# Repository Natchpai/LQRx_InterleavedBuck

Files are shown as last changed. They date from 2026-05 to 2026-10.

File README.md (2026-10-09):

# Digitally Controlled Interleaved Buck Converter




Digitally controlled **2-Phase Interleaved Synchronous Buck Converter** utilizing a state-space **Linear Quadratic Regulator** 
Optimized for time-critical embedded deployment at a switching frequency of **200 kHz** using the STM32G474 microcontroller.

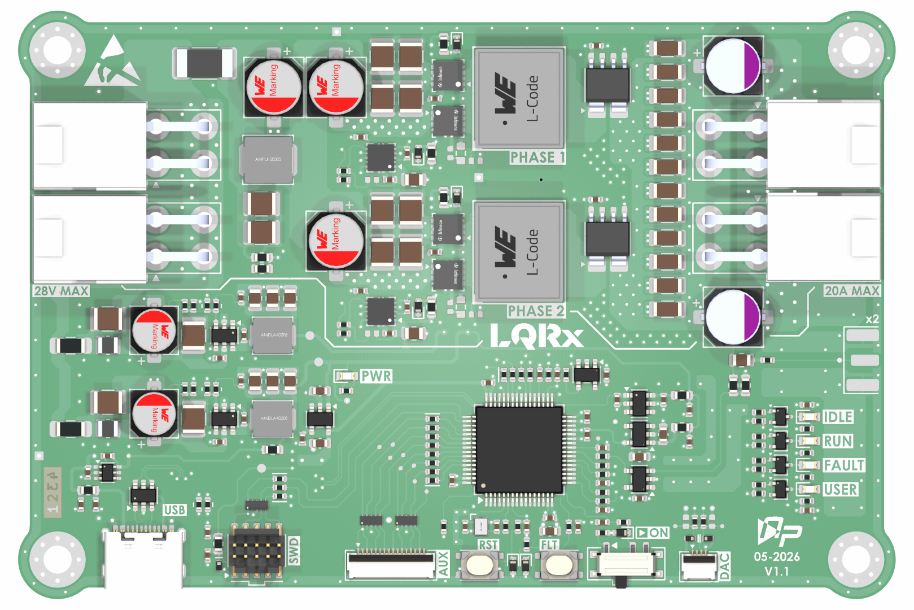
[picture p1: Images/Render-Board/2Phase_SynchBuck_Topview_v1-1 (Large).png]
Top Render
 

---

## 🚀 Key Features

*   **2-Phase Interleaved Topology:** Reduce input and output current ripples, yields a **400 kHz** equivalent ripple, allowing for smaller filter components.
*   **Augmented LQR Control:** Discrete-time State-space control , Integral Action and Delay Compensation.
*   **Hard Execution:** Optimized algorithms execute within **1.8 µs**, inside the 5 µs timing window of the switching cycle.

---

## 📊 Key Specifications

| Parameter | Nominal Value | Note |
| :--- | :--- | :--- |
| **Input Voltage ($V_{in}$)** | 24 VDC | 28V MAX  |
| **Output Voltage ($V_{out}$)** | 12 VDC | Regulated target reference ($V_{ref}$) can changed. |
| **Maximum Load Current** | 20 A (10A per phase) | Rated for **200W+** continuous output capability  |
| **Switching Frequency ($f_{sw}$)** | 200 kHz | **400 kHz** equivalent input/output ripple frequency due to 180° interleaving |
| **Controller Strategy** | State Feedback | Mathematical compensation for discrete execution delay  |
| **Firmware Execution Time** | $\approx 2.2\ \mu s$ | Executed completely within a $5\ \mu s$ timing window |

---

## Hardware

### Power Stage Components
* **High-Side MOSFET**: OptiMOS-6 BSZ018N04LS6
* **Low-Side MOSFET**: OptiMOS-6 IQE013N04LM6
* **Power Inductors**: $10\ \mu\text{H}$
* **Capacitors**: $140\ \mu\text{F}$
  
---

## Control Implementation
1.  **Digital Delay Augmentation:** Mathematically models and compensates for the computation and ADC sampling delays within the state vector to prevent phase-margin degradation.
2.  **Integral Action Augmentation:** Includes an augmented error-integral state to eliminate steady-state tracking error, forcing $V_{out} = V_{ref}$ under varying load conditions.

## License
Copyright (c) 2026 Natchpai.

The hardware design files are licensed under CERN-OHL-W-2.0.

The complete licence text is available in: </br>
[CERN Open Hardware Licence Version 2 - Weakly Reciprocal](LICENSE)  </br>

* **Project Developer** - *Core Hardware, Embedded Firmware & Control Design* - [@Natchpai](https://github.com/Natchpai)

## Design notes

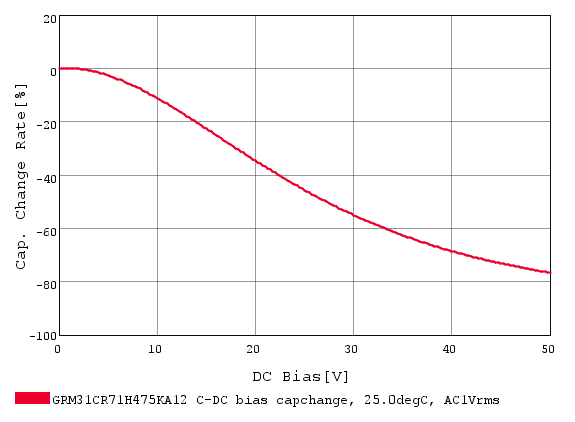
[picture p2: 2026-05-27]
Images/GRM31CR71H475KA12L-4u7F50V_DC-Derate.png

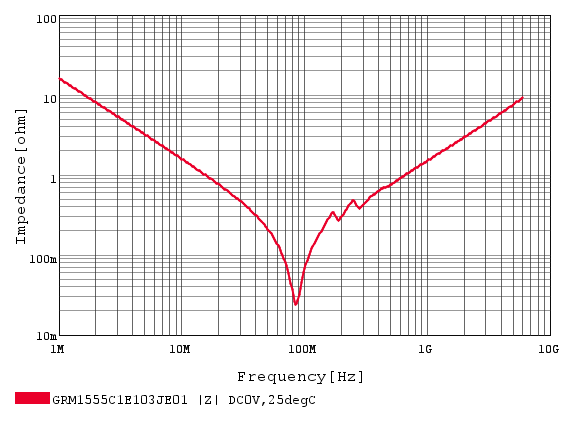
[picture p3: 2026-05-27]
Images/GRM1555C1E103JE01D.png

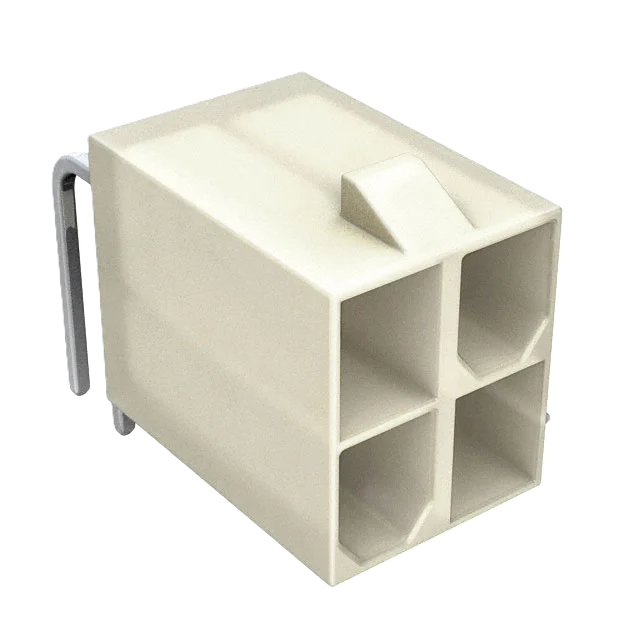
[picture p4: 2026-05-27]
Images/Mini-Fit Jr 5569 4 Position Natural-nonBg.png

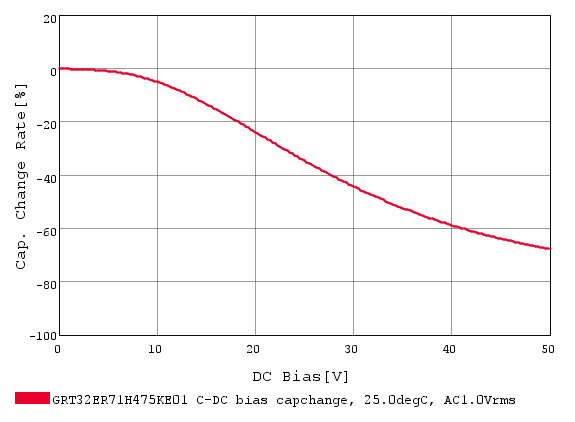
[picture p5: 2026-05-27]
Images/Murata Cap 4u7 50V/GCM32ER71H475MA55L.png

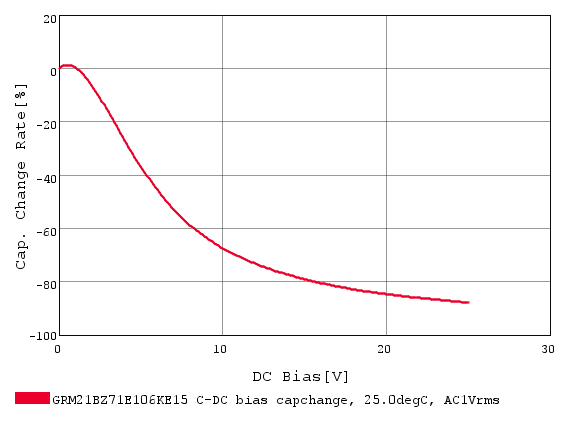
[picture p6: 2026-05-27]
Images/GRM21BZ71E106KE15L-10uF25V-Derating.png

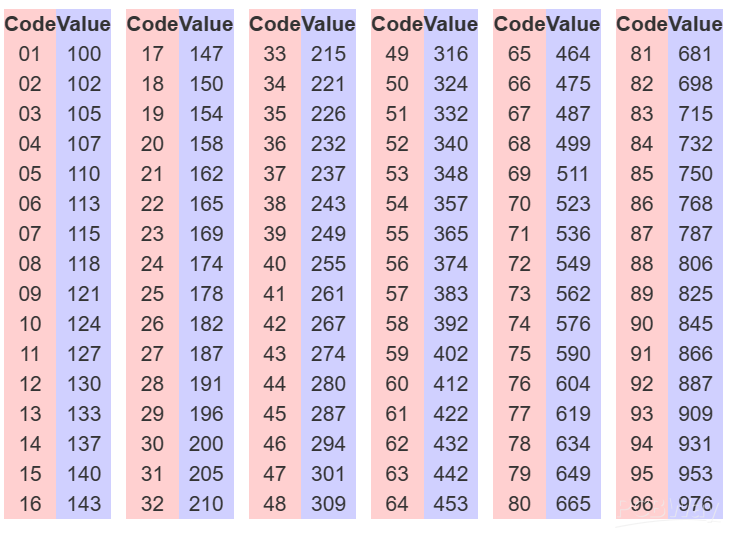
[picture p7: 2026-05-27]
Images/Resistor_E96.png

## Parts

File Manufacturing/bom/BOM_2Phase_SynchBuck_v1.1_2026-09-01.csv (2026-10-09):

# | Reference | Qty | Value | DNP | Exclude from BOM | Manufacturer | Manufacturer Part Number | Supplier Part Number | Supplier | Manufacturer 2nd | Manufacturer Part Number 2nd | Supplier Part Number 2nd | Supplier 2nd
1 | B901,B902 | 2 | SW_Tactile_PTS815SJM250 |  |  | C&K | PTS815SJM250SMTRLFS | CKN12215-1-ND | DigiKey
2 | C101,C102,C110,C111,C112,C113,C122,C123,C124,C125,C301,C303,C310,C312 | 14 | 4u7 |  |  | Murata | GRT32ER71H475KE01L | 490-GRT32ER71H475KE01LCT-ND | DigiKey
3 | C103,C104,C105 | 3 | 47u |  |  | Würth Elektronik | 865060543005 | 732-8585-1-ND | DigiKey
4 | C106,C118,C307,C308,C309,C316,C317,C318 | 8 | 4u7 |  |  | Murata | GRM21BZ7YA475KE15 | 490-GRM21BZ7YA475KE15LCT-ND | DigiKey
5 | C107,C108,C109,C114,C117,C119,C120,C121,C126,C129,C145,C304,C305,C306,C313,C314,C315,C320,C323,C325,C328,C329,C402,C403,C404,C405,C406,C407,C408,C409,C606,C607,C701,C702,C703,C704,C801,C802,C901,C902,C903 | 41 | 100n |  |  | Murata | GRM155R71H104KE14D | 490-10700-1-ND | DigiKey
6 | C130,C131,C132,C133,C134,C135,C137,C138,C139,C140,C141,C142 | 12 | 4u7 |  |  | Murata | GRM31CR71H475KA12 | 490-6521-1-ND | DigiKey
7 | C136,C143 | 2 | 47u |  |  | Panasonic | 35SVPK47M | P122127CT-ND | DigiKey
8 | C201 | 1 | 1u |  |  |  |  |  |  | Sumsung | CL21B105KBFNNNE |  | Electronics Source
9 | C302,C311 | 2 | 22u |  |  | Würth Elektronik | 865080542006 | 732-8505-1-ND | DigiKey
10 | C319,C321,C322,C324,C326,C327,C401 | 7 | 2u2 |  |  | Murata | GRM188Z71C225KE43 | 490-GRM188Z71C225KE43JCT-ND | DigiKey
11 | C501,C502 | 2 | 6p8 |  |  | Murata | GCM1555C1H6R8FA16D | 490-GCM1555C1H6R8FA16DCT-ND | DigiKey | Murata | GRM1555C1H6R8BA01D | 0160-0503-6 | Electronisc Source
12 | C601,C602,C603,C604,C605 | 5 | 1n |  |  | Murata | GRM1555C1H102JA01D | 490-3244-1-ND | DigiKey | Murata | GRM1555C1H102JA01D | 0160-0208-1 | Electronisc Source
13 | CN201,CN202,CN203,CN204 | 4 | 04A2 |  |  | Amphenol ICC | 10127819-04211LF | 609-4867-ND | DigiKey
14 | CN701 | 1 | USB4215-03-A |  |  | GCT | USB4215-03-A | 2073-USB4215-03-ACT-ND | DigiKey
15 | CN702 | 1 | Conn_JTAG_STDC10 |  |  | GCT | BD125-10-A-0305-0580-L-B | 2073-BD125-10-A-0305-0580-L-BCT-ND | DigiKey
16 | CN703 | 1 | FFC2B28-16-G |  |  | GCT | FFC2B28-16-G | 2073-FFC2B28-16-GCT-ND | DigiKey
17 | CN704 | 1 | FFC2B28-04-G |  |  | GCT | FFC2B28-04-G | 2073-FFC2B28-04-GCT-ND | DigiKey
18 | D101,D102,D103,D104 | 4 | BAT54XV2T5G |  |  | onsemi | BAT54XV2T5G | BAT54XV2T5GOSCT-ND | DigiKey
19 | D201,D202 | 2 | SMF4L28A |  |  | Littelfuse Inc. | SMF4L28A | F7483CT-ND | DigiKey
20 | D701,D705,D706 | 3 | SP3031-01ETG |  |  | Littelfuse Inc. | SP3031-01ETG | F5769CT-ND | DigiKey
21 | D702,D703,D704 | 3 | PUSB3FR4Z |  |  | Nexperia | PUSB3FR4Z | 1727-2026-1-ND | DigiKey
22 | D901,D902,D903 | 3 | ESD5Z3V3 |  |  | Diotec Semiconductor | ESD5Z3V3 | 4878-ESD5Z3V3CT-ND | DigiKey
23 | L101 | 1 | 1u |  |  | Abracon LLC | AMPLH5030S-1R0MT | 535-AMPLH5030S-1R0MTCT-ND | DigiKey
24 | L102,L103 | 2 | 10u |  |  | Würth Elektronik | 744393665100 | 732-744393665100CT-ND | DigiKey
25 | L301,L303 | 2 | 2u2 |  |  | Pulse Electronics | BDCD002016102R2MS1 | 553-BDCD002016102R2MS1CT-ND | DigiKey
26 | L302,L304 | 2 | 22u |  |  | Abracon LLC | AMDLA4020S-220MT | 535-AMDLA4020S-220MTCT-ND | DigiKey
27 | LD301,LD802 | 2 | Green |  |  |  |  |  |  | LITE-ON | LTST-C191TGKT | 0013-0123-1 | Electronisc Source
28 | LD801,LD804 | 2 | Orange |  |  |  |  |  |  | LITE-ON | LTST-C190KFKT | 0013-0112-6 | Electronisc Source
29 | LD803 | 1 | Red |  |  |  |  |  |  | LITE-ON | LTST-C191KRKT | 0013-0100-4 | Electronisc Source
30 | Q101,Q103 | 2 | BSZ018N04LS6 |  |  | Infineon Technologies | BSZ018N04LS6ATMA1 | 448-BSZ018N04LS6ATMA1CT-ND | DigiKey
31 | Q102,Q104 | 2 | IQE013N04LM6 |  |  | Infineon Technologies | IQE013N04LM6ATMA1 | 448-IQE013N04LM6ATMA1CT-ND | DigiKey
32 | Q801,Q802,Q803,Q804 | 4 | GS2N7002KW |  |  | Good-Ark | GS2N7002KW | 4786-GS2N7002KWCT-ND | DigiKey
33 | R101 | 1 | 5m |  |  | YAGEO | PA2512FKE7W0R005E | YAG6091CT-ND | DigiKey
34 | R102,R103,R501,R503,R504,R505,R506,R705,R706,R707,R708,R709,R710,R711,R712,R713,R714,R715,R716,R717 | 20 | 22R |  |  | YAGEO | RC0402FR-1322RL | 13-RC0402FR-1322RLCT-ND | DigiKey
35 | R105,R111,R604,R805,R806,R807,R808,R902 | 8 | 100R |  |  | YAGEO | RC0402FR-07100RL | 311-100LRCT-ND | DigiKey | ROYALOHM | CQ02WGF1000TCE | 0150-4399-1 | Electronisc Source
36 | R106,R112,R809,R810,R811,R812 | 6 | 100k |  |  | YAGEO | RC0402FR-07100KL | 311-100KLRCT-ND | DigiKey | ROYALOHM | CQ02WGF1003TCE | 0150-4421-7 | Electronisc Source
37 | R107,R108,R113,R114 | 4 | 2R21 |  |  |  |  |  |  | ROYALOHM | 0603WAF221KT5E | 0150-4758-2 | Electronisc Source
38 | R116,R118 | 2 | 90k9 |  |  | YAGEO | RC0603FR-0790K9L | 311-90.9KHRCT-ND | DigiKey | YAGEO | RC0603FR-079K09L | 0151-0863-5 | Electronisc Source
39 | R117,R119 | 2 | 10k |  |  | YAGEO | RC0603FR-0710KL | 311-10.0KHRCT-ND | DigiKey
40 | R201 | 1 | 1k |  |  | YAGEO | AC1206FR-7W1KL | 13-AC1206FR-7W1KLCT-ND | DigiKey
41 | R202,R507,R508,R601,R602,R603,R605 | 7 | 49R9 |  |  | YAGEO | RC0402FR-1349R9L | 13-RC0402FR-1349R9LCT-ND | DigiKey | ROYALOHM | 0402WGF499JTCE | 0150-4765-9 | Electronisc Source
42 | R301,R302 | 2 | 20m |  |  | YAGEO | PA1206FRE070R02Z | 13-PA1206FRE070R02ZCT-ND | DigiKey
43 | R303 | 1 | 162k |  |  | YAGEO | RC0402FR-07162KL | YAG2370CT-ND | DigiKey | ROYALOHM | 0402WGF1623TCE | 0150-4690-4 | Electronisc Source
44 | R304,R306,R308,R310 | 4 | 21k5 |  |  | YAGEO | RC0402FR-0721K5L | 311-21.5KLRCT-ND | DigiKey
45 | R305 | 1 | 221k |  |  | YAGEO | RC0402FR-07221KL | YAG3059CT-ND | DigiKey
46 | R307 | 1 | 110k |  |  | YAGEO | RC0402FR-07110KL | 311-110KLRCT-ND | DigiKey
47 | R309 | 1 | 118k |  |  | YAGEO | RC0402FR-07118KL | YAG2369CT-ND | DigiKey
48 | R311,R313,R401,R701,R704,R718,R719,R720,R721 | 9 | 0R |  |  | YAGEO | RC0603JR-070RL | 311-0.0GRCT-ND | DigiKey
49 | R312,R702,R703 | 3 | 5k11 |  |  | YAGEO | RC0402FR-135K11L | 13-RC0402FR-135K11LCT-ND | DigiKey | ROYALOHM | 0402WGF5111TCE | 0150-3609-4 | Electronisc Source
50 | R502,R802,R803,R903,R905 | 5 | 1k |  |  | YAGEO | RC0402FR-071KL | 311-1.00KLRCT-ND | DigiKey | ROYALOHM | 0402WGF1001TCE | 0150-3602-3 | Electronisc Source
51 | R801,R804 | 2 | 499 |  |  | YAGEO | RC0402FR-07499RL | 311-499LRCT-ND | DigiKey
52 | R901,R904 | 2 | 10k |  |  | YAGEO | RC0402FR-1010KL | 13-RC0402FR-1010KLCT-ND | DigiKey | ROYALOHM | 0402WGF1002TCE | 0150-3250-7 | Electronisc Source
53 | SW901 | 1 | SW_SPDT |  |  |  |  |  |  | DAWNING PRECISION | SS-B90AP-W-SP2-S085 | 1512-0003-4 | Electronisc Source
54 | U101,U103 | 2 | UCC27282DRC |  |  | Texas Instruments | UCC27282DRCT | 296-53422-1-ND | DigiKey
55 | U102,U104 | 2 | ACS37030LLZATR-040B3 |  |  | Allegro MicroSystems | ACS37030LLZATR-040B3 | 620-ACS37030LLZATR-040B3CT-ND | DigiKey
56 | U106 | 1 | INA187A1IDBVR |  |  | Texas Instruments | INA187A1IDBVR | 296-INA187A1IDBVRCT-ND | DigiKey
57 | U301,U302 | 2 | LMR54410DBVR |  |  | Texas Instruments | LMR54410DBVR | 296-LMR54410DBVRCT-ND | DigiKey
58 | U303,U304 | 2 | SPX3819M5-L-3-3/TR |  |  | MaxLinear | SPX3819M5-L-3-3/TR | 1016-1873-1-ND | DigiKey
59 | U305 | 1 | LDLN025M33R |  |  | STMicroelectronics | LDLN025M33R | 497-17777-1-ND | DigiKey
60 | U306 | 1 | LM66100DCK |  |  | Texas Instruments | LM66100DCK | 296-53540-1-ND | DigiKey
61 | U401 | 1 | STM32G474RET6 |  |  | STMicroelectronics | STM32G474RET6 | 497-STM32G474RET6-ND | DigiKey
62 | U402 | 1 | MCP1501T-30E |  |  | Microchip Technology | MCP1501T-30E | MCP1501T-30E/CHYCT-ND | DigiKey
63 | U601,U602 | 2 | TLV9061IDBVR |  |  | Texas Instruments | TLV9061IDBVR | 296-52284-1-ND | DigiKey
64 | U701 | 1 | USBLC6-2SC6 |  |  | STMicroelectronics | USBLC6-2SC6 | 497-5235-1-ND | DigiKey
65 | X501 | 1 | ABM11W-24MHz-8 |  |  | Abracon LLC | ABM11W-24.0000MHZ-8-B1U-T3 | 535-13834-1-ND | DigiKey

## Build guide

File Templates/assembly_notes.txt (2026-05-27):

ASSEMBLY NOTES (UNLESS OTHERWISE SPECIFIED)

1)	DO NOT POPULATE PARTS ARE MARKED WITH A RED CROSS.

2)	DO NOT POPULATE PARTS ARE NOT PRESENT IN THE BOM.

3)	IF CONFLICTING INFORMATION IS FOUND BETWEEN THE ASSEMBLY
	FILE AND BOM, BOM SHOULD BE USED AS THE MAIN SOURCE.

4)	CONFORMAL COATING IS NOT REQUIRED.

5)	DOT IDENTIFIES PIN #1 LOCATION AND DEVICE ORIENTATION
	WHEN VIEWED FROM THE TOP.

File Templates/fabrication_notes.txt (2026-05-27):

FABRICATION NOTES (UNLESS OTHERWISE SPECIFIED)

1)	FABRICATE PER IPC-6012A CLASS 2.

2)	OUTLINE DEFINED IN SEPARATE GERBER FILE WITH
	"Edge_Cuts.GBR" SUFFIX.

	DIMENSIONS OF CIRCUMSIZED RECTANGLE SHOWN ON THIS
	DRAWING FOR REFERENCE ONLY.

3)	SEE SEPARATE DRILL FILES WITH ".DRL" SUFFIX 
	FOR HOLE LOCATIONS.

	SELECTED HOLE LOCATIONS SHOWN ON THIS DRAWING 
	FOR REFERENCE ONLY.

4)	SURFACE FINISH: ${pcb_finish_cap}

5)	SOLDERMASK ON BOTH SIDES OF THE BOARD SHALL 
	BE LPI, COLOR ${solder_mask_color_text_cap}.

6)	SILK SCREEN LEGEND TO BE APPLIED PER LAYER 
	STACKUP USING ${silk_screen_color_text_cap} NON-CONDUCTIVE EPOXY INK.

7)	ALL VIAS ARE TENTED ON BOTH SIDES UNLESS 
	SOLDERMASK OPENED IN GERBER.

8)	VENDOR SHOULD FOLLOW ROHS COMPLIANT PROCESS 
	AND Pb FREE FOR MANUFACTURING

9)	PCB MATERIAL REQUIREMENTS:

	A.	FLAMMABILITY RATING MUST MEET OR EXCEED 
		UL94V-0 REQUIREMENTS.
	B.	Tg 170 C OR EQUIVALENT.
	C.	EQUIVALENT MATERIAL SHALL BE RoHS COMPLIANT, 
		HALOGEN FREE AND APPROVED BY ${COMPANY_cap}.

10)	DESIGN GEOMETRY MINIMUM FEATURE SIZES:

	BOARD SIZE				${bb_w_mm} × ${bb_h_mm} mm
	BOARD THICKNESS		${thickness_mm} mm
	TRACE WIDTH			${track_mm} mm
	TRACE TO TRACE		${clearance_mm} mm
	MIN. HOLE (PTH)			${drill_pth_real_mm} mm
	MIN. HOLE (NPTH)		${drill_npth_real_mm} mm
	ANNULAR RING			${oar_mm} mm
	COPPER TO HOLE		${c2h_mm} mm
	COPPER TO EDGE		${c2e_mm} mm
	HOLE TO HOLE			${h2h_mm} mm
#?stackup and impedance_controlled

#?stackup and impedance_controlled
11)	REFER TO IMPEDANCE TABLE FOR IMPEDANCE CONTROL REQUIREMENTS.
#?stackup and impedance_controlled

#?stackup and impedance_controlled
12)	CONFIRM SPACE WIDTHS AND SPACINGS.

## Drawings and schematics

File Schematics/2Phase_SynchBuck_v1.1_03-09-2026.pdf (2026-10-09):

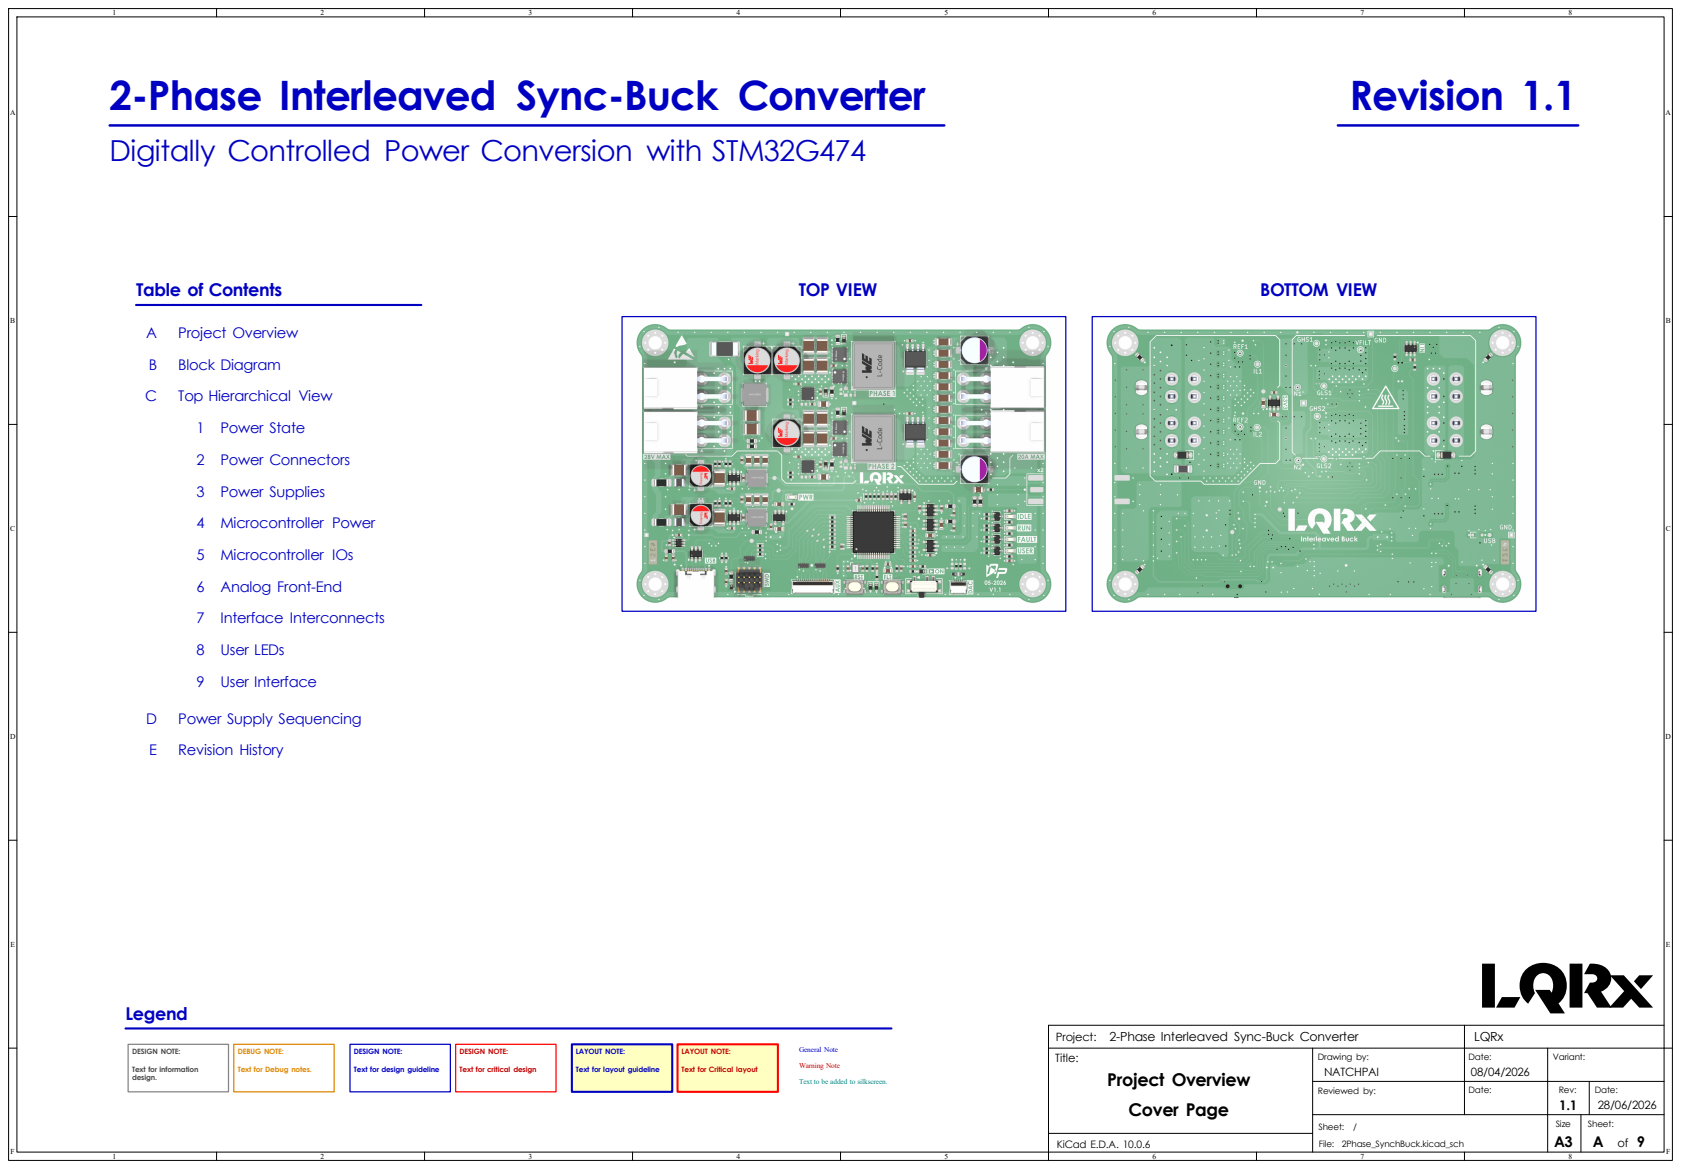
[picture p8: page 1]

2-Phase Interleaved Sync-Buck Converter
Digitally Controlled Power Conversion with STM32G474

General Note Warning Note Power Supplies

Text to be added to silkscreen. Microcontroller Power
Analog Front-End

Project Overview
Cover Page

LAYOUT NOTE: Text for Critical layout

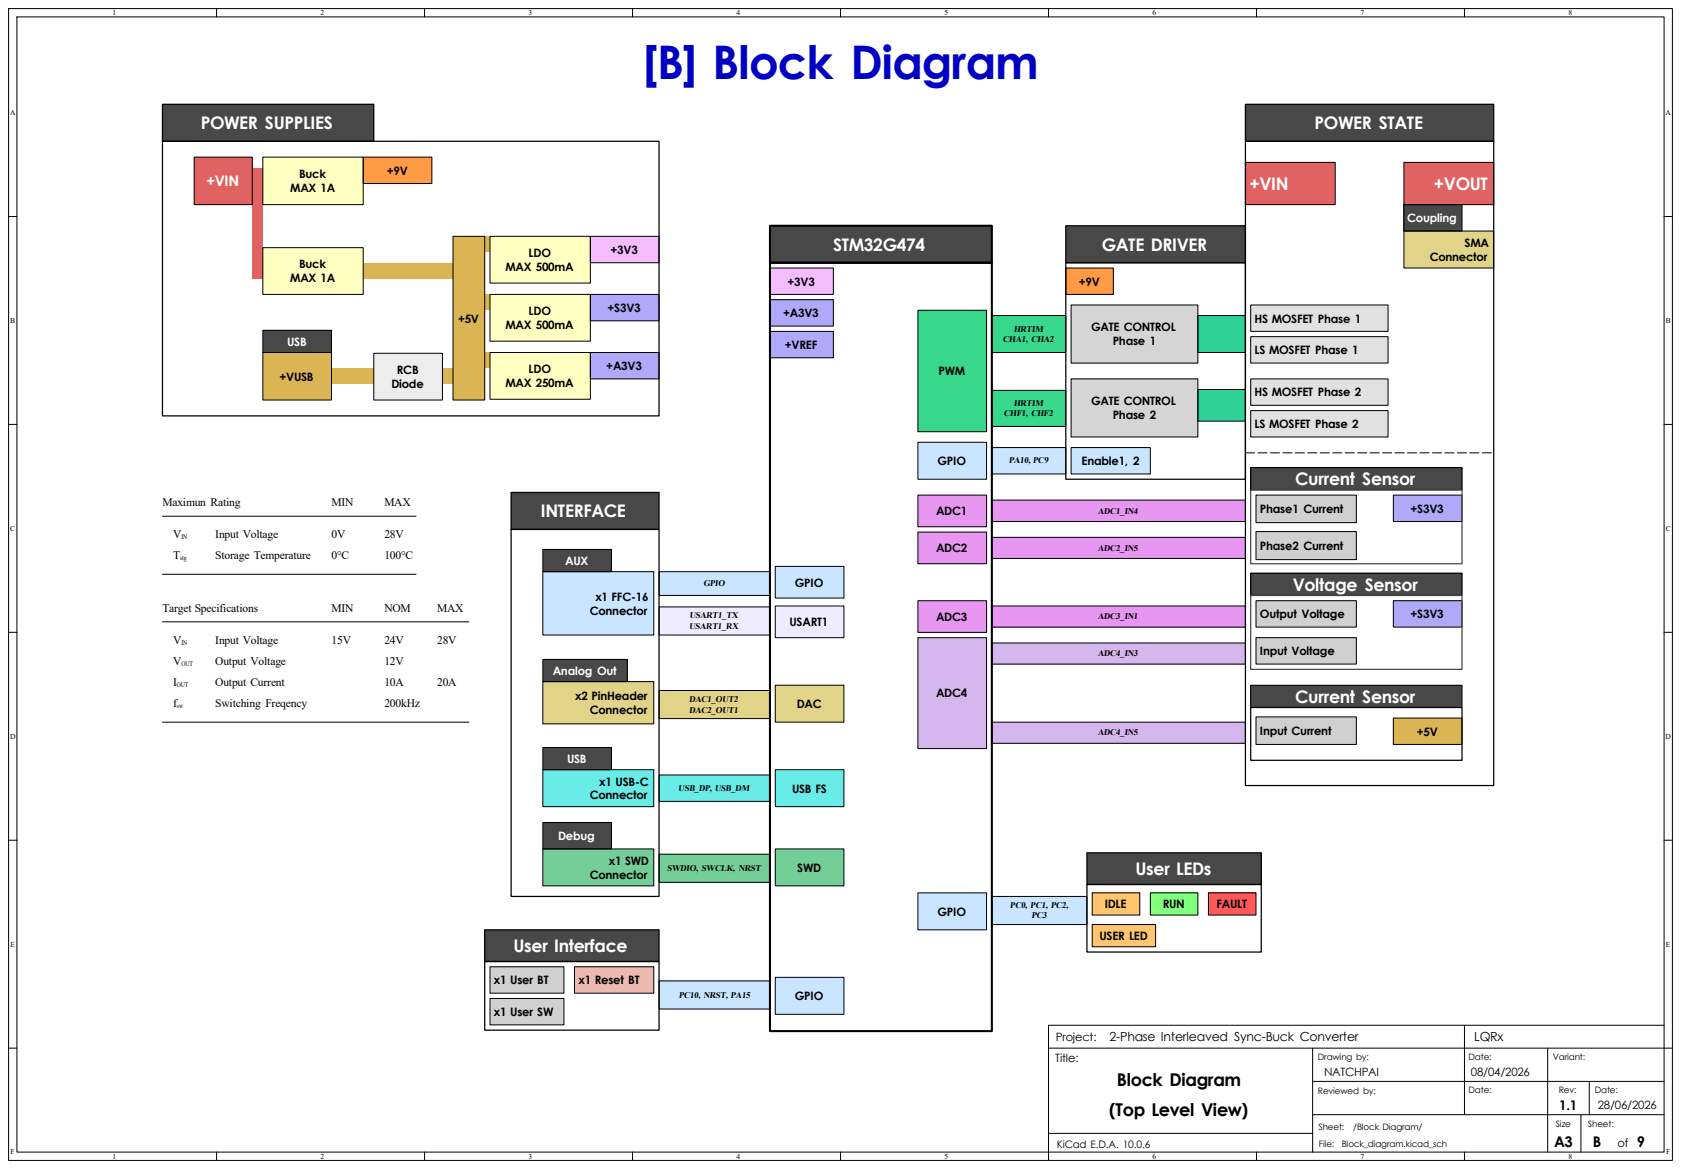
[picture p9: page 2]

2-Phase Interleaved Sync-Buck Converter
Block Diagram
(Top Level View)

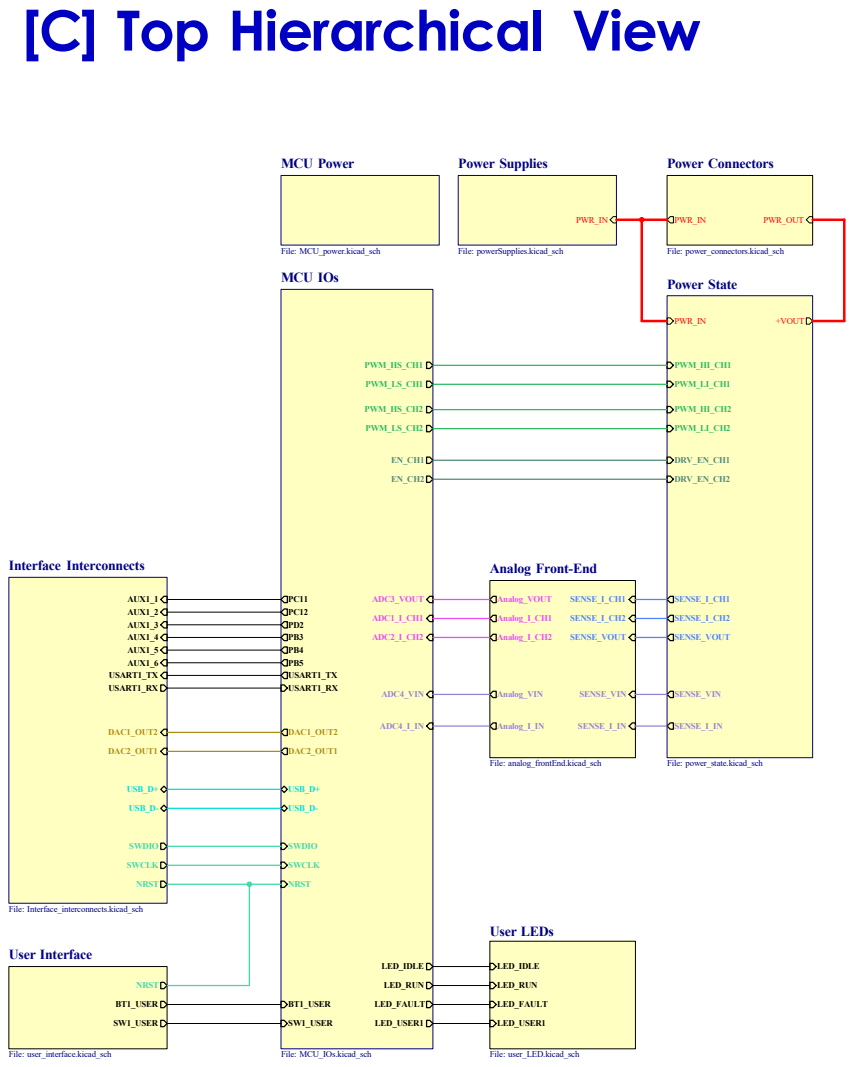
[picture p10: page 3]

2-Phase Interleaved Sync-Buck Converter
Top Hierarchical View
(Top Level View)

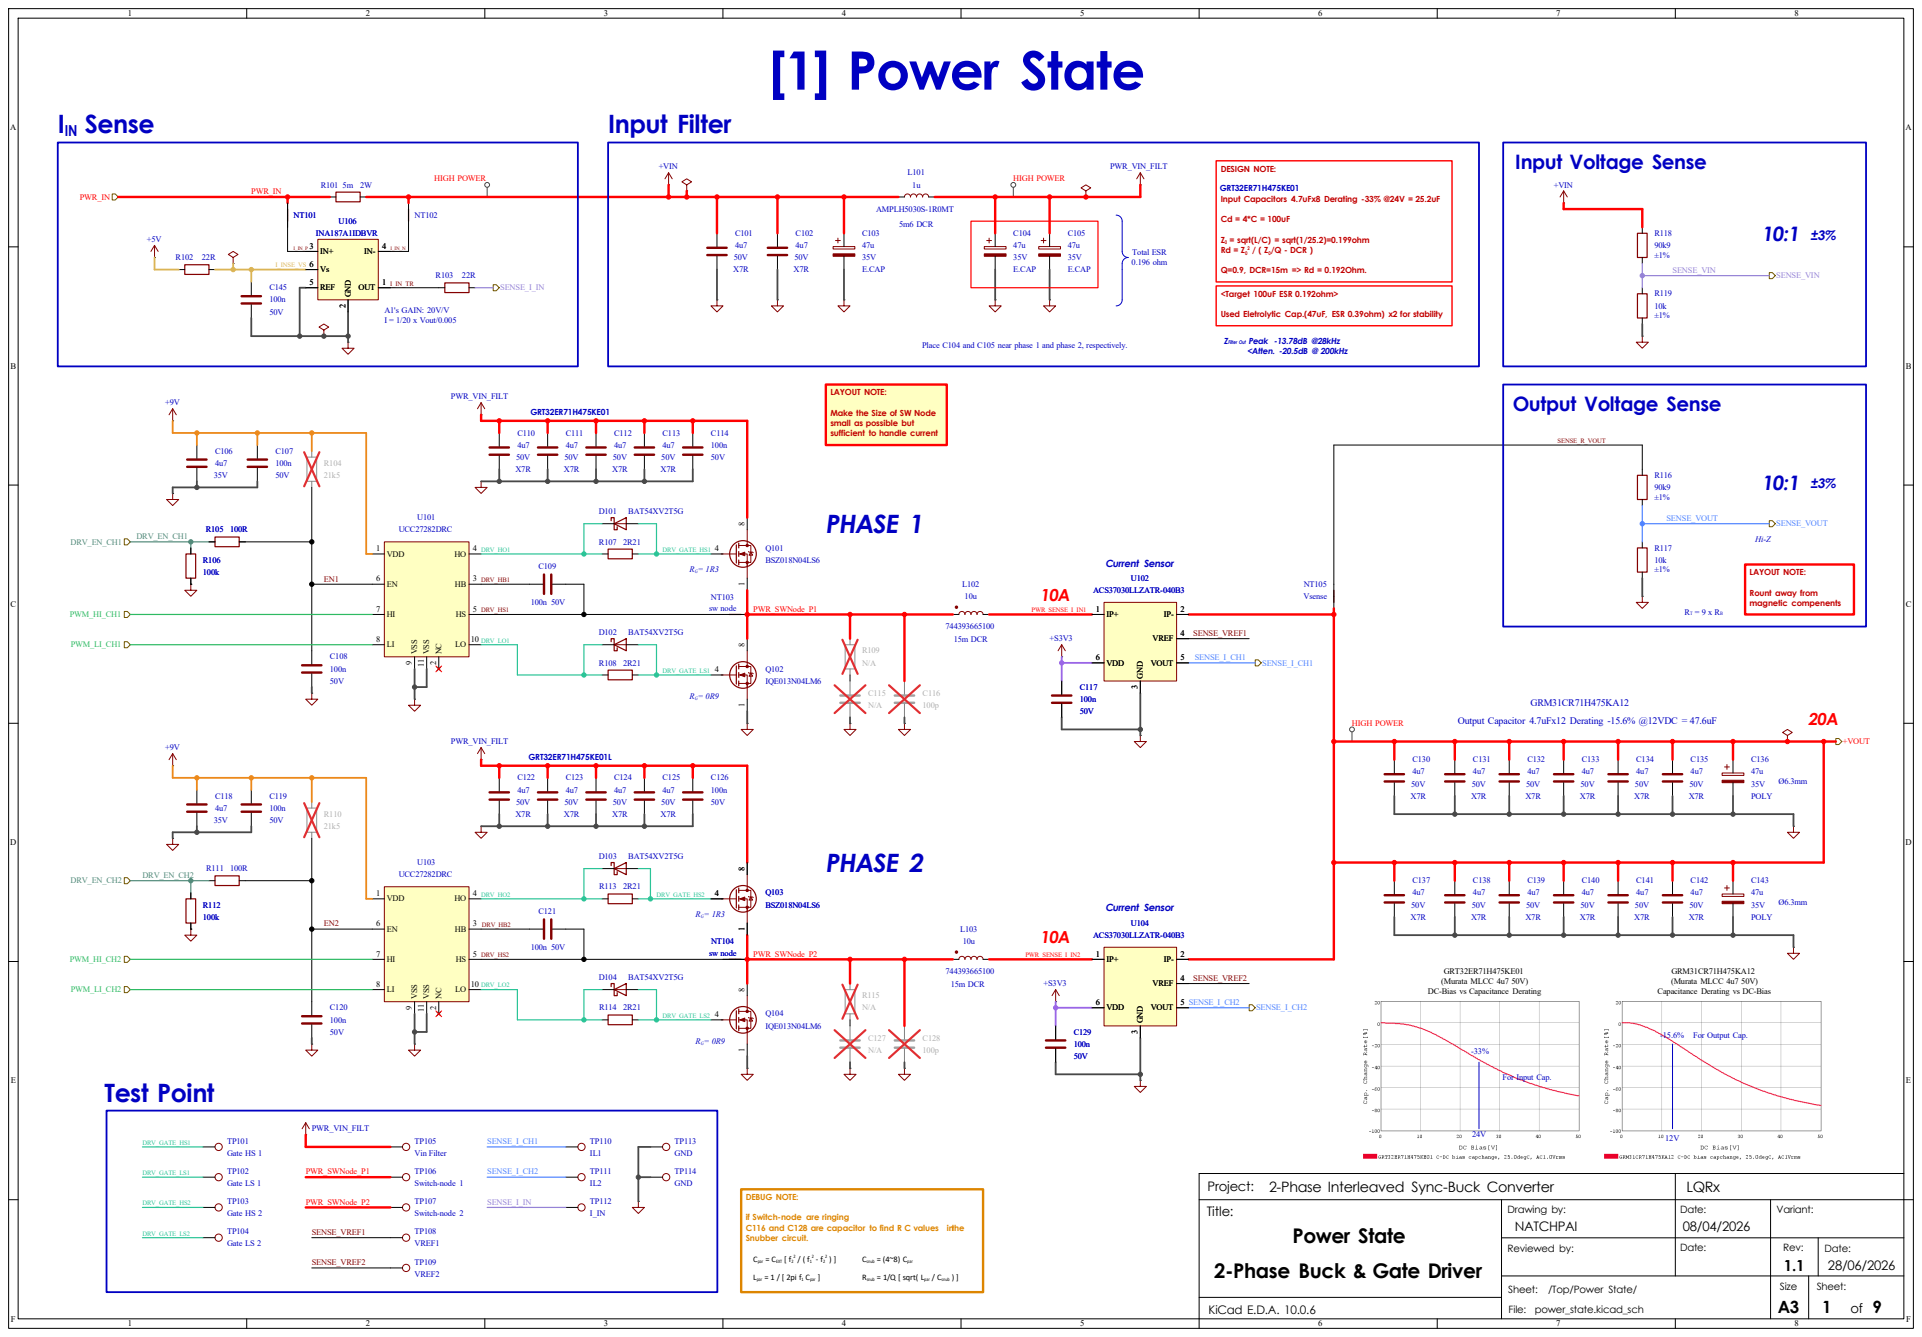
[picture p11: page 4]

2 / ( Z0/Q - DCR ) Q=0.9, DCR=15m => Rd = 0.192Ohm. GRT32ER71H475KE01
Input Capacitors 4.7uFx8 Derating -33% @24V = 25.2uF Cd = 4*C = 100uF Z0 = sqrt(L/C) = sqrt(1/25.2)=0.199ohm

<Target 100uF ESR 0.192ohm> Used Eletrolytic Cap.(47uF, ESR 0.39ohm) x2 for stability

ZFilter Out Peak -13.78dB @28kHz <Atten. -20.5dB @ 200kHz

LAYOUT NOTE: Make the Size of SW Node

small as possible but sufficient to handle current

2 HB 3 HO 4 HS 5 EN 6 HI 7 LI 8 VSS

LAYOUT NOTE: Rount away from

Output Capacitor 4.7uFx12 Derating -15.6% @12VDC = 47.6uF RT = 9 x RB RG= 1R3

GRT32ER71H475KE01
(Murata MLCC 4u7 50V) DC-Bias vs Capacitance Derating

TP101 Gate HS 1 TP102 Gate LS 1

2-Phase Interleaved Sync-Buck Converter
Power State

if Switch-node are ringing C116 and C128 are capacitor to find R C values in the

2-Phase Buck & Gate Driver

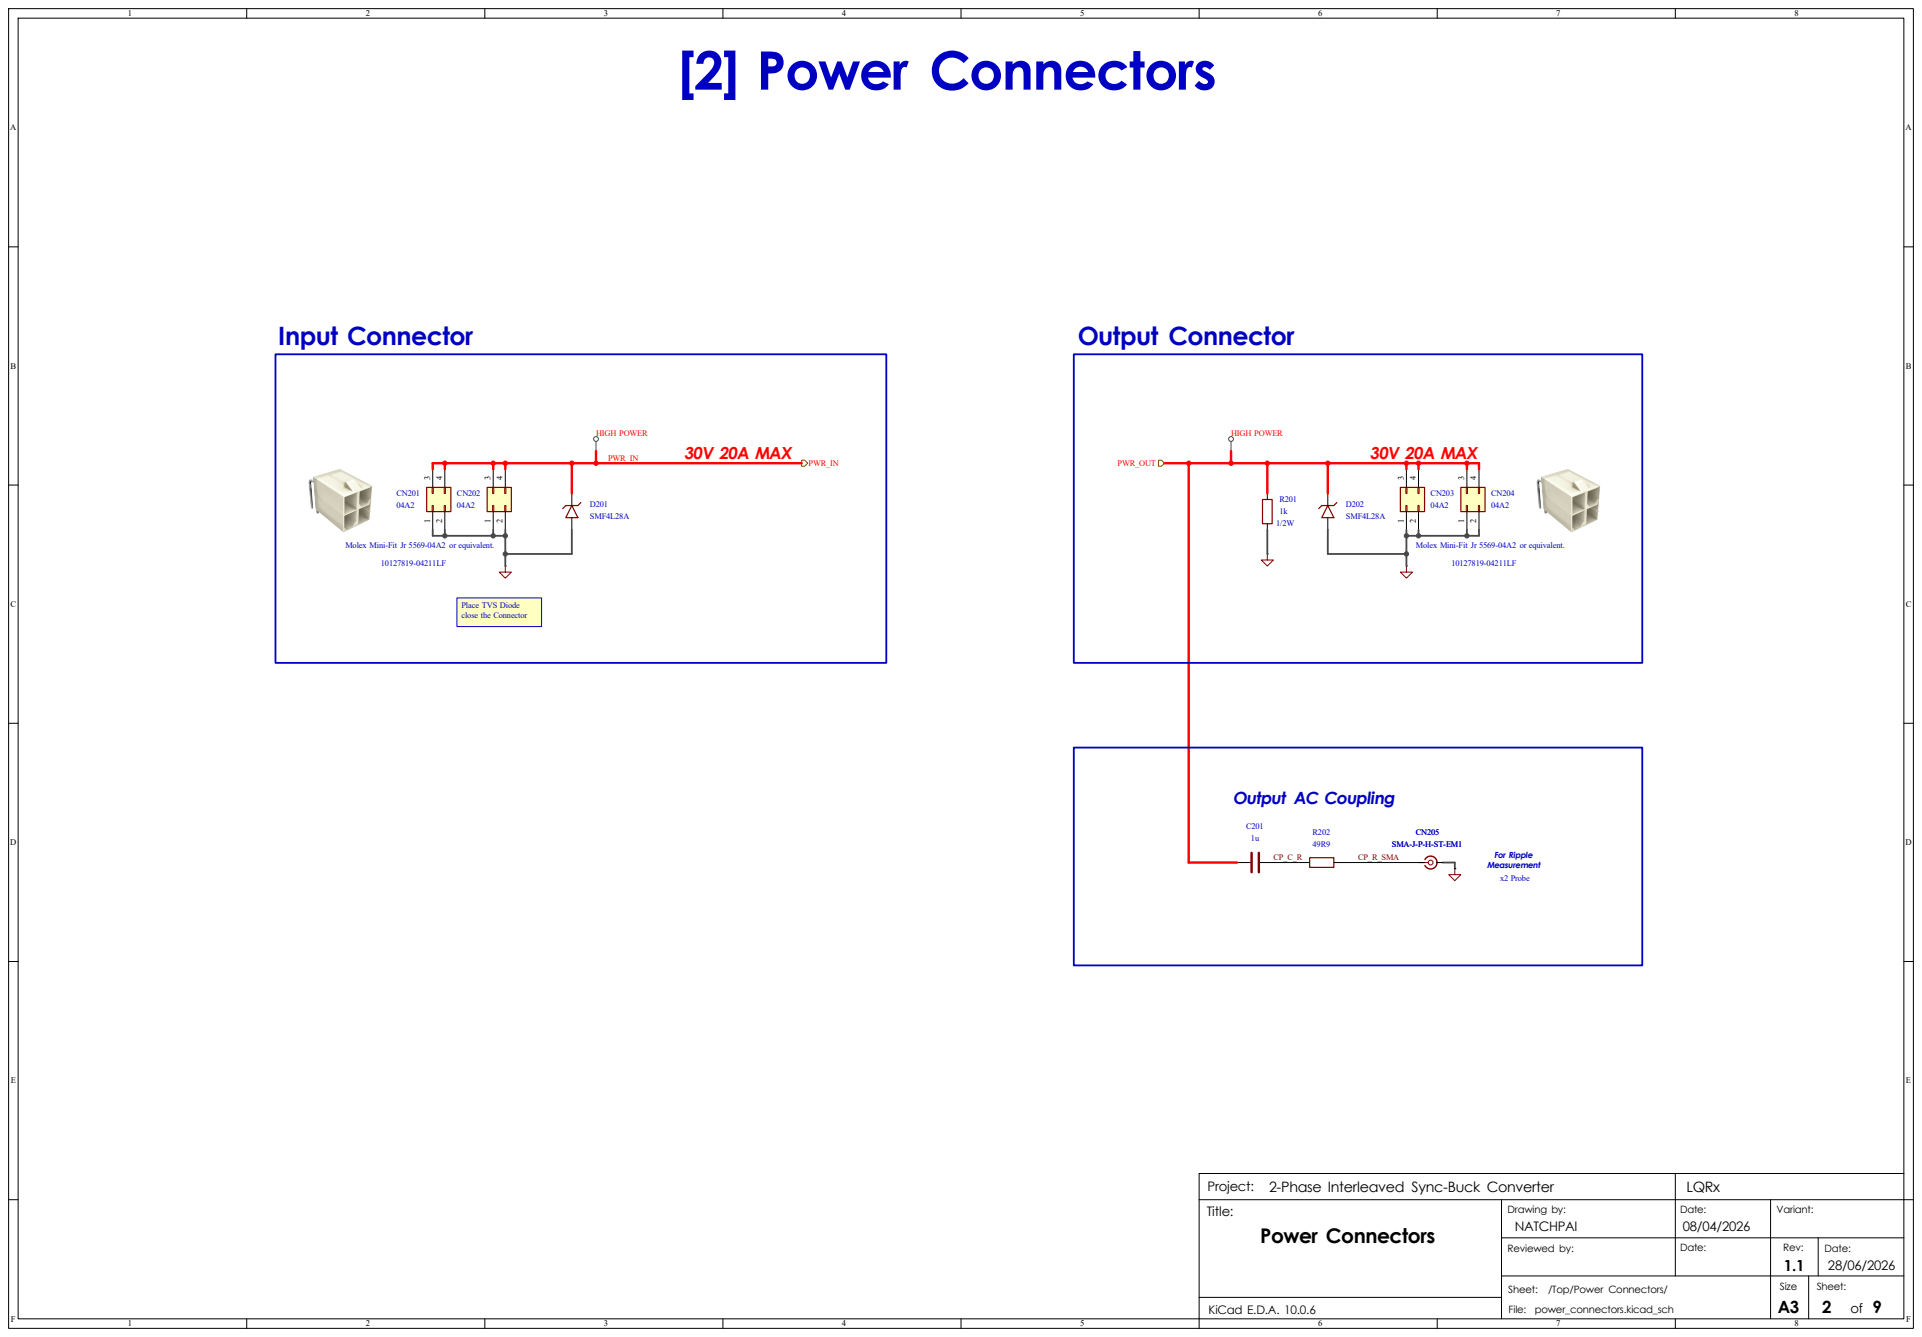
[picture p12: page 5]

x2 Probe Molex Mini-Fit Jr 5569-04A2 or equivalent.

Molex Mini-Fit Jr 5569-04A2 or equivalent. 10127819-04211LF

For Ripple Measurement CN205 SMA-J-P-H-ST-EM1

2-Phase Interleaved Sync-Buck Converter
Power Connectors

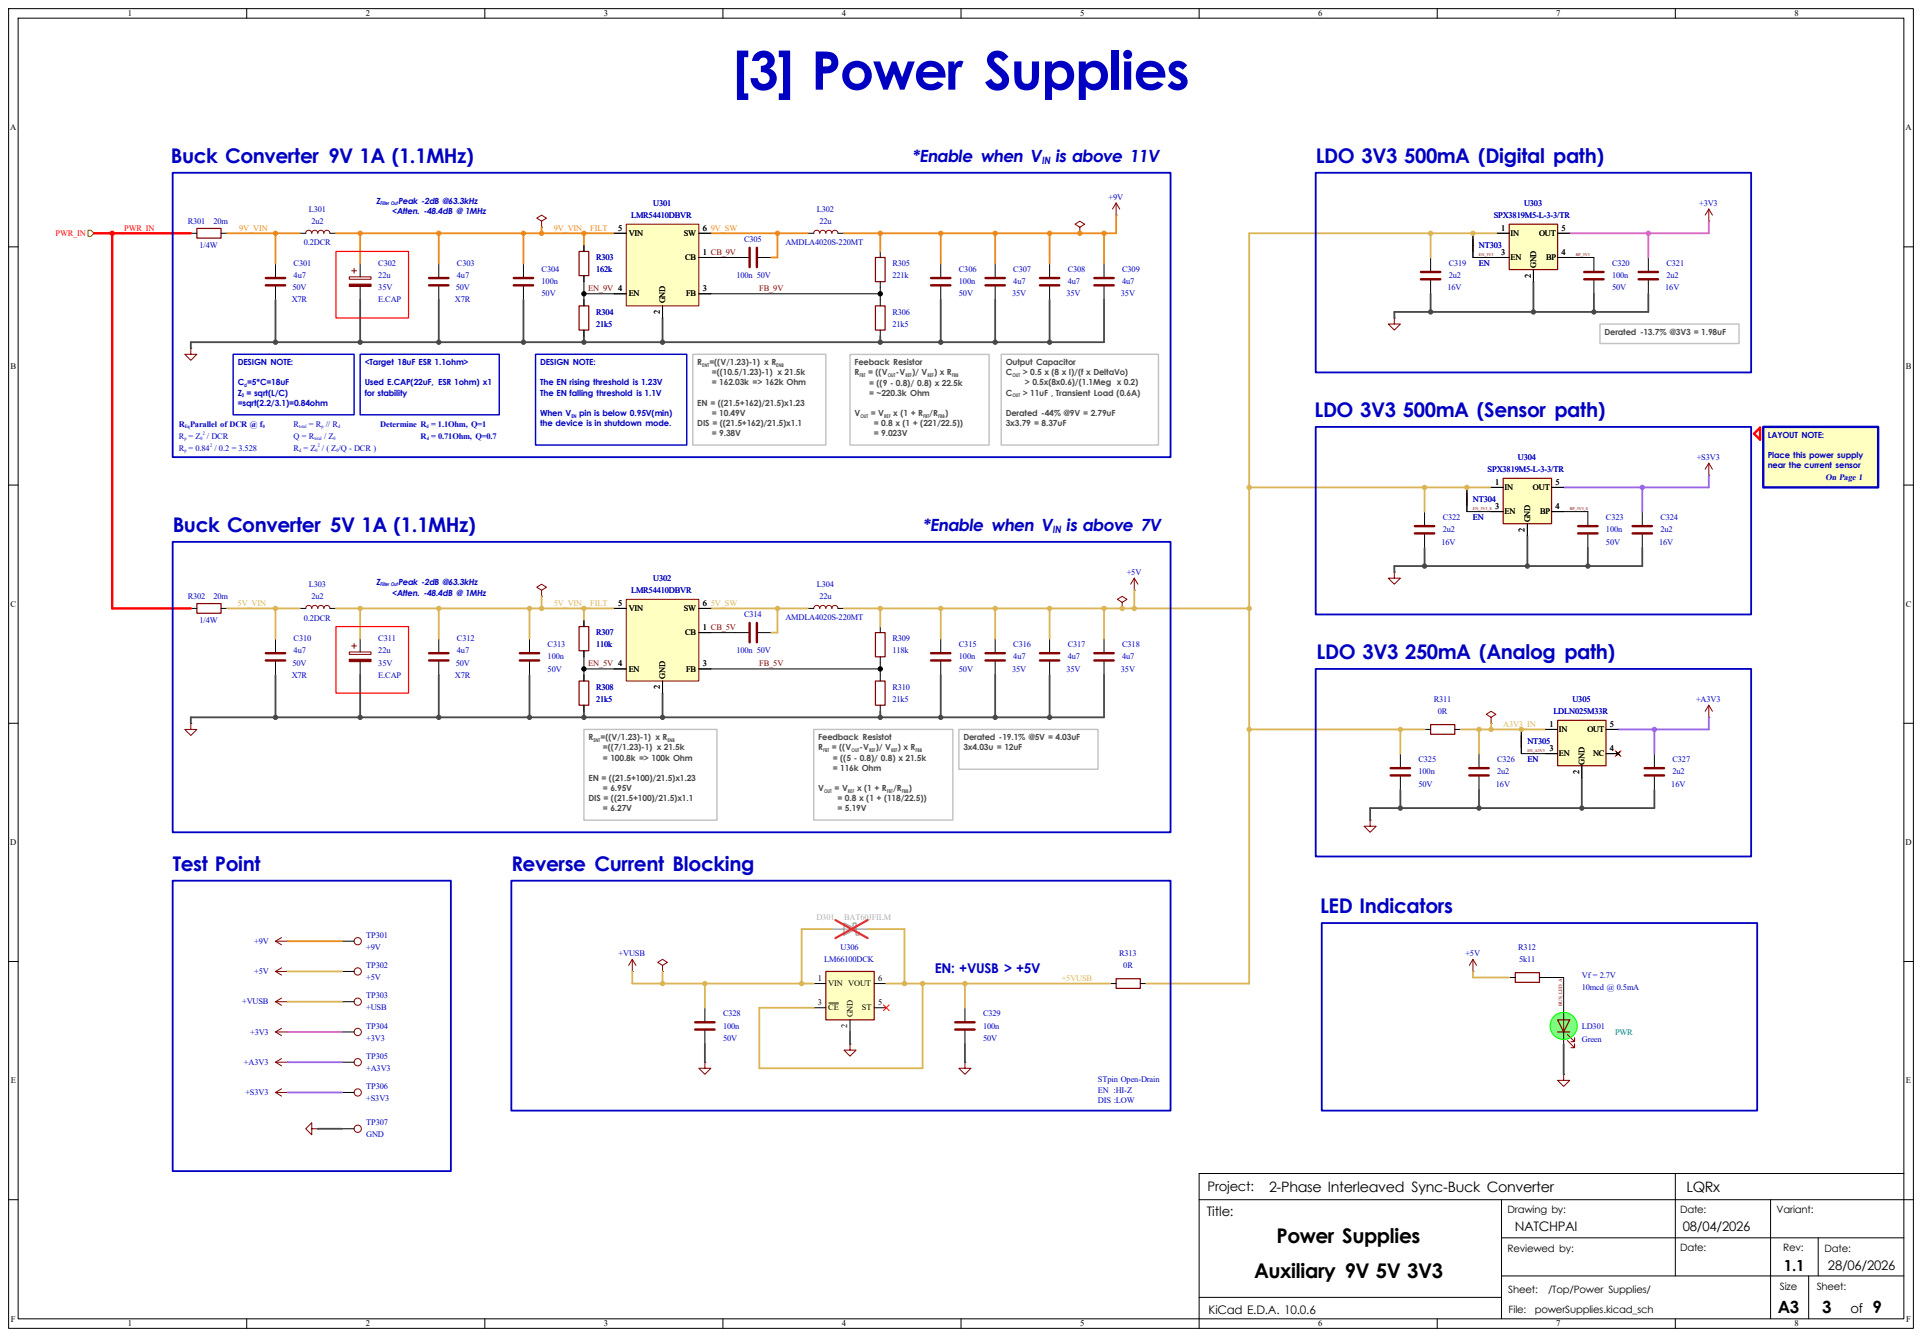
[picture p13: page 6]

*Enable when VIN is above 11V

2 FB 3 EN 4 VIN 5 SW 6 U301 LMR54410DBVR

2 EN 3 BP 4 OUT 5 U303 SPX3819M5-L-3-3/TR
BP_3V3 BUS_LED_A

2 EN 3 BP 4 OUT 5 NT305 EN

Derated -13.7% @3V3 = 1.98uF DESIGN NOTE: The EN rising threshold is 1.23V

Output Capacitor COUT > 0.5 x (8 x I)/(f x DeltaVo) > 0.5x(8x0.6)/(1.1Meg x 0.2) COUT > 11uF , Transient Load (0.6A) Derated -44% @9V = 2.79uF 3x3.79 = 8.37uF DESIGN NOTE: Cd=5*C=18uF Z0 = sqrt(L/C)

<Target 18uF ESR 1.1ohm> Used E.CAP(22uF, ESR 1ohm) x1

Feeback Resistor RFBT = ((VOUT-VREF)/ VREF) x RFBB = ((9 - 0.8)/ 0.8) x 22.5k = ~220.3k Ohm

The EN falling threshold is 1.1V When VEN pin is below 0.95V(min)

VOUT = VREF x (1 + RFBT/RFBB) = 0.8 x (1 + (221/22.5)) = 9.023V

2 EN 3 BP 4 OUT 5 U304 SPX3819M5-L-3-3/TR

2 EN 3 BP 4 OUT 5 NT304 EN

2 FB 3 EN 4 VIN 5 SW 6 U302 LMR54410DBVR

2 FB 3 EN 4 VIN 5 SW 6 R307

Feedback Resistot RFBT = ((VOUT-VREF)/ VREF) x RFBB = ((5 - 0.8)/ 0.8) x 21.5k = 116k Ohm

VOUT = VREF x (1 + RFBT/RFBB) = 0.8 x (1 + (118/22.5)) = 5.19V

STpin Open-Drain EN :HI-Z DIS :LOW

2-Phase Interleaved Sync-Buck Converter
Power Supplies
Auxiliary 9V 5V 3V3

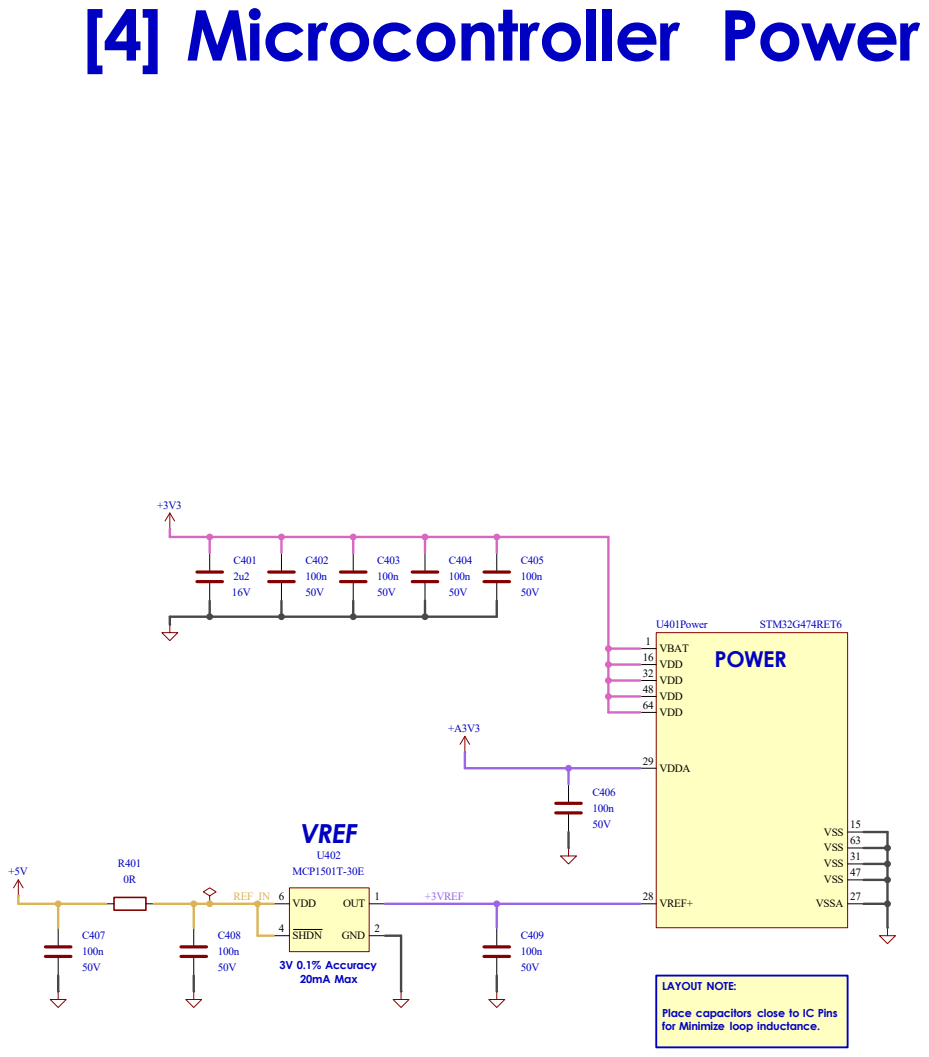
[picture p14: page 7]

for Minimize loop inductance. [4] Microcontroller Power

LAYOUT NOTE: Place capacitors close to IC Pins

2-Phase Interleaved Sync-Buck Converter
Microcontroller Power
STM32G474Rx

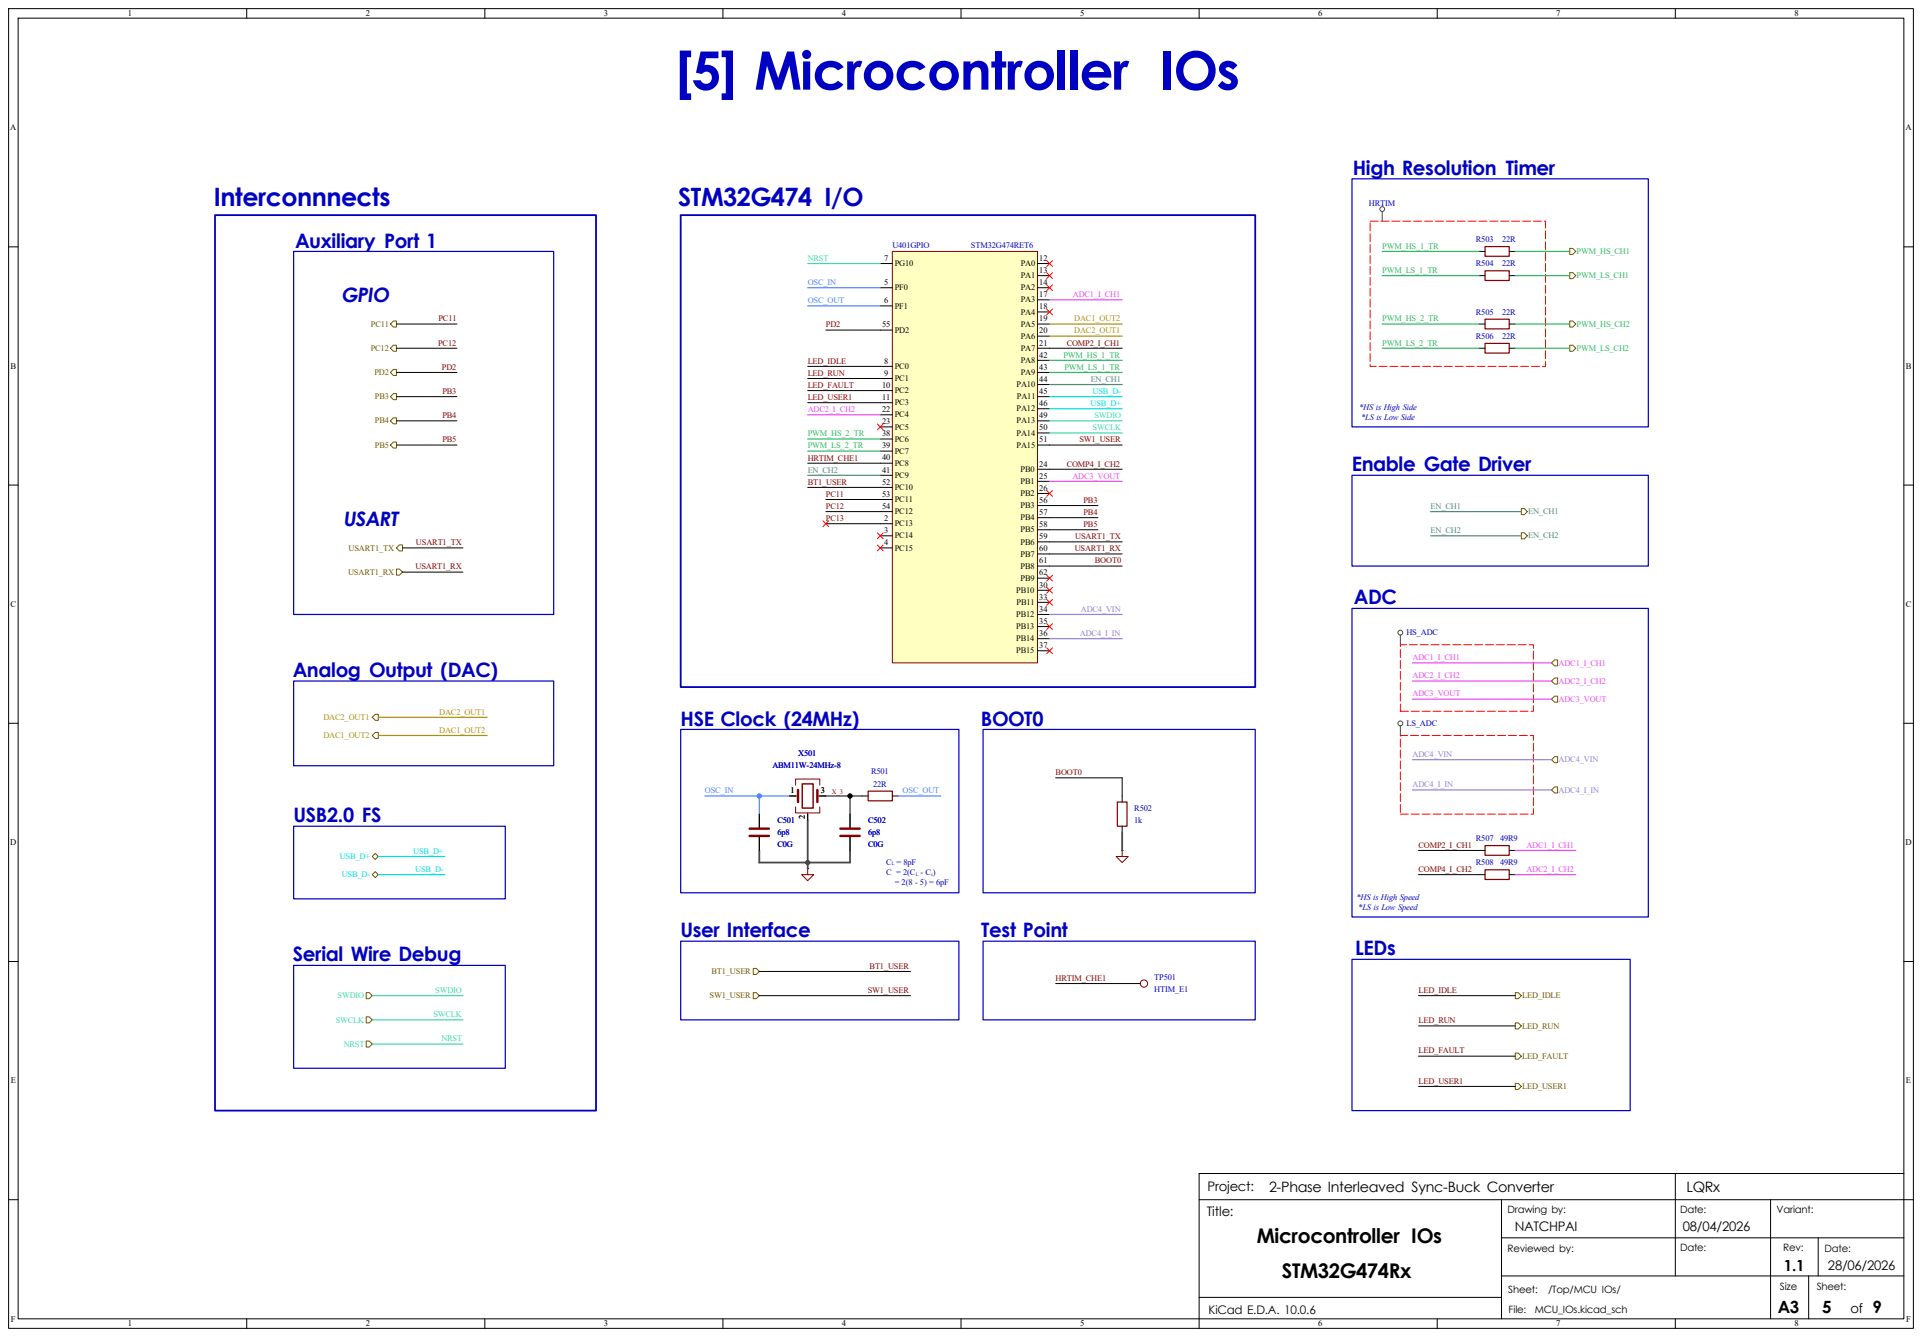
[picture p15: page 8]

*HS is High Side *LS is Low Side USART

*HS is High Speed
*LS is Low Speed
LEDs

2-Phase Interleaved Sync-Buck Converter
Microcontroller IOs
STM32G474Rx

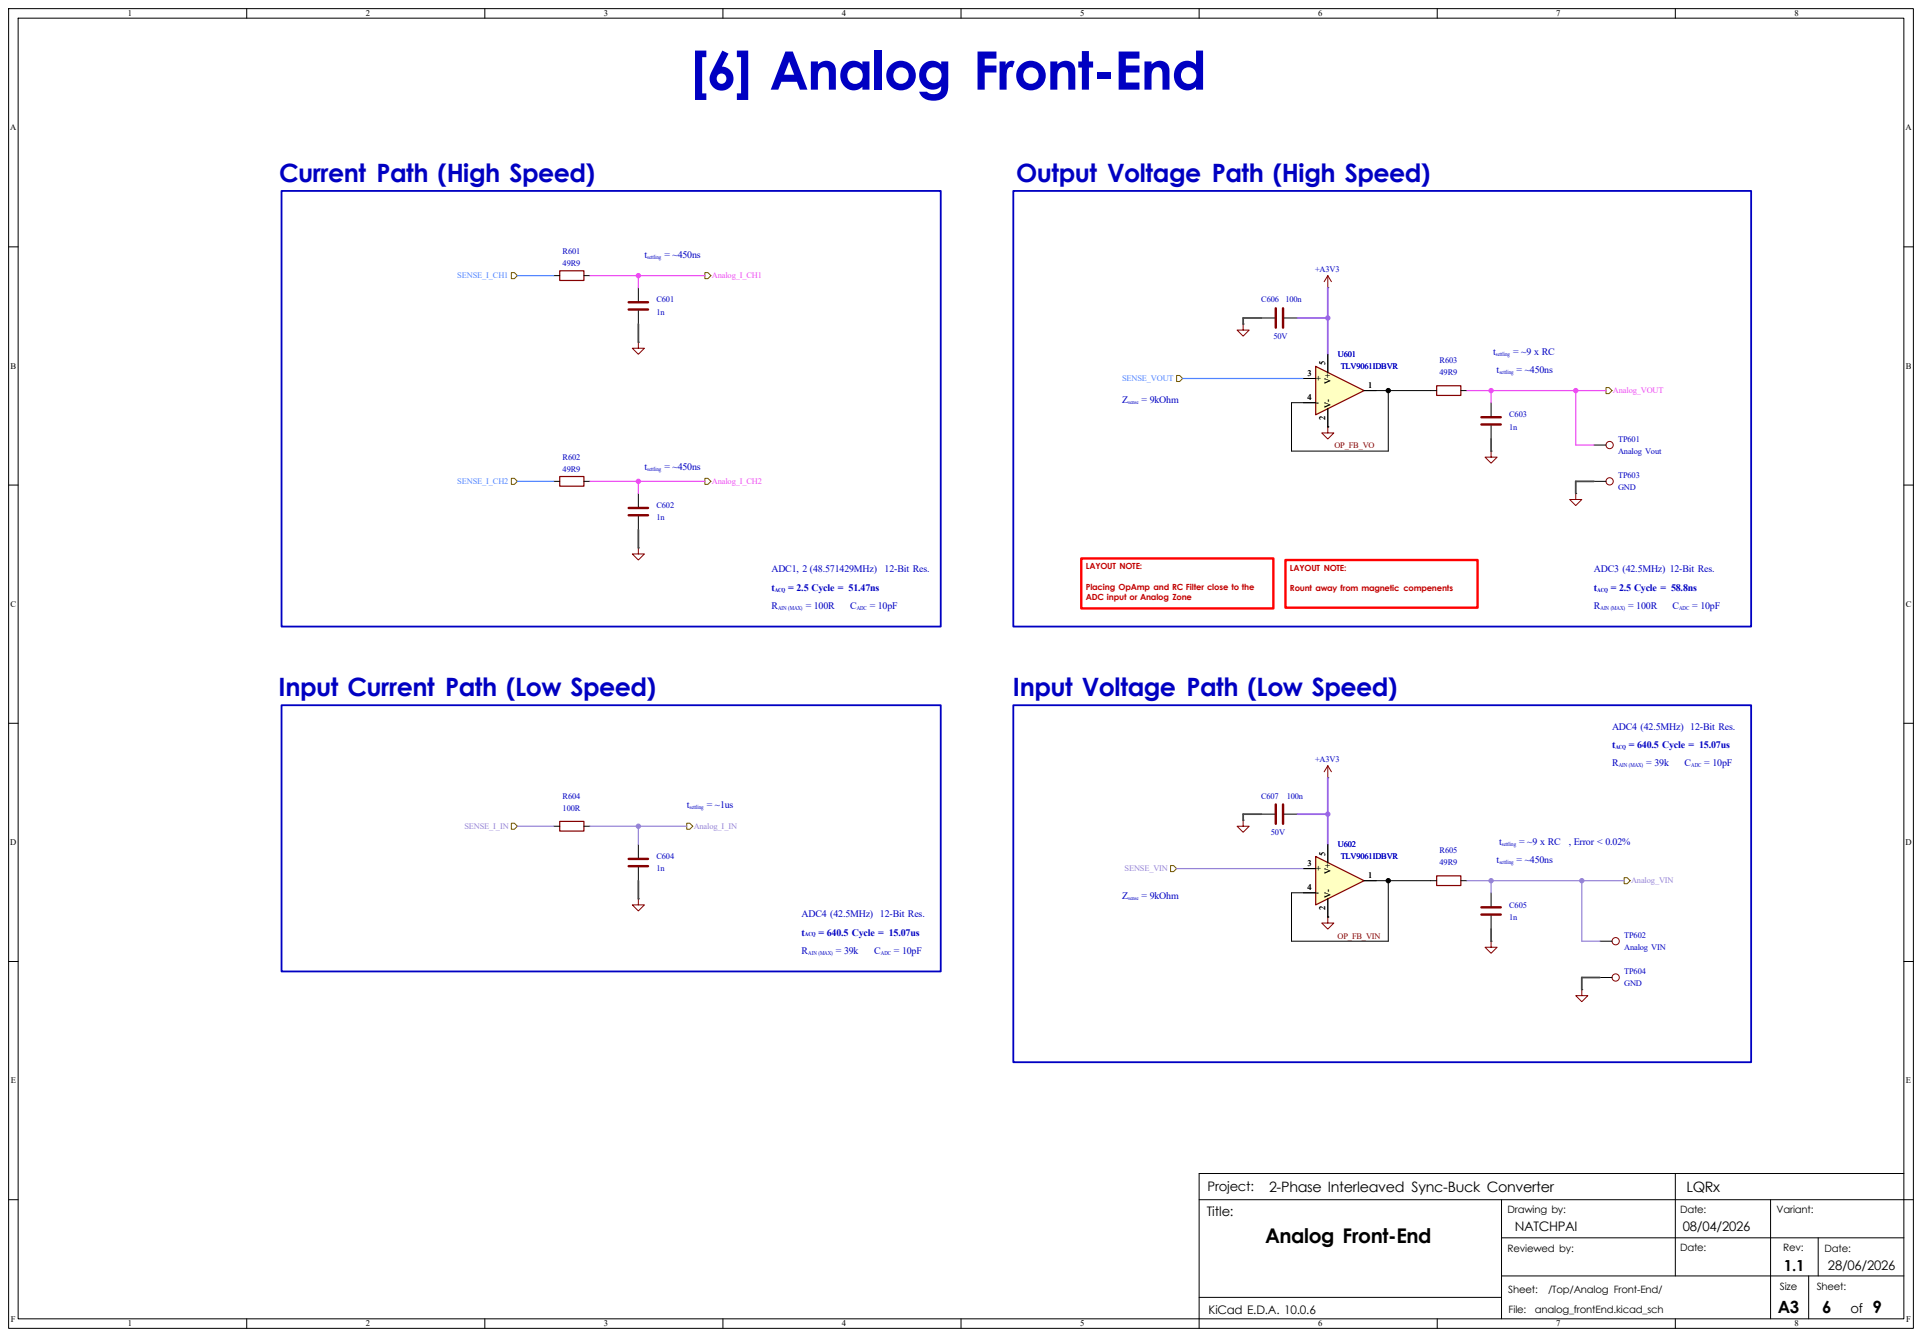
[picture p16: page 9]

tsettling = ~9 x RC [6] Analog Front-End

RAIN (MAX) = 39k Output Voltage Path (High Speed)

LAYOUT NOTE: Placing OpAmp and RC Filter close to the ADC input or Analog Zone RAIN (MAX) = 39k

LAYOUT NOTE: Rount away from magnetic compenents

2-Phase Interleaved Sync-Buck Converter
Analog Front-End

/Top/Analog Front-End/

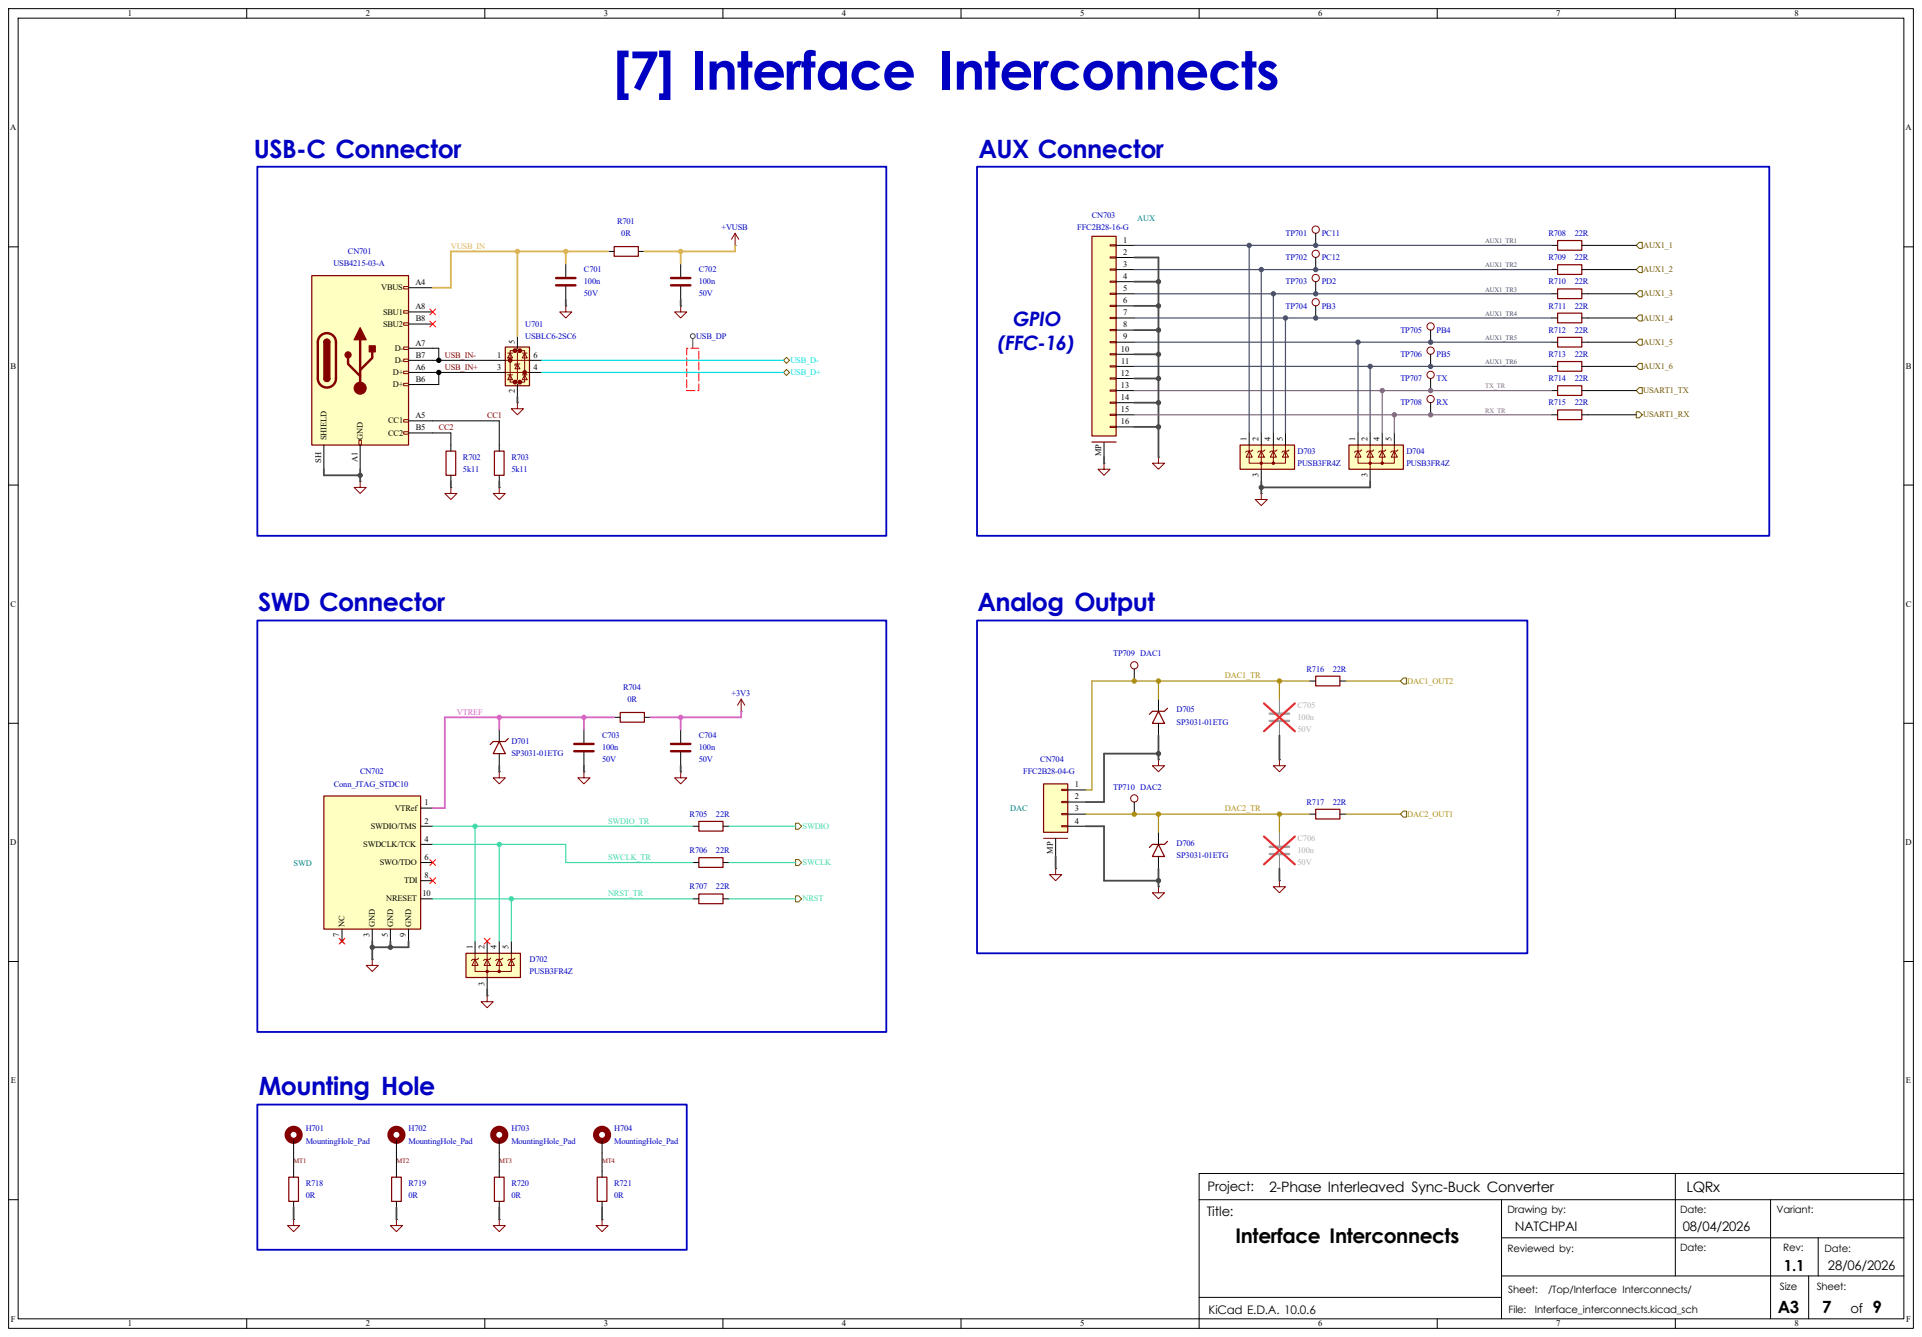
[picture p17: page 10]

2-Phase Interleaved Sync-Buck Converter
Interface Interconnects

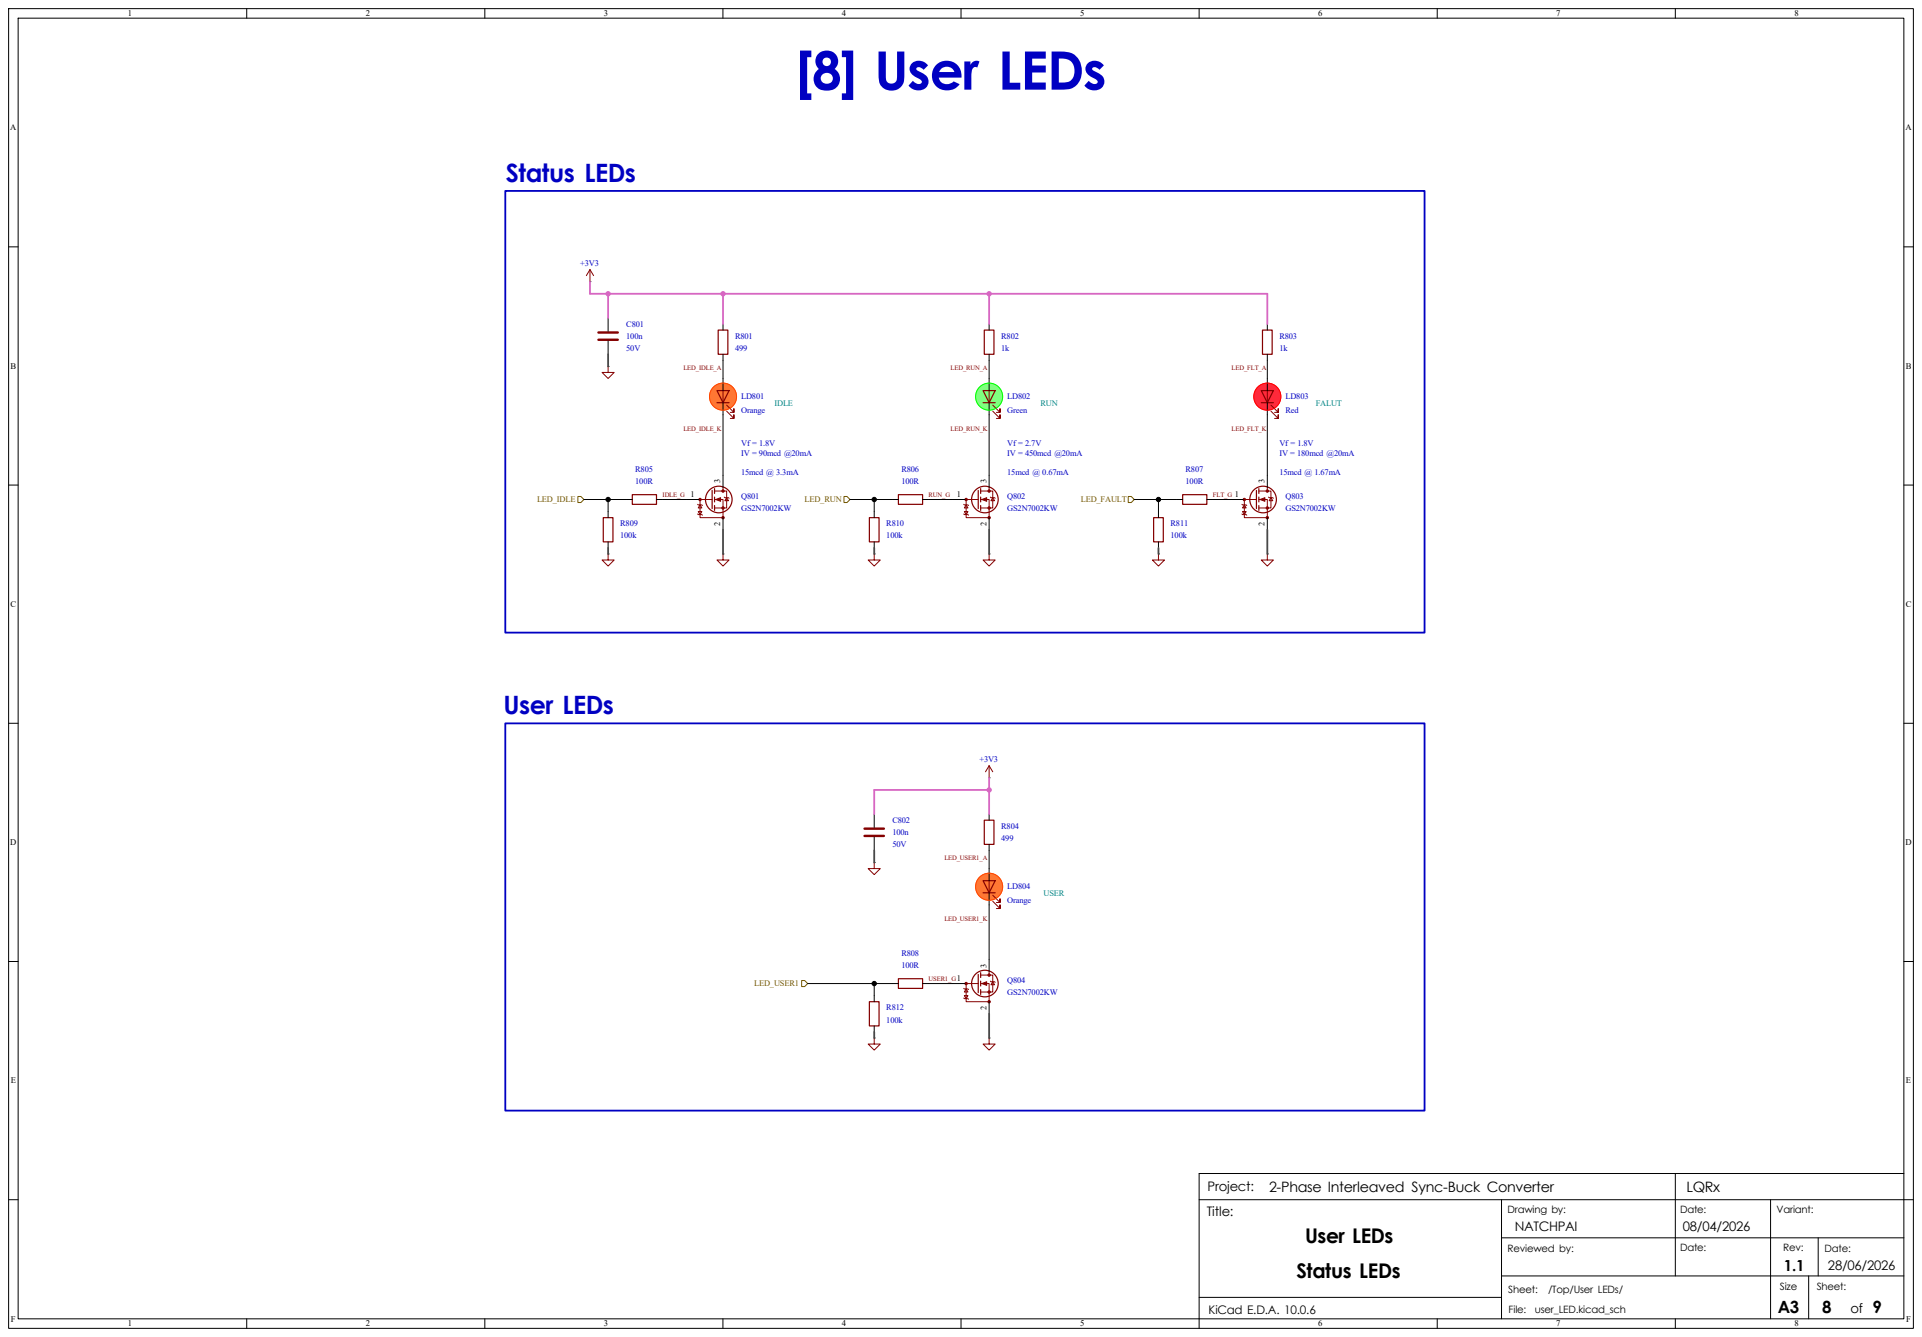
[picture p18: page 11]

2-Phase Interleaved Sync-Buck Converter
User LEDs
Status LEDs

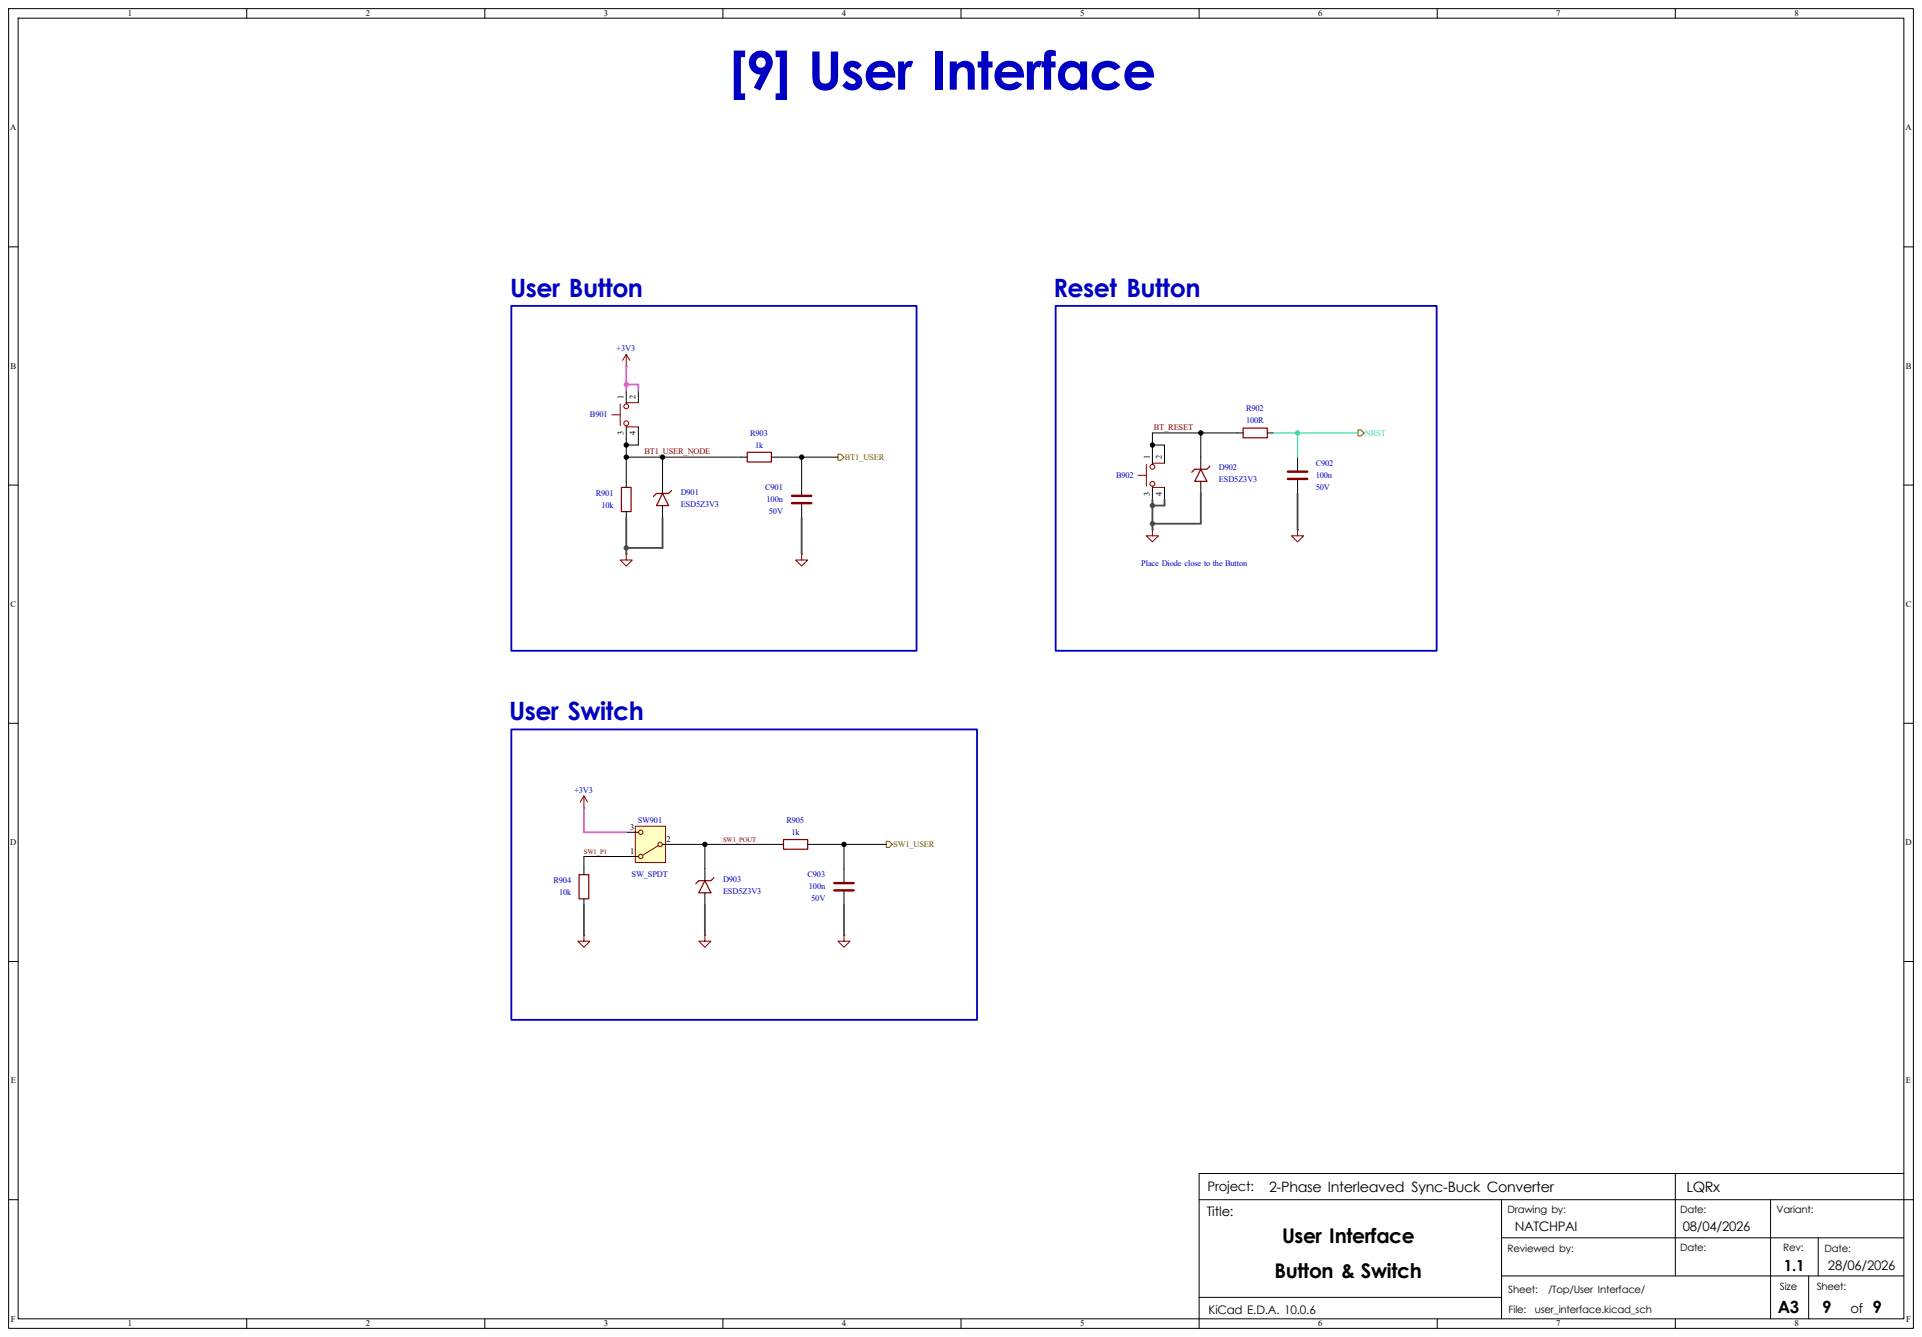
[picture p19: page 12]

Place Diode close to the Button User Button

2-Phase Interleaved Sync-Buck Converter
User Interface
Button & Switch


2-Phase Interleaved Sync-Buck Converter
Power Supply Sequencing


- (18/05/2026) Initialize the project
- (03/06/2026) PC Board is Released
Revison 1.1

(28/06/2026) - Remove the MOSFETs that Enable the ICs Gate Driver and connect directly. (p.1)

- Change ADC input Capacitor 47pF to 1nF. (p.6)
- Change OP-AMP U601 U602 to correctly part number (p.6)

2-Phase Interleaved Sync-Buck Converter
Revision History

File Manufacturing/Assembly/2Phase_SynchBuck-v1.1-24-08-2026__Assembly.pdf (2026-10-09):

C606 L102

# LD301 R107


Sheet: 2-Phase Interleaved Sync-Buck Converter

## GND VFILT

## GHS1


Sheet: 2-Phase Interleaved Sync-Buck Converter

TP114

# DAC1 DAC2 Top Testpoint (Scale 2:1)


Sheet: 2-Phase Interleaved Sync-Buck Converter

## GND VFILT

## GHS1


Gate HS 1 Gate LS 1 Gate HS 2 Gate LS 2 Vin Filter Switch-node 1 Switch-node 2 VREF1 VREF2

Sheet: 2-Phase Interleaved Sync-Buck Converter

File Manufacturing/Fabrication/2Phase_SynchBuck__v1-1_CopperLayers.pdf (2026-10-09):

1 1 2 3 4 5 6 1 2 3 4 5 6 ABCD ABCD; Rev: 1.1; Fabri L1; Title:; Variant: Project:; Fabrication Documents; Size; Sheet: A4; LQRx Date: Date: KiCad E.D.A. 10.0.5; File: 2Phase_SynchBuck.kicad_pcb; Date: L1 (Signal) (Scale 2:1)

Sheet: 2-Phase Interleaved Sync-Buck Converter

Drawing by:
NATCHPAI Reviewed by:

2 1 2 3 4 5 6 1 2 3 4 5 6 ABCD ABCD; Rev: 1.1; Title:; Variant: Project:; Fabrication Documents; LQRx Date: Date: KiCad E.D.A. 10.0.5; File: 2Phase_SynchBuck.kicad_pcb; Date: L2 (GND) (Scale 2:1)

Sheet: 2-Phase Interleaved Sync-Buck Converter

Drawing by:
NATCHPAI Reviewed by:

3 1 2 3 4 5 6 1 2 3 4 5 6 ABCD ABCD; Rev: 1.1; Title:; Variant: Project:; Fabrication Documents; LQRx Date: Date: KiCad E.D.A. 10.0.5; File: 2Phase_SynchBuck.kicad_pcb; Date: L3 (GND) (Scale 2:1)

Sheet: 2-Phase Interleaved Sync-Buck Converter

Drawing by:
NATCHPAI Reviewed by:

4 1 2 3 4 5 6 1 2 3 4 5 6 ABCD ABCD; Rev: 1.1; Title:; Variant: Project:; Fabrication Documents; LQRx Date: Date: KiCad E.D.A. 10.0.5; File: 2Phase_SynchBuck.kicad_pcb; Date: L4 (Signal) (Scale 2:1)

Sheet: 2-Phase Interleaved Sync-Buck Converter

Drawing by:
NATCHPAI Reviewed by:

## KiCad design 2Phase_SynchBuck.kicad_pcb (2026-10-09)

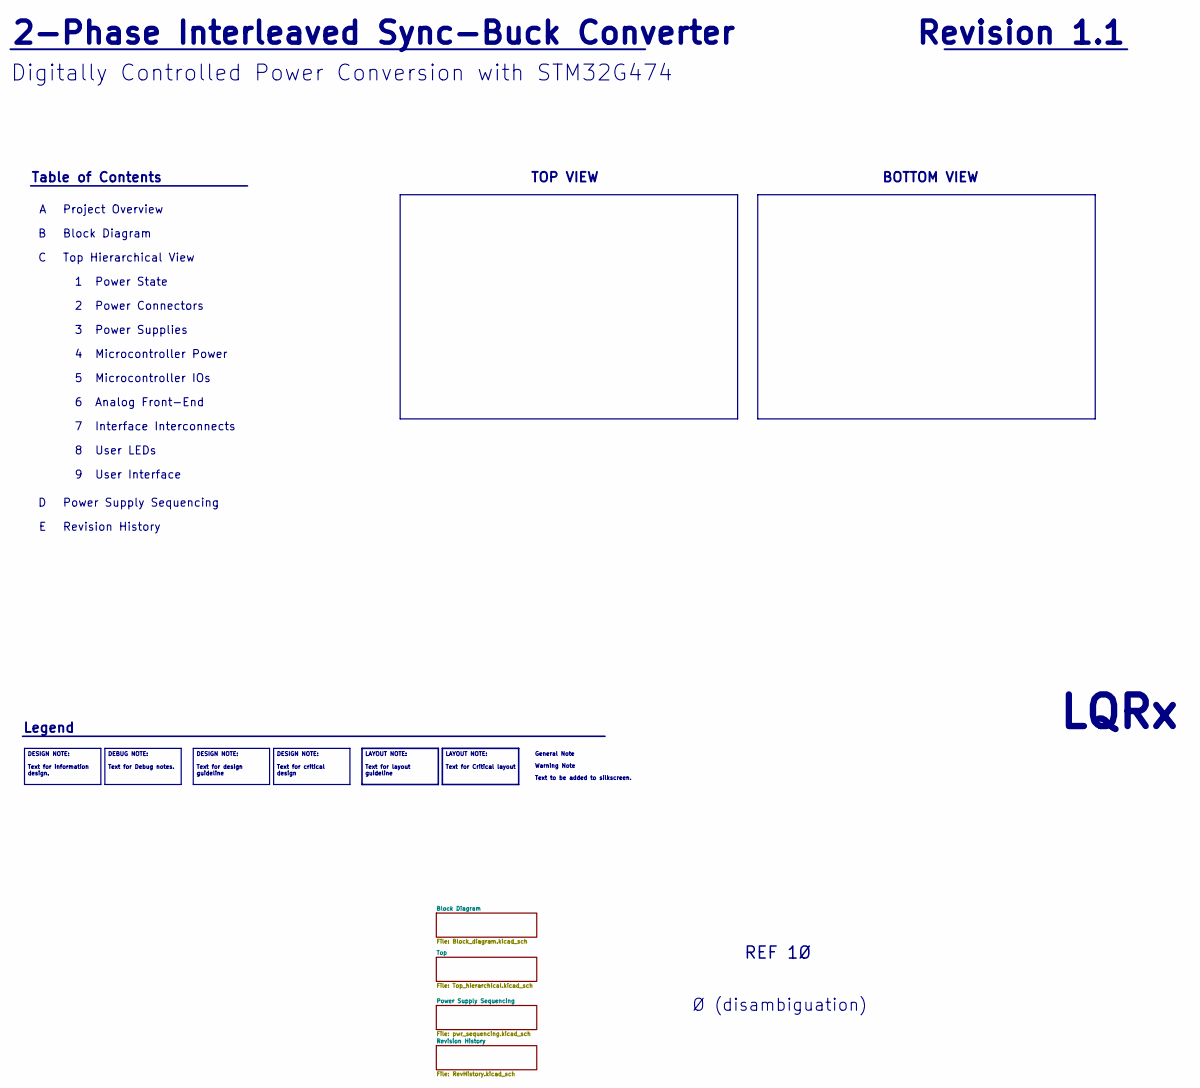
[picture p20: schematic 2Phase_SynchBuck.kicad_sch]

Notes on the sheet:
Top Hierarchical View
LQRx
General Note
Warning Note
Power Supplies
Analog Front-End
Microcontroller IOs
User LEDs
Project Overview
Ø (disambiguation)
Legend
Microcontroller Power
Table of Contents
2-Phase Interleaved Sync-Buck Converter
Interface Interconnects
REF 1Ø
TOP VIEW
Revision ${REVISION}
Revision History
BOTTOM VIEW
User Interface
Digitally Controlled Power Conversion with STM32G474
Power Supply Sequencing
Power State
Text to be added to silkscreen.
Block Diagram
Power Connectors
DESIGN NOTE: Text for critical design
LAYOUT NOTE: Text for layout guideline
DESIGN NOTE: Text for information design.
DEBUG NOTE: Text for Debug notes.
LAYOUT NOTE: Text for Critical layout
DESIGN NOTE: Text for design guideline

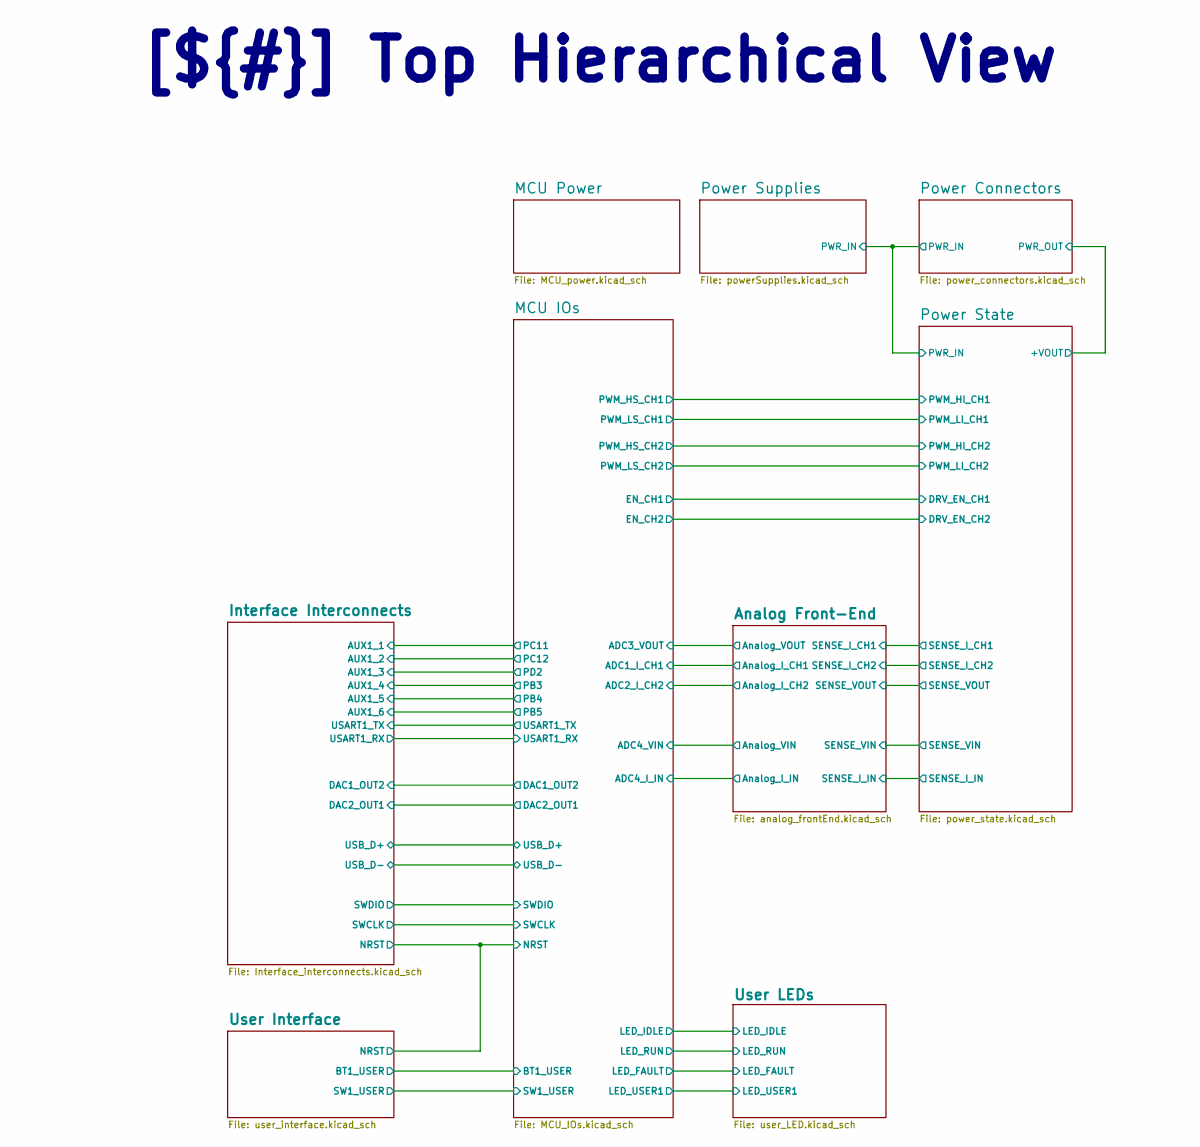
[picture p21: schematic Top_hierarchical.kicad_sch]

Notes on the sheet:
[${#}] ${COMMENT1}

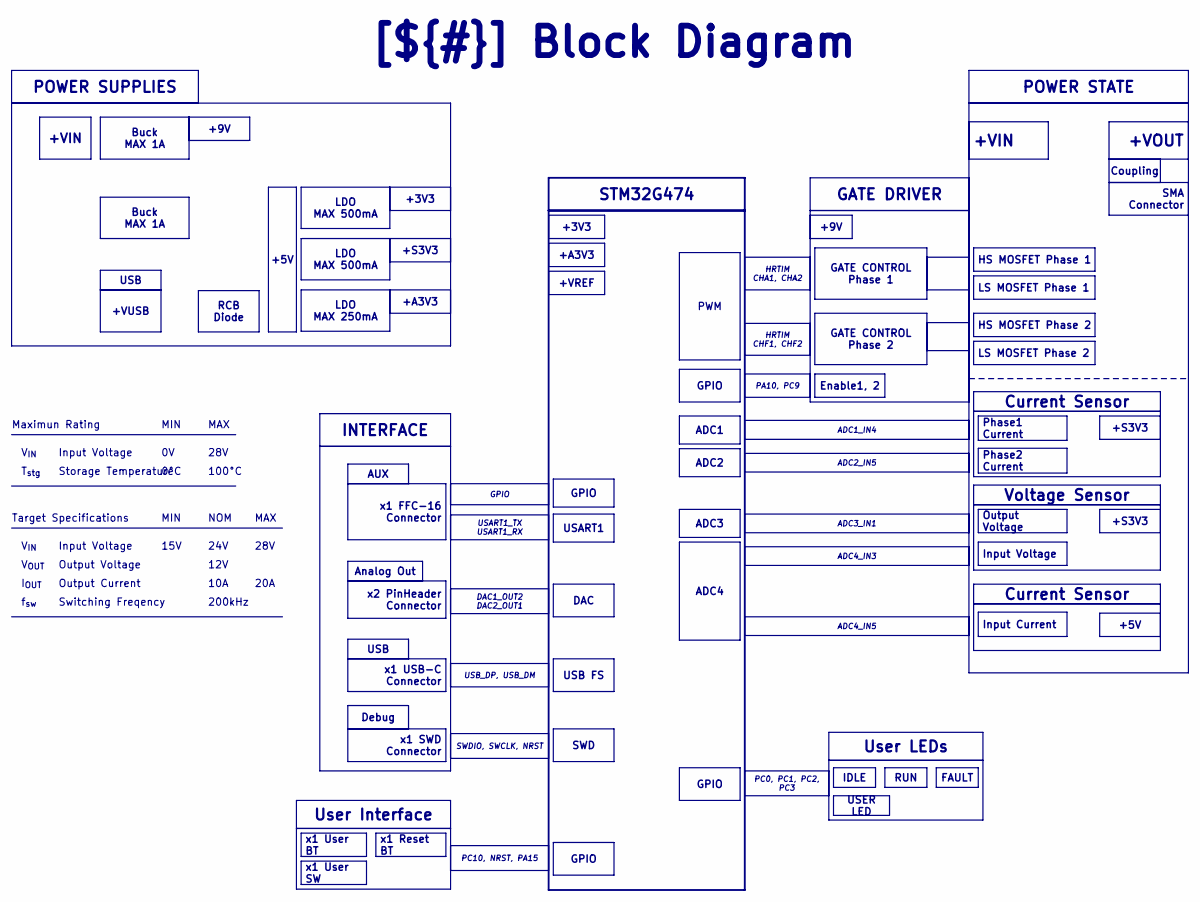
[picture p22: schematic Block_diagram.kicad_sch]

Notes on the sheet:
MAX
Output Current
12V
[${#}] ${COMMENT1}
MIN
V_{IN}
Output Voltage
T_{stg}
Target Specifications
100°C
f_{sw}
Storage Temperature
10A
28V
Maximun Rating
24V
0°C
Input Voltage
15V
NOM
200kHz
I_{OUT}
20A
Switching Freqency
V_{OUT}
Analog Out
x2 PinHeader Connector
LDO MAX 250mA
USB_DP, USB_DM
INTERFACE
+A3V3
DAC
+S3V3
USB
USART1
GATE CONTROL Phase 1
LS MOSFET Phase 1
FAULT
Current Sensor
PC0, PC1, PC2, PC3

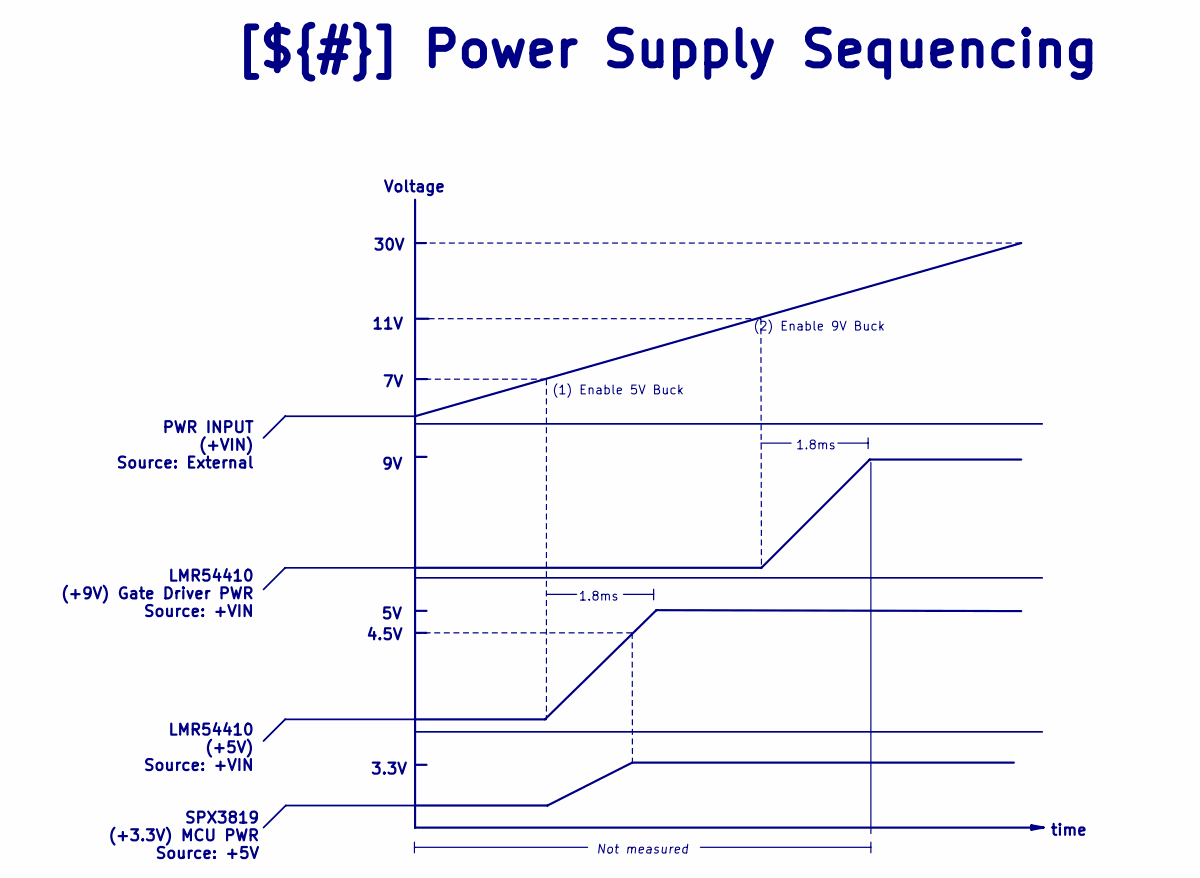
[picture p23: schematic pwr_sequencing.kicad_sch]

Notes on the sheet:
4.5V
SPX3819 (+3.3V) MCU PWR Source: +5V
[${#}] ${COMMENT1}
(1) Enable 5V Buck
Voltage
30V
1.8ms
PWR INPUT (+VIN) Source: External
11V
3.3V
time
Not measured
LMR54410 (+9V) Gate Driver PWR Source: +VIN
LMR54410 (+5V) Source: +VIN
(2) Enable 9V Buck

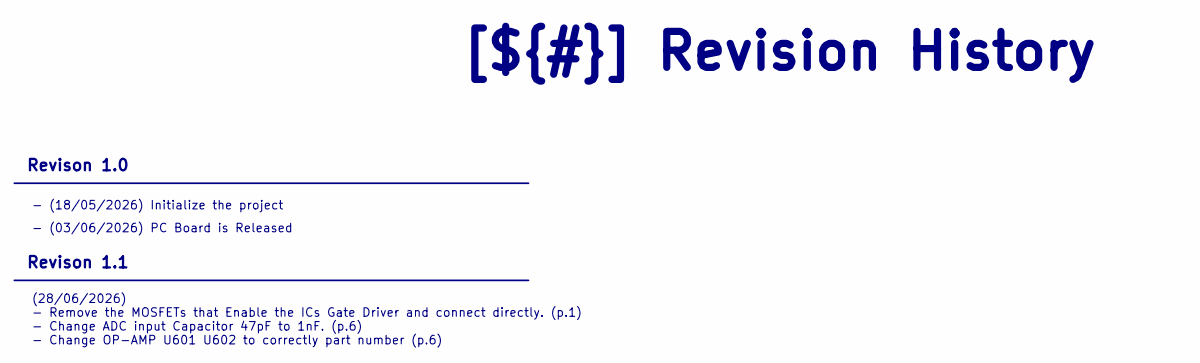
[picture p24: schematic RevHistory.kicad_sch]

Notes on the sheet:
(28/06/2026) - Remove the MOSFETs that Enable the ICs Gate Driver and connect directly. (p.1) - Change ADC input Capacitor 47pF to 1nF. (p.6) - Change OP-AMP U601 U602 to correctly part number (p.6)
- (18/05/2026) Initialize the project
[${#}] ${COMMENT1}
Revison 1.1
Revison 1.0
- (03/06/2026) PC Board is Released

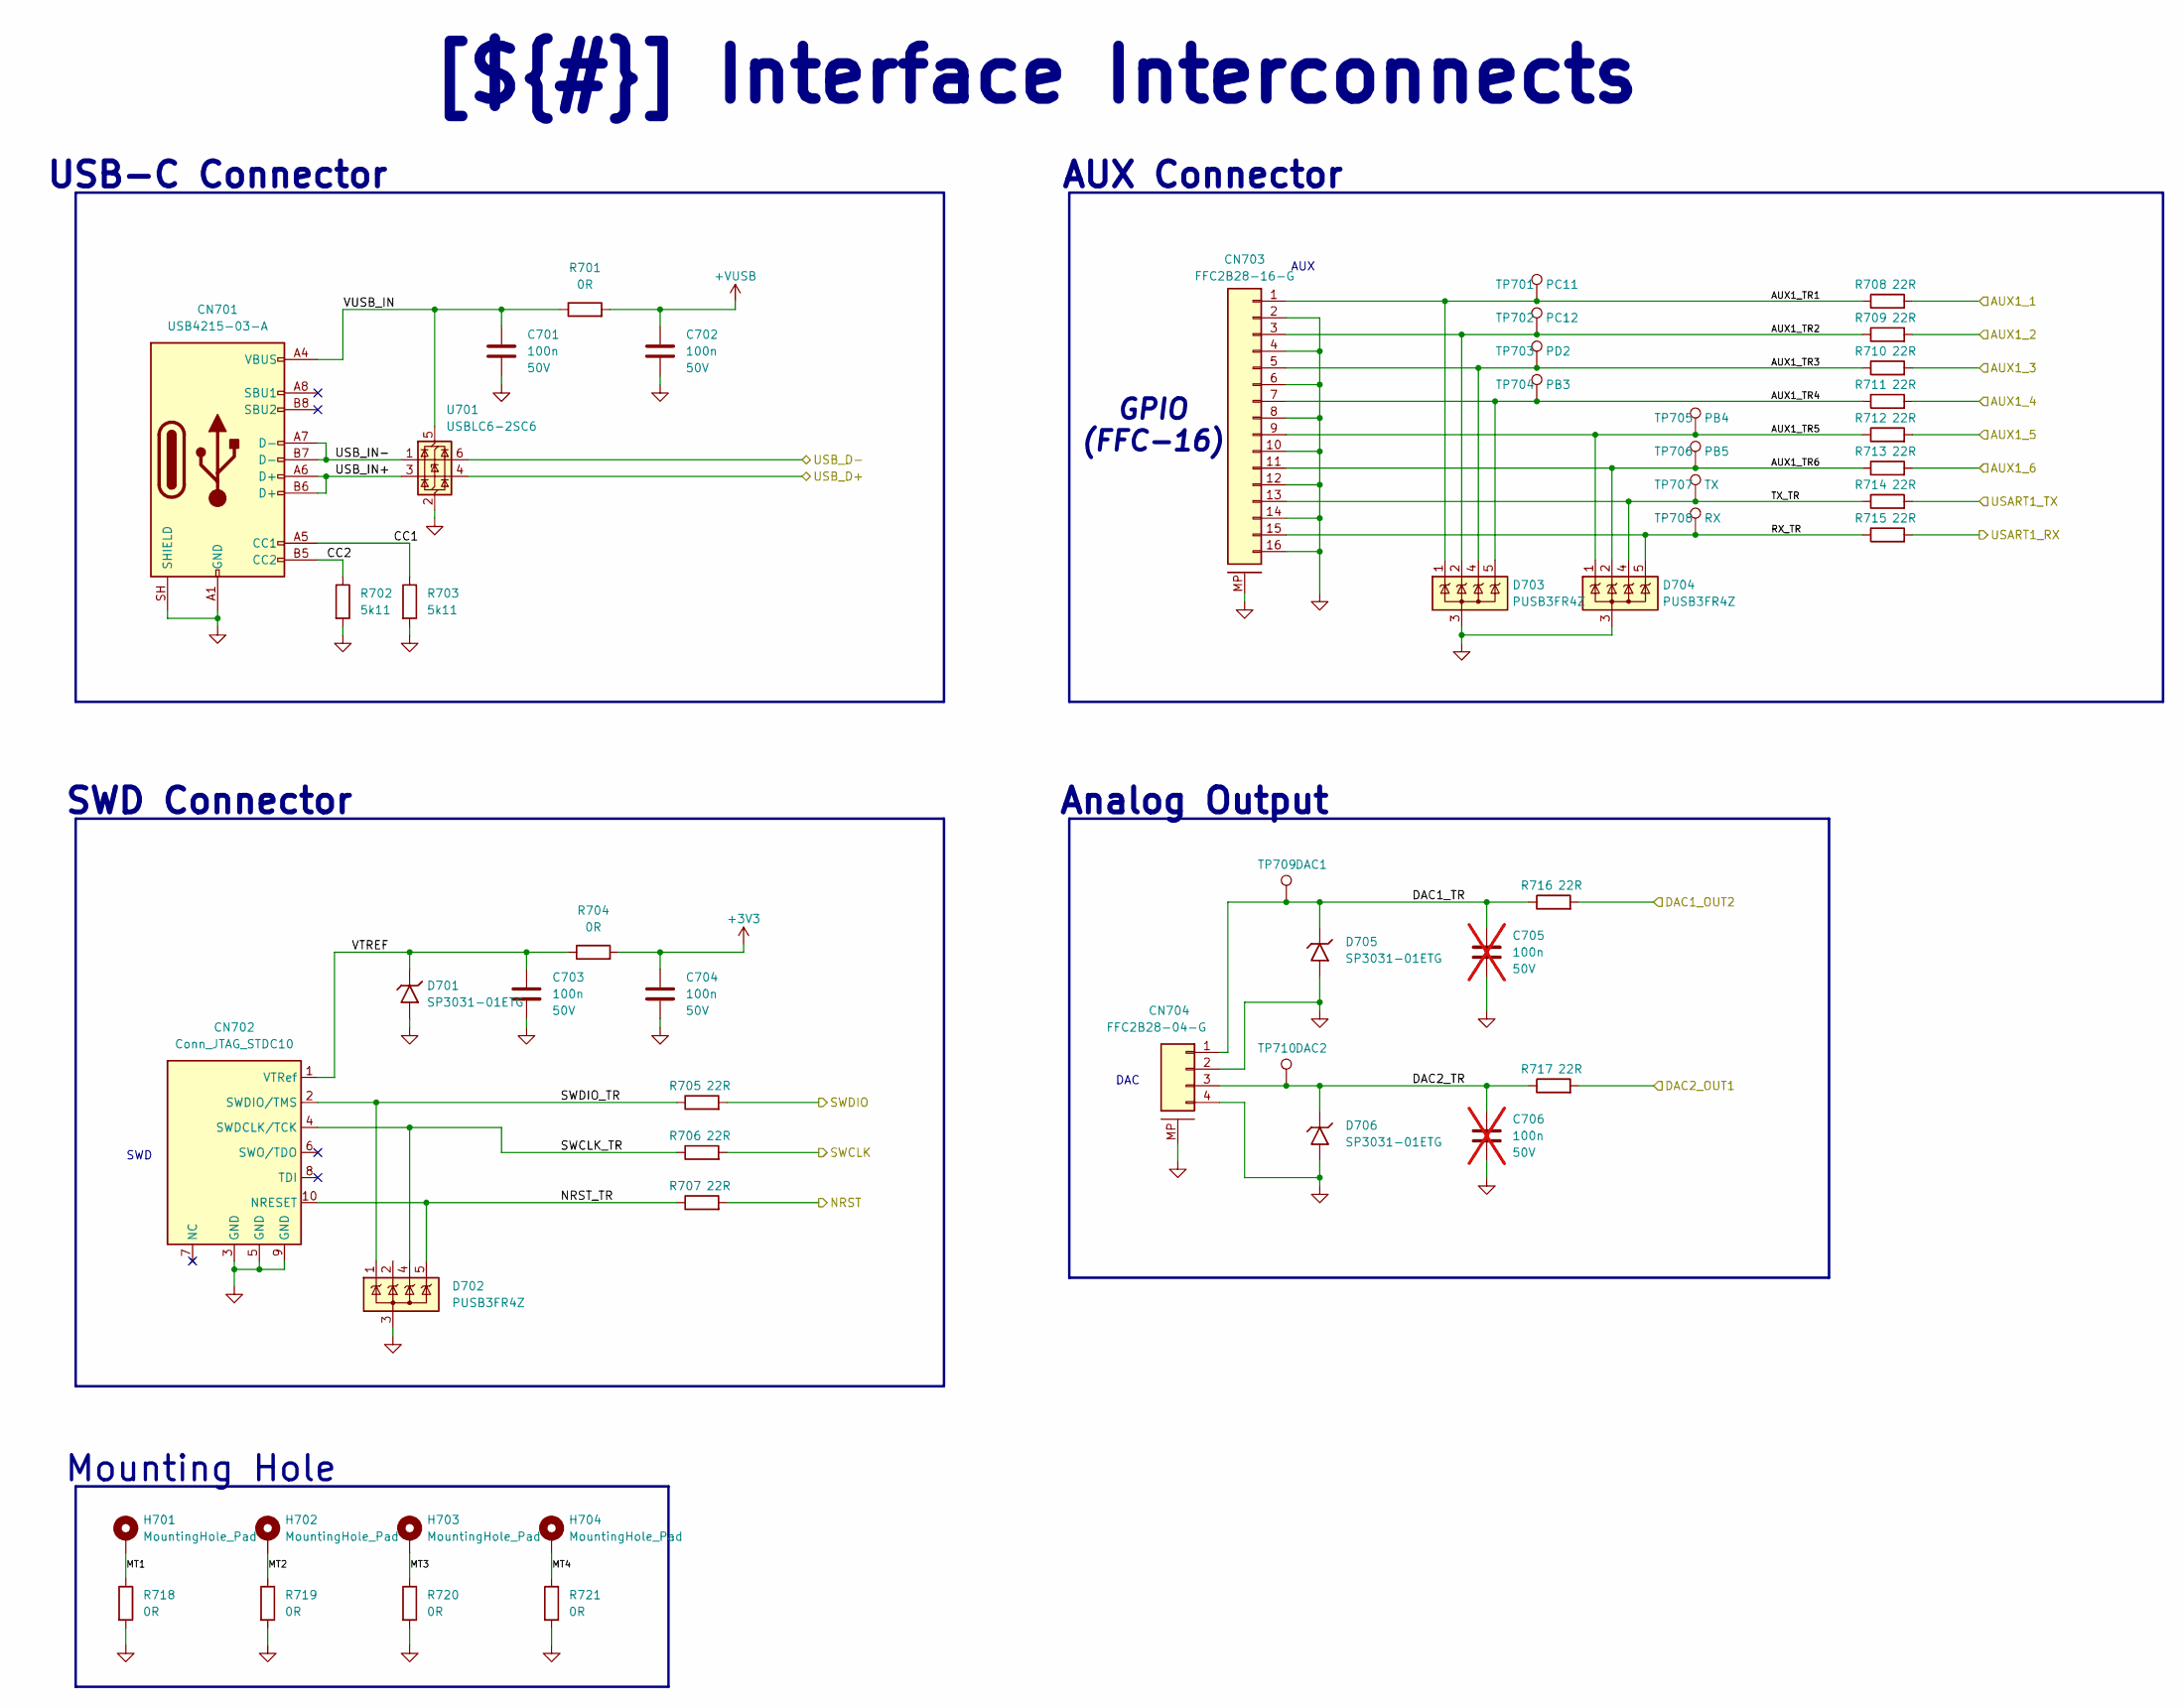
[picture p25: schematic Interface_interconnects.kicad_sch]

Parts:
C701, C702, C703, C704: 100n; C_0402_nomDensity; Manufacturer Part Number GRM155R71H104KE14D
C705, C706: 100n; C_0402_nomDensity; Manufacturer Part Number GRM155R71H104KE14D; not fitted
CN701: USB4215-03-A; USB_C_Receptacle_GCT_USB4215-03-A_16P_TopMnt_Horizontal; Manufacturer Part Number USB4215-03-A
CN702: Conn_JTAG_STDC10; BD_2x05_P1.27mm_Vertical_SMD; Manufacturer Part Number BD125-10-A-0305-0580-L-B
CN703: FFC2B28-16-G; GCT_FFC2B28-16_P0.5_FFC-16; Manufacturer Part Number FFC2B28-16-G
CN704: FFC2B28-04-G; GCT_FFC2B28-04_P0.5_FFC-4; Manufacturer Part Number FFC2B28-04-G
D701, D705, D706: SP3031-01ETG; D_SOD-882; Manufacturer Part Number SP3031-01ETG
D702, D703, D704: PUSB3FR4Z; SOT1176-2-_1x2.5mm_P0.5mm; Manufacturer Part Number PUSB3FR4Z
H701, H702, H703, H704: MountingHole_Pad; MountingHole_3.2mm_M3_Pad_Via
R701, R704, R718, R719, R720, R721: 0R; R_0603_nomDensity; Manufacturer Part Number RC0603JR-070RL
R702, R703: 5k11; R_0402_nomDensity; Manufacturer Part Number RC0402FR-135K11L
R705, R706, R707, R708, R709, R710, R711, R712, R713, R714, R715, R716, R717: 22R; R_0402_nomDensity; Manufacturer Part Number RC0402FR-1322RL
TP701: PC11; TestPoint_NoSlik_D0.5mm_Top
TP702: PC12; TestPoint_NoSlik_D0.5mm_Top
TP703: PD2; TestPoint_NoSlik_D0.5mm_Top
TP704: PB3; TestPoint_NoSlik_D0.5mm_Top
TP705: PB4; TestPoint_NoSlik_D0.5mm_Top
TP706: PB5; TestPoint_NoSlik_D0.5mm_Top
TP707: TX; TestPoint_NoSlik_D0.5mm_Top
TP708: RX; TestPoint_NoSlik_D0.5mm_Top
TP709: DAC1; TestPoint_NoSlik_D0.5mm_Top
TP710: DAC2; TestPoint_NoSlik_D0.5mm_Top
U701: USBLC6-2SC6; SOT-23-6; Manufacturer Part Number USBLC6-2SC6

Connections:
+3V3: C704.1, R704.2; also elsewhere on the board
+VUSB: C702.1, R701.2; also elsewhere on the board
/Top/Interface Interconnects/AUX1_TR1: CN703.1, D703.1 (K), D703.10, R708.1, TP701.1 (1_1)
/Top/Interface Interconnects/AUX1_TR2: CN703.3, D703.2 (K), D703.9, R709.1, TP702.1 (1_1)
/Top/Interface Interconnects/AUX1_TR3: CN703.5, D703.4 (K), D703.7, R710.1, TP703.1 (1_1)
/Top/Interface Interconnects/AUX1_TR4: CN703.7, D703.5 (K), D703.6, R711.1, TP704.1 (1_1)
/Top/Interface Interconnects/AUX1_TR5: CN703.9, D704.1 (K), D704.10, R712.1, TP705.1 (1_1)
/Top/Interface Interconnects/AUX1_TR6: CN703.11, D704.2 (K), D704.9, R713.1, TP706.1 (1_1)
/Top/Interface Interconnects/CC1: CN701.A5 (CC1), R703.1
/Top/Interface Interconnects/CC2: CN701.B5 (CC2), R702.1
/Top/Interface Interconnects/DAC1_TR: C705.1, CN704.1, D705.1, R716.1, TP709.1 (1_1)
/Top/Interface Interconnects/DAC2_TR: C706.1, CN704.3, D706.1, R717.1, TP710.1 (1_1)
/Top/Interface Interconnects/MT1: H701.1 (1_1), R718.1
/Top/Interface Interconnects/MT2: H702.1 (1_1), R719.1
/Top/Interface Interconnects/MT3: H703.1 (1_1), R720.1
/Top/Interface Interconnects/MT4: H704.1 (1_1), R721.1
/Top/Interface Interconnects/NRST_TR: CN702.10 (NRESET), D702.5 (K), D702.6, R707.1
/Top/Interface Interconnects/RX_TR: CN703.15, D704.5 (K), D704.6, R715.1, TP708.1 (1_1)
/Top/Interface Interconnects/SWCLK_TR: CN702.4 (SWDCLK/TCK), D702.4 (K), D702.7, R706.1
/Top/Interface Interconnects/SWDIO_TR: CN702.2 (SWDIO/TMS), D702.1 (K), D702.10, R705.1
/Top/Interface Interconnects/TX_TR: CN703.13, D704.4 (K), D704.7, R714.1, TP707.1 (1_1)
/Top/Interface Interconnects/USB_IN+: CN701.A6 (D+), CN701.B6 (D+), U701.3 (I/O2)
/Top/Interface Interconnects/USB_IN-: CN701.A7 (D-), CN701.B7 (D-), U701.1 (I/O1)
/Top/Interface Interconnects/VTREF: C703.1, CN702.1 (VTRef), D701.1, R704.1
/Top/Interface Interconnects/VUSB_IN: C701.1, CN701.A4 (VBUS), CN701.A9 (VBUS), CN701.B4 (VBUS), CN701.B9 (VBUS), R701.1, U701.5 (VBUS)
/Top/MCU IOs/DAC1_OUT2: R716.2; also elsewhere on the board
/Top/MCU IOs/DAC2_OUT1: R717.2; also elsewhere on the board
/Top/MCU IOs/NRST: R707.2; also elsewhere on the board
/Top/MCU IOs/PB3: R711.2; also elsewhere on the board
/Top/MCU IOs/PB4: R712.2; also elsewhere on the board
/Top/MCU IOs/PB5: R713.2; also elsewhere on the board
/Top/MCU IOs/PC11: R708.2; also elsewhere on the board
/Top/MCU IOs/PC12: R709.2; also elsewhere on the board
/Top/MCU IOs/PD2: R710.2; also elsewhere on the board
/Top/MCU IOs/SWCLK: R706.2; also elsewhere on the board
/Top/MCU IOs/SWDIO: R705.2; also elsewhere on the board
/Top/MCU IOs/USART1_RX: R715.2; also elsewhere on the board
/Top/MCU IOs/USART1_TX: R714.2; also elsewhere on the board
/Top/MCU IOs/USB_D+: U701.4 (I/O2); also elsewhere on the board
/Top/MCU IOs/USB_D-: U701.6 (I/O1); also elsewhere on the board
GND: C701.2, C702.2, C703.2, C704.2, C705.2, C706.2, CN701.A1 (GND), CN701.A12 (GND), CN701.B1 (GND), CN701.B12 (GND), CN701.SH (SHIELD), CN702.3 (GND), CN702.5 (GND), CN702.9 (GND), CN703.2, CN703.4, CN703.6, CN703.8, CN703.10, CN703.12, CN703.14, CN703.16, CN703.MP (MountPin), CN704.2, CN704.4, CN704.MP (MountPin), D701.2, D702.3 (A), D702.8 (A), D703.3 (A), D703.8 (A), D704.3 (A), D704.8 (A), D705.2, D706.2, R702.2, R703.2, R718.2, R719.2, R720.2, R721.2, U701.2 (GND); also elsewhere on the board
unnamed: D702.2 (K), D702.9

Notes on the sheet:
SWD
SWD Connector
[${#}] ${COMMENT1}
AUX Connector
USB-C Connector
GPIO (FFC-16)
AUX
Mounting Hole
Analog Output
DAC

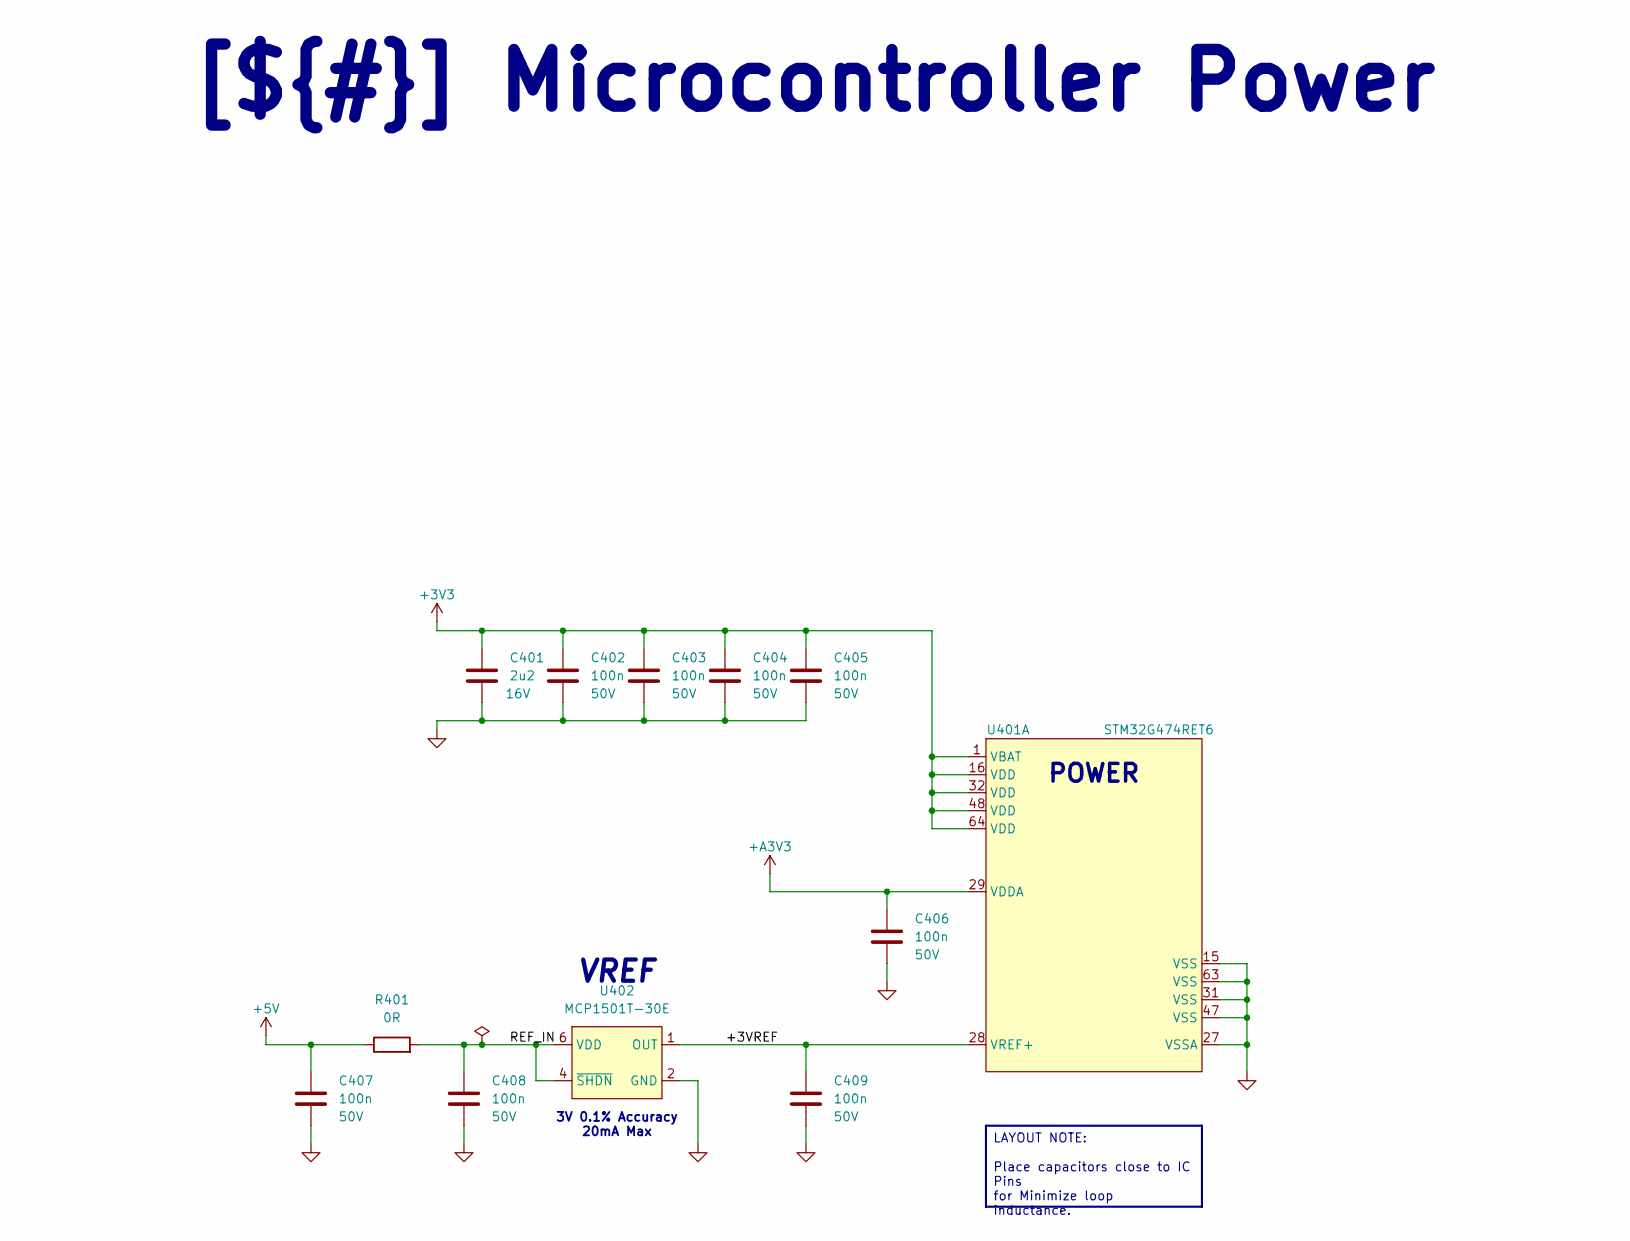
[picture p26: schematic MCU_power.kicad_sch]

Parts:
C401: 2u2; C_0603_nomDensity; Manufacturer Part Number GRM188Z71C225KE43
C402, C403, C404, C405, C406, C407, C408, C409: 100n; C_0402_nomDensity; Manufacturer Part Number GRM155R71H104KE14D
R401: 0R; R_0603_nomDensity; Manufacturer Part Number RC0603JR-070RL
U401: STM32G474RET6; LQFP-64_10x10mm_P0.5mm; Manufacturer Part Number STM32G474RET6
U402: MCP1501T-30E; SOT-23-6; Manufacturer Part Number MCP1501T-30E

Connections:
+3V3: C401.1, C402.1, C403.1, C404.1, C405.1, U401.1 (VBAT), U401.16 (VDD), U401.32 (VDD), U401.48 (VDD), U401.64 (VDD); also elsewhere on the board
+5V: C407.1, R401.1; also elsewhere on the board
+A3V3: C406.1, U401.29 (VDDA); also elsewhere on the board
/Top/MCU Power/+3VREF: C409.1, U401.28 (VREF+), U402.1 (OUT)
/Top/MCU Power/REF_IN: C408.1, R401.2, U402.4 (~SHDN), U402.6 (VDD)
GND: C401.2, C402.2, C403.2, C404.2, C405.2, C406.2, C407.2, C408.2, C409.2, U401.15 (VSS), U401.27 (VSSA), U401.31 (VSS), U401.47 (VSS), U401.63 (VSS), U402.2 (GND), U402.3 (GND), U402.5 (GND); also elsewhere on the board

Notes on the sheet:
VREF
3V 0.1% Accuracy 20mA Max
POWER
[${#}] ${COMMENT1}
LAYOUT NOTE: Place capacitors close to IC Pins for Minimize loop inductance.

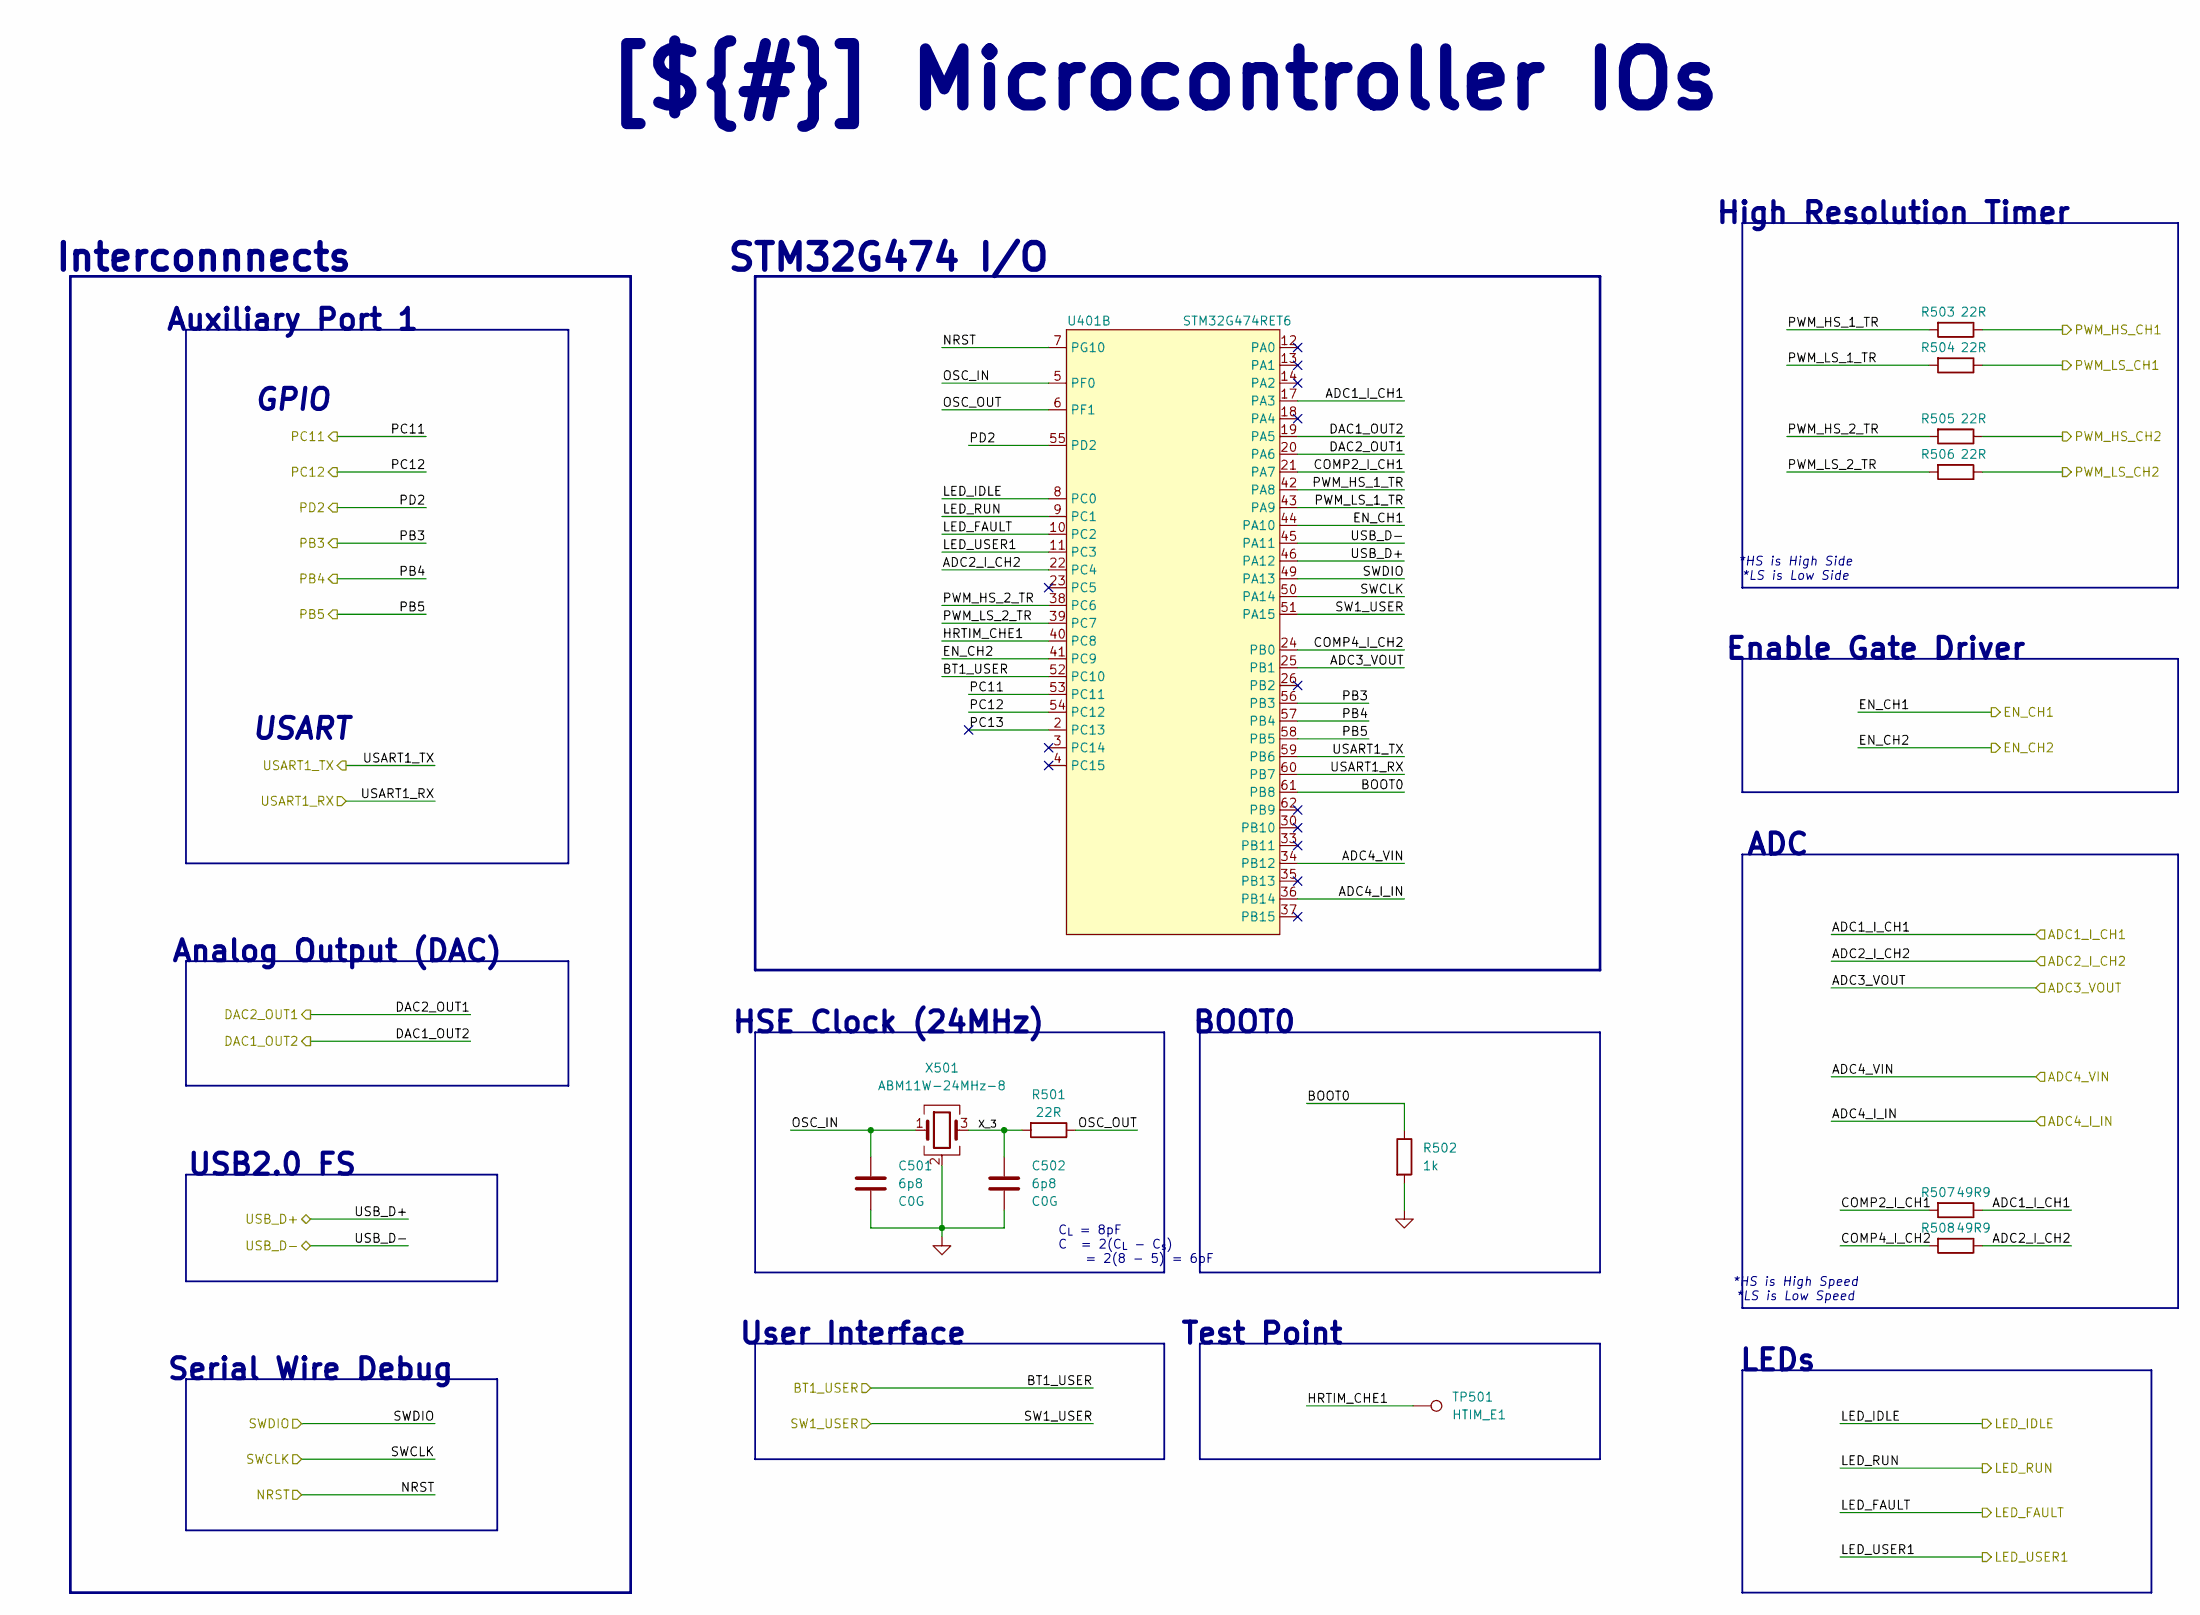
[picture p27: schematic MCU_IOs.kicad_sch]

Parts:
C501, C502: 6p8; C_0402_nomDensity; Manufacturer Part Number GCM1555C1H6R8FA16D
R501, R503, R504, R505, R506: 22R; R_0402_nomDensity; Manufacturer Part Number RC0402FR-1322RL
R502: 1k; R_0402_nomDensity; Manufacturer Part Number RC0402FR-071KL
R507, R508: 49R9; R_0402_nomDensity; Manufacturer Part Number RC0402FR-1349R9L
TP501: HTIM_E1; TestPoint_NoSlik_D1.0mm_Bottom
U401: STM32G474RET6; LQFP-64_10x10mm_P0.5mm; Manufacturer Part Number STM32G474RET6
X501: ABM11W-24MHz-8; ABM11W_2.0x1.6mm; Manufacturer Part Number ABM11W-24.0000MHZ-8-B1U-T3

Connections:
/Top/MCU IOs/ADC1_I_CH1: R507.1, U401.17 (PA3); also elsewhere on the board
/Top/MCU IOs/ADC2_I_CH2: R508.1, U401.22 (PC4); also elsewhere on the board
/Top/MCU IOs/ADC3_VOUT: U401.25 (PB1); also elsewhere on the board
/Top/MCU IOs/ADC4_I_IN: U401.36 (PB14); also elsewhere on the board
/Top/MCU IOs/ADC4_VIN: U401.34 (PB12); also elsewhere on the board
/Top/MCU IOs/BOOT0: R502.1, U401.61 (PB8)
/Top/MCU IOs/BT1_USER: U401.52 (PC10); also elsewhere on the board
/Top/MCU IOs/COMP2_I_CH1: R507.2, U401.21 (PA7)
/Top/MCU IOs/COMP4_I_CH2: R508.2, U401.24 (PB0)
/Top/MCU IOs/DAC1_OUT2: U401.19 (PA5); also elsewhere on the board
/Top/MCU IOs/DAC2_OUT1: U401.20 (PA6); also elsewhere on the board
/Top/MCU IOs/EN_CH1: U401.44 (PA10); also elsewhere on the board
/Top/MCU IOs/EN_CH2: U401.41 (PC9); also elsewhere on the board
/Top/MCU IOs/HRTIM_CHE1: TP501.1 (1_1), U401.40 (PC8)
/Top/MCU IOs/LED_FAULT: U401.10 (PC2); also elsewhere on the board
/Top/MCU IOs/LED_IDLE: U401.8 (PC0); also elsewhere on the board
/Top/MCU IOs/LED_RUN: U401.9 (PC1); also elsewhere on the board
/Top/MCU IOs/LED_USER1: U401.11 (PC3); also elsewhere on the board
/Top/MCU IOs/NRST: U401.7 (PG10); also elsewhere on the board
/Top/MCU IOs/OSC_IN: C501.1, U401.5 (PF0), X501.1
/Top/MCU IOs/OSC_OUT: R501.1, U401.6 (PF1)
/Top/MCU IOs/PB3: U401.56 (PB3); also elsewhere on the board
/Top/MCU IOs/PB4: U401.57 (PB4); also elsewhere on the board
/Top/MCU IOs/PB5: U401.58 (PB5); also elsewhere on the board
/Top/MCU IOs/PC11: U401.53 (PC11); also elsewhere on the board
/Top/MCU IOs/PC12: U401.54 (PC12); also elsewhere on the board
/Top/MCU IOs/PC13: U401.2 (PC13)
/Top/MCU IOs/PD2: U401.55 (PD2); also elsewhere on the board
/Top/MCU IOs/PWM_HS_1_TR: R503.2, U401.42 (PA8)
/Top/MCU IOs/PWM_HS_2_TR: R505.2, U401.38 (PC6)
/Top/MCU IOs/PWM_HS_CH1: R503.1; also elsewhere on the board
/Top/MCU IOs/PWM_HS_CH2: R505.1; also elsewhere on the board
/Top/MCU IOs/PWM_LS_1_TR: R504.2, U401.43 (PA9)
/Top/MCU IOs/PWM_LS_2_TR: R506.2, U401.39 (PC7)
/Top/MCU IOs/PWM_LS_CH1: R504.1; also elsewhere on the board
/Top/MCU IOs/PWM_LS_CH2: R506.1; also elsewhere on the board
/Top/MCU IOs/SW1_USER: U401.51 (PA15); also elsewhere on the board
/Top/MCU IOs/SWCLK: U401.50 (PA14); also elsewhere on the board
/Top/MCU IOs/SWDIO: U401.49 (PA13); also elsewhere on the board
/Top/MCU IOs/USART1_RX: U401.60 (PB7); also elsewhere on the board
/Top/MCU IOs/USART1_TX: U401.59 (PB6); also elsewhere on the board
/Top/MCU IOs/USB_D+: U401.46 (PA12); also elsewhere on the board
/Top/MCU IOs/USB_D-: U401.45 (PA11); also elsewhere on the board
/Top/MCU IOs/X_3: C502.1, R501.2, X501.3
GND: C501.2, C502.2, R502.2, X501.2 (G), X501.4 (G); also elsewhere on the board

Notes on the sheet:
Serial Wire Debug
Enable Gate Driver
GPIO
C_{L} = 8pF C = 2(C_{L} - C_{s}) = 2(8 - 5) = 6pF
BOOT0
HSE Clock (24MHz)
[${#}] ${COMMENT1}
ADC
Interconnnects
USART
*HS is High Speed *LS is Low Speed
*HS is High Side *LS is Low Side
STM32G474 I/O
USB2.0 FS
Analog Output (DAC)
Auxiliary Port 1
High Resolution Timer
Test Point
User Interface
LEDs

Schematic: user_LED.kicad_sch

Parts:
C801, C802: 100n; C_0402_nomDensity; Manufacturer Part Number GRM155R71H104KE14D
LD801, LD804: Orange; LED_0603_1608Metric; Manufacturer Part Numbe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 LTST-C190KFKT
LD802: Green; LED_0603_1608Metric; Manufacturer Part Numbe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 LTST-C191TGKT
LD803: Red; LED_0603_1608Metric; Manufacturer Part Numbe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 LTST-C191KRKT
Q801, Q802, Q803, Q804: GS2N7002KW; SOT-323_SC-70; Manufacturer Part Number GS2N7002KW
R801, R804: 499; R_0402_nomDensity; Manufacturer Part Number RC0402FR-07499RL
R802, R803: 1k; R_0402_nomDensity; Manufacturer Part Number RC0402FR-071KL
R805, R806, R807, R808: 100R; R_0402_nomDensity; Manufacturer Part Number RC0402FR-07100RL
R809, R810, R811, R812: 100k; R_0402_nomDensity; Manufacturer Part Number RC0402FR-07100KL

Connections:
+3V3: C801.1, C802.1, R801.1, R802.1, R803.1, R804.1; also elsewhere on the board
/Top/MCU IOs/LED_FAULT: R807.1, R811.1; also elsewhere on the board
/Top/MCU IOs/LED_IDLE: R805.1, R809.1; also elsewhere on the board
/Top/MCU IOs/LED_RUN: R806.1, R810.1; also elsewhere on the board
/Top/MCU IOs/LED_USER1: R808.1, R812.1; also elsewhere on the board
/Top/User LEDs/FLT_G: Q803.1 (G), R807.2
/Top/User LEDs/IDLE_G: Q801.1 (G), R805.2
/Top/User LEDs/LED_FLT_A: LD803.2 (A), R803.2
/Top/User LEDs/LED_FLT_K: LD803.1 (K), Q803.3 (D)
/Top/User LEDs/LED_IDLE_A: LD801.2 (A), R801.2
/Top/User LEDs/LED_IDLE_K: LD801.1 (K), Q801.3 (D)
/Top/User LEDs/LED_RUN_A: LD802.2 (A), R802.2
/Top/User LEDs/LED_RUN_K: LD802.1 (K), Q802.3 (D)
/Top/User LEDs/LED_USER1_A: LD804.2 (A), R804.2
/Top/User LEDs/LED_USER1_K: LD804.1 (K), Q804.3 (D)
/Top/User LEDs/RUN_G: Q802.1 (G), R806.2
/Top/User LEDs/USER1_G: Q804.1 (G), R808.2
GND: C801.2, C802.2, Q801.2 (S), Q802.2 (S), Q803.2 (S), Q804.2 (S), R809.2, R810.2, R811.2, R812.2; also elsewhere on the board

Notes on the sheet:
Status LEDs
15mcd @ 1.67mA
RUN
FALUT
USER
15mcd @ 0.67mA
Vf = 1.8V IV = 180mcd @20mA
User LEDs
Vf = 1.8V IV = 90mcd @20mA
Vf = 2.7V IV = 450mcd @20mA
IDLE
15mcd @ 3.3mA
[${#}] ${COMMENT1}

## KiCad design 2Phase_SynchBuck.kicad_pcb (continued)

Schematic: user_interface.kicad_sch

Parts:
B901, B902: SW_Tactile_PTS815SJM250; Manufacturer Part Number PTS815SJM250SMTRLFS
C901, C902, C903: 100n; C_0402_nomDensity; Manufacturer Part Number GRM155R71H104KE14D
D901, D902, D903: ESD5Z3V3; D_SOD-523; Manufacturer Part Number ESD5Z3V3
R901, R904: 10k; R_0402_nomDensity; Manufacturer Part Number RC0402FR-1010KL
R902: 100R; R_0402_nomDensity; Manufacturer Part Number RC0402FR-07100RL
R903, R905: 1k; R_0402_nomDensity; Manufacturer Part Number RC0402FR-071KL
SW901: SW_SPDT; SW_SPDT_PCM12; Manufacturer Part Numbe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 SS-B90AP-W-SP2-S085

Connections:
+3V3: B901.1, B901.2, SW901.3 (C); also elsewhere on the board
/Top/MCU IOs/BT1_USER: C901.1, R903.2; also elsewhere on the board
/Top/MCU IOs/NRST: C902.1, R902.1; also elsewhere on the board
/Top/MCU IOs/SW1_USER: C903.1, R905.2; also elsewhere on the board
/Top/User Interface/BT1_USER_NODE: B901.3, B901.4, D901.1, R901.2, R903.1
/Top/User Interface/BT_RESET: B902.1, B902.2, D902.1, R902.2
/Top/User Interface/SW1_P1: R904.2, SW901.1 (A)
/Top/User Interface/SW1_POUT: D903.1, R905.1, SW901.2 (B)
GND: B902.3, B902.4, C901.2, C902.2, C903.2, D901.2, D902.2, D903.2, R901.1, R904.1; also elsewhere on the board

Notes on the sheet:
User Switch
[${#}] ${COMMENT1}
User Button
Reset Button
Place Diode close to the Button

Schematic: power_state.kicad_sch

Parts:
C101, C102, C110, C111, C112, C113, C122, C123, C124, C125: 4u7; C_1210_nomDensity; Manufacturer Part Number GRT32ER71H475KE01L
C103, C104, C105: 47u; CP_Elec_6.3x5.5_WCAP-ASLI; Manufacturer Part Number 865060543005
C106, C118: 4u7; C_0805_nomDensity; Manufacturer Part Number GRM21BZ7YA475KE15
C107, C108, C109, C114, C117, C119, C120, C121, C126, C129, C145: 100n; C_0402_nomDensity; Manufacturer Part Number GRM155R71H104KE14D
C115, C127: N/A; C_0402_nomDensity; not fitted
C116, C128: 100p; C_0402_nomDensity; Manufacturer Part Number GRM1555C1H101GA01D; not fitted
C130, C131, C132, C133, C134, C135, C137, C138, C139, C140, C141, C142: 4u7; C_1206_nomDesity; Manufacturer Part Number GRM31CR71H475KA12
C136, C143: 47u; CP_Elec_6.3x6_OS-CON-SVPK; Manufacturer Part Number 35SVPK47M
D101, D102, D103, D104: BAT54XV2T5G; D_SOD-523; Manufacturer Part Number BAT54XV2T5G
G101: SYM_Hot_Large; hot_surface
G102: SYM_ESD_Large; ESD-Logo_6.6x6mm_SilkScreen
G103: np_logo_5mm
L101: 1u; AMPLH5030S; Manufacturer Part Number AMPLH5030S-1R0MT
L102, L103: 10u; 744393665100; Manufacturer Part Number 744393665100
NT101: IN_SENSE+; NetTie-2_SMD_Pad0.15mm
NT102: IN_SENSE-; NetTie-2_SMD_Pad0.15mm
NT103, NT104: sw node; NetTie-2_SMD_Pad0.2mm
NT105: Vsense; NetTie-2_SMD_Pad0.2mm
Q101, Q103: BSZ018N04LS6; PG-TSDSON-8-26; Manufacturer Part Number BSZ018N04LS6ATMA1
Q102, Q104: IQE013N04LM6; PG-TSON-8-4; Manufacturer Part Number IQE013N04LM6ATMA1
R101: 5m; R_PA2512_R005-R006_YAGEO; Manufacturer Part Number PA2512FKE7W0R005E
R102, R103: 22R; R_0402_nomDensity; Manufacturer Part Number RC0402FR-1322RL
R104, R110: 21k5; R_0402_nomDensity; Manufacturer Part Number RC0402FR-0721K5L; not fitted
R105, R111: 100R; R_0402_nomDensity; Manufacturer Part Number RC0402FR-07100RL
R106, R112: 100k; R_0402_nomDensity; Manufacturer Part Number RC0402FR-07100KL
R107, R108, R113, R114: 2R21; R_0603_nomDensity; Manufacturer Part Numbe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 0603WAF221KT5E
R109, R115: N/A; R_0603_nomDensity; not fitted
R116, R118: 90k9; R_0603_nomDensity; Manufacturer Part Number RC0603FR-0790K9L
R117, R119: 10k; R_0603_nomDensity; Manufacturer Part Number RC0603FR-0710KL
TP101: Gate HS 1; TestPoint_Pad_D1.0mm_Bottom
TP102: Gate LS 1; TestPoint_Pad_D1.0mm_Bottom
TP103: Gate HS 2; TestPoint_Pad_D1.0mm_Bottom
TP104: Gate LS 2; TestPoint_Pad_D1.0mm_Bottom
TP105: Vin Filter; TestPoint_Pad_D1.0mm_Bottom
TP106: Switch-node 1; TestPoint_Pad_D1.0mm_Bottom
TP107: Switch-node 2; TestPoint_Pad_D1.0mm_Bottom
TP108: VREF1; TestPoint_Pad_D1.0mm_Bottom
TP109: VREF2; TestPoint_Pad_D1.0mm_Bottom
TP110: IL1; TestPoint_Pad_D1.0mm_Bottom
TP111: IL2; TestPoint_Pad_D1.0mm_Bottom
TP112: I_IN; TestPoint_Pad_D1.0mm_Bottom
TP113, TP114: GND; TestPoint_THTPad_1.0x1.0mm_Drill0.5mm
U101, U103: UCC27282DRC; 10-VSON(3x3)-DRC; Manufacturer Part Number UCC27282DRCT
U102, U104: ACS37030LLZATR-040B3; ACS37030LLZA; Manufacturer Part Number ACS37030LLZATR-040B3
U106: INA187A1IDBVR; SOT-23-6; Manufacturer Part Number INA187A1IDBVR

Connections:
+5V: R102.1; also elsewhere on the board
+9V: C106.1, C107.1, C118.1, C119.1, R104.2, R110.1, U101.1 (VDD), U103.1 (VDD); also elsewhere on the board
+S3V3: C117.1, C129.1, U102.6 (VDD), U104.6 (VDD); also elsewhere on the board
+VIN: C101.1, C102.1, C103.1, L101.1, NT102.2, R101.2, R118.1
/Top/MCU IOs/EN_CH1: R105.1, R106.1; also elsewhere on the board
/Top/MCU IOs/EN_CH2: R111.1, R112.1; also elsewhere on the board
/Top/MCU IOs/PWM_HS_CH1: U101.7 (HI); also elsewhere on the board
/Top/MCU IOs/PWM_HS_CH2: U103.7 (HI); also elsewhere on the board
/Top/MCU IOs/PWM_LS_CH1: U101.8 (LI); also elsewhere on the board
/Top/MCU IOs/PWM_LS_CH2: U103.8 (LI); also elsewhere on the board
/Top/Power Connectors/PWR_IN: NT101.2, R101.1; also elsewhere on the board
/Top/Power Connectors/PWR_OUT: C130.1, C131.1, C132.1, C133.1, C134.1, C135.1, C136.1, C137.1, C138.1, C139.1, C140.1, C141.1, C142.1, C143.1, NT105.1, U102.2 (IP-), U104.2 (IP-); also elsewhere on the board
/Top/Power State/DRV_GATE_HS1: D101.2 (A), Q101.4, R107.2, TP101.1 (1_1)
/Top/Power State/DRV_GATE_HS2: D103.2 (A), Q103.4, R113.2, TP103.1 (1_1)
/Top/Power State/DRV_GATE_LS1: D102.2 (A), Q102.4, R108.2, TP102.1 (1_1)
/Top/Power State/DRV_GATE_LS2: D104.2 (A), Q104.4, R114.2, TP104.1 (1_1)
/Top/Power State/DRV_HB1: C109.1, U101.3 (HB)
/Top/Power State/DRV_HB2: C121.1, U103.3 (HB)
/Top/Power State/DRV_HO1: D101.1 (K), R107.1, U101.4 (HO)
/Top/Power State/DRV_HO2: D103.1 (K), R113.1, U103.4 (HO)
/Top/Power State/DRV_HS1: C109.2, NT103.1, U101.5 (HS)
/Top/Power State/DRV_HS2: C121.2, NT104.1, U103.5 (HS)
/Top/Power State/DRV_LO1: D102.1 (K), R108.1, U101.10 (LO)
/Top/Power State/DRV_LO2: D104.1 (K), R114.1, U103.10 (LO)
/Top/Power State/EN1: C108.1, R104.1, R105.2, U101.6 (EN)
/Top/Power State/EN2: C120.1, R110.2, R111.2, U103.6 (EN)
/Top/Power State/I_INSE_VS: C145.1, R102.2, U106.6 (Vs)
/Top/Power State/I_IN_N: NT102.1, U106.4 (IN-)
/Top/Power State/I_IN_P: NT101.1, U106.3 (IN+)
/Top/Power State/I_IN_TR: R103.1, U106.1 (OUT)
/Top/Power State/PWR_SENSE_I_IN1: L102.2, U102.1 (IP+)
/Top/Power State/PWR_SENSE_I_IN2: L103.2, U104.1 (IP+)
/Top/Power State/PWR_SWNode_P1: C116.1, L102.1, NT103.2, Q101.1, Q102.8, R109.1, TP106.1 (1_1)
/Top/Power State/PWR_SWNode_P2: C128.1, L103.1, NT104.2, Q103.1, Q104.8, R115.1, TP107.1 (1_1)
/Top/Power State/SENSE_I_CH1: TP110.1 (1_1), U102.5 (VOUT); also elsewhere on the board
/Top/Power State/SENSE_I_CH2: TP111.1 (1_1), U104.5 (VOUT); also elsewhere on the board
/Top/Power State/SENSE_I_IN: R103.2, TP112.1 (1_1); also elsewhere on the board
/Top/Power State/SENSE_R_VOUT: NT105.2, R116.1
/Top/Power State/SENSE_VIN: R118.2, R119.1; also elsewhere on the board
/Top/Power State/SENSE_VOUT: R116.2, R117.1; also elsewhere on the board
/Top/Power State/SENSE_VREF1: TP108.1 (1_1), U102.4 (VREF)
/Top/Power State/SENSE_VREF2: TP109.1 (1_1), U104.4 (VREF)
GND: C101.2, C102.2, C103.2, C104.2, C105.2, C106.2, C107.2, C108.2, C110.2, C111.2, C112.2, C113.2, C114.2, C115.2, C116.2, C117.2, C118.2, C119.2, C120.2, C122.2, C123.2, C124.2, C125.2, C126.2, C127.2, C128.2, C129.2, C130.2, C131.2, C132.2, C133.2, C134.2, C135.2, C136.2, C137.2, C138.2, C139.2, C140.2, C141.2, C142.2, C143.2, C145.2, Q102.1, Q104.1, R106.2, R112.2, R117.2, R119.2, TP113.1 (1_1), TP114.1 (1_1), U101.9 (VSS), U101.11 (VSS), U102.3 (GND), U103.9 (VSS), U103.11 (VSS), U104.3 (GND), U106.2 (GND), U106.5 (REF); also elsewhere on the board
unnamed: C115.1, R109.2
unnamed: C127.1, R115.2
PWR_VIN_FILT: C104.1, C105.1, C110.1, C111.1, C112.1, C113.1, C114.1, C122.1, C123.1, C124.1, C125.1, C126.1, L101.2, Q101.8, Q103.8, TP105.1 (1_1)

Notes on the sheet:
Ø6.3mm
R_{G}= 0R9
Current Sensor
ESD Sensitive
10:1
Place C104 and C105 near phase 1 and phase 2, respectively.
GRT32ER71H475KE01L
Hot surface
For Output Cap.
PHASE 1
-33%
Output Capacitor 4.7uFx12 Derating -15.6% @12VDC = 47.6uF
[${#}] ${COMMENT1}
GRT32ER71H475KE01 (Murata MLCC 4u7 50V) DC-Bias vs Capacitance Derating
±1%
±3%
GRT32ER71H475KE01
R_{T} = 9 x R_{B}
A1's GAIN: 20V/V I = 1/20 x Vout/0.005
10A
24V
Output Voltage Sense
Input Filter
GRM31CR71H475KA12 (Murata MLCC 4u7 50V) Capacitance Derating vs DC-Bias
C_{snub} = (4~8) C_{par}
R_{snub} = 1/Q [ sqrt( L_{par} / C_{snub} ) ]
R_{G}= 1R3
I_{IN} Sense
-15.6%
Input Voltage Sense
15m DCR
NP LOGO 5mm
GRM31CR71H475KA12
5m6 DCR
L_{par} = 1 / [ 2pi f_{1} C_{par} ]
Z_{Filter Out} Peak -13.78dB @28kHz <Atten. -20.5dB @ 200kHz
PHASE 2
Test Point
Total ESR 0.196 ohm
12V

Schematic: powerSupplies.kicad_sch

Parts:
C301, C303, C310, C312: 4u7; C_1210_nomDensity; Manufacturer Part Number GRT32ER71H475KE01L
C302, C311: 22u; CP_Elec_5x5.5_WCAP-ASLI; Manufacturer Part Number 865080542006
C304, C305, C306, C313, C314, C315, C320, C323, C325, C328, C329: 100n; C_0402_nomDensity; Manufacturer Part Number GRM155R71H104KE14D
C307, C308, C309, C316, C317, C318: 4u7; C_0805_nomDensity; Manufacturer Part Number GRM21BZ7YA475KE15
C319, C321, C322, C324, C326, C327: 2u2; C_0603_nomDensity; Manufacturer Part Number GRM188Z71C225KE43
D301: BAT60JFILM; D_SOD-323; Manufacturer Part Number BAT60JFILM; not fitted
L301, L303: 2u2; L_0806_BDCD00201610; Manufacturer Part Number BDCD002016102R2MS1
L302, L304: 22u; AMDLA4020S; Manufacturer Part Number AMDLA4020S-220MT
LD301: Green; LED_0603_1608Metric; Manufacturer Part Numbe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 LTST-C191TGKT
NT303, NT304, NT305: EN; NetTie-2_SMD_Pad0.15mm
R301, R302: 20m; R_PA1206_R004-R020_YAGEO; Manufacturer Part Number PA1206FRE070R02Z
R303: 162k; R_0402_nomDensity; Manufacturer Part Number RC0402FR-07162KL
R304, R306, R308, R310: 21k5; R_0402_nomDensity; Manufacturer Part Number RC0402FR-0721K5L
R305: 221k; R_0402_nomDensity; Manufacturer Part Number RC0402FR-07221KL
R307: 110k; R_0402_nomDensity; Manufacturer Part Number RC0402FR-07110KL
R309: 118k; R_0402_nomDensity; Manufacturer Part Number RC0402FR-07118KL
R311, R313: 0R; R_0603_nomDensity; Manufacturer Part Number RC0603JR-070RL
R312: 5k11; R_0402_nomDensity; Manufacturer Part Number RC0402FR-135K11L
TP301: +9V; TestPoint_NoSlik_D1.0mm_Top
TP302: +5V; TestPoint_NoSlik_D1.0mm_Top
TP303: +USB; TestPoint_NoSlik_D1.0mm_Bottom
TP304: +3V3; TestPoint_NoSlik_D1.0mm_Top
TP305: +A3V3; TestPoint_NoSlik_D1.0mm_Bottom
TP306: +S3V3; TestPoint_NoSlik_D1.0mm_Bottom
TP307: GND; TestPoint_THTPad_1.0x1.0mm_Drill0.5mm
U301, U302: LMR54410DBVR; SOT-23-6; Manufacturer Part Number LMR54410DBVR
U303, U304: SPX3819M5-L-3-3/TR; SOT-23-5; Manufacturer Part Number SPX3819M5-L-3-3/TR
U305: LDLN025M33R; SOT-23-5; Manufacturer Part Number LDLN025M33R
U306: LM66100DCK; DCK0006A_TI; Manufacturer Part Number LM66100DCK

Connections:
+3V3: C321.1, TP304.1 (1_1), U303.5 (OUT); also elsewhere on the board
+5V: C315.1, C316.1, C317.1, C318.1, C319.1, C322.1, C325.1, L304.2, NT303.1, NT304.1, R309.1, R311.1, R312.1, R313.2, TP302.1 (1_1), U303.1 (IN), U304.1 (IN); also elsewhere on the board
+9V: C306.1, C307.1, C308.1, C309.1, L302.2, R305.1, TP301.1 (1_1); also elsewhere on the board
+A3V3: C327.1, TP305.1 (1_1), U305.5 (OUT); also elsewhere on the board
+S3V3: C324.1, TP306.1 (1_1), U304.5 (OUT); also elsewhere on the board
+VUSB: C328.1, D301.2 (A), TP303.1 (1_1), U306.1 (VIN); also elsewhere on the board
/Top/Power Connectors/PWR_IN: R301.1, R302.1; also elsewhere on the board
/Top/Power Supplies/5V_SW: C314.2, L304.1, U302.6 (SW)
/Top/Power Supplies/5V_VIN: C310.1, L303.1, R302.2
/Top/Power Supplies/5V_VIN__FILT: C311.1, C312.1, C313.1, L303.2, R307.1, U302.5 (VIN)
/Top/Power Supplies/9V_SW: C305.2, L302.1, U301.6 (SW)
/Top/Power Supplies/9V_VIN: C301.1, L301.1, R301.2
/Top/Power Supplies/9V_VIN__FILT: C302.1, C303.1, C304.1, L301.2, R303.1, U301.5 (VIN)
/Top/Power Supplies/+5VUSB: C329.1, D301.1 (K), R313.1, U306.3 (~CE), U306.6 (VOUT)
/Top/Power Supplies/A3V3_IN: C326.1, NT305.1, R311.2, U305.1 (IN)
/Top/Power Supplies/BP_3V3: C320.1, U303.4 (BP)
/Top/Power Supplies/BP_3V3_S: C323.1, U304.4 (BP)
/Top/Power Supplies/BUS_LED_A: LD301.2 (A), R312.2
/Top/Power Supplies/CB_5V: C314.1, U302.1 (CB)
/Top/Power Supplies/CB_9V: C305.1, U301.1 (CB)
/Top/Power Supplies/EN_3V3: NT303.2, U303.3 (EN)
/Top/Power Supplies/EN_3V3_S: NT304.2, U304.3 (EN)
/Top/Power Supplies/EN_5V: R307.2, R308.1, U302.4 (EN)
/Top/Power Supplies/EN_9V: R303.2, R304.1, U301.4 (EN)
/Top/Power Supplies/EN_A3V3: NT305.2, U305.3 (EN)
/Top/Power Supplies/FB_5V: R309.2, R310.1, U302.3 (FB)
/Top/Power Supplies/FB_9V: R305.2, R306.1, U301.3 (FB)
GND: C301.2, C302.2, C303.2, C304.2, C306.2, C307.2, C308.2, C309.2, C310.2, C311.2, C312.2, C313.2, C315.2, C316.2, C317.2, C318.2, C319.2, C320.2, C321.2, C322.2, C323.2, C324.2, C325.2, C326.2, C327.2, C328.2, C329.2, LD301.1 (K), R304.2, R306.2, R308.2, R310.2, TP307.1 (1_1), U301.2 (GND), U302.2 (GND), U303.2 (GND), U304.2 (GND), U305.2 (GND), U306.2 (GND); also elsewhere on the board

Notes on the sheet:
[${#}] ${COMMENT1}
STpin Open-Drain EN :HI-Z DIS :LOW
LDO 3V3 500mA (Digital path)
LDO 3V3 500mA (Sensor path)
R_{p} = Z_{0}^{2} / DCR
R_{d} = 0.71Ohm, Q=0.7
On Page 1
Z_{Filter Out}Peak -2dB @63.3kHz <Atten. -48.4dB @ 1MHz
R_{p} = 0.84^{2} / 0.2 = 3.528
LDO 3V3 250mA (Analog path)
Reverse Current Blocking
LED Indicators
R_{d} = Z_{0}^{2} / ( Z_{0}/Q - DCR )
*Enable when V_{IN} is above 11V
R_{total} = R_{p} // R_{d}
R_{Eq}Parallel of DCR @ f_{0}
EN: +VUSB > +5V
Q = R_{total} / Z_{0}
Buck Converter 5V 1A (1.1MHz)
10mcd @ 0.5mA
0.2DCR
PWR
Test Point
*Enable when V_{IN} is above 7V
Vf = 2.7V
Buck Converter 9V 1A (1.1MHz)
Determine R_{d} = 1.1Ohm, Q=1
Output Capacitor C_{OUT} > 0.5 x (8 x I)/(f x DeltaVo) > 0.5x(8x0.6)/(1.1Meg x 0.2) C_{OUT} > 11uF , Transient Load (0.6A) Derated -44% @9V = 2.79uF 3x3.79 = 8.37uF
DESIGN NOTE: C_{d}=5*C=18uF Z_{0} = sqrt(L/C) =sqrt(2.2/3.1)=0.84ohm
DESIGN NOTE: The EN rising threshold is 1.23V The EN falling threshold is 1.1V When V_{EN} pin is below 0.95V(min) the device is in shutdown mode.
R_{ENT}=((V/1.23)-1) x R_{ENB} =((10.5/1.23)-1) x 21.5k = 162.03k => 162k Ohm EN = ((21.5+162)/21.5)x1.23 = 10.49V DIS = ((21.5+162)/21.5)x1.1 = 9.38V
Derated -19.1% @5V = 4.03uF 3x4.03u = 12uF
Feeback Resistor R_{FBT} = ((V_{OUT}-V_{REF})/ V_{REF}) x R_{FBB} = ((9 - 0.8)/ 0.8) x 22.5k = ~220.3k Ohm V_{OUT} = V_{REF} x (1 + R_{FBT}/R_{FBB}) = 0.8 x (1 + (221/22.5)) = 9.023V
Feedback Resistot R_{FBT} = ((V_{OUT}-V_{REF})/ V_{REF}) x R_{FBB} = ((5 - 0.8)/ 0.8) x 21.5k = 116k Ohm V_{OUT} = V_{REF} x (1 + R_{FBT}/R_{FBB}) = 0.8 x (1 + (118/22.5)) = 5.19V
<Target 18uF ESR 1.1ohm> Used E.CAP(22uF, ESR 1ohm) x1 for stability
LAYOUT NOTE: Place this power supply near the current sensor
R_{ENT}=((V/1.23)-1) x R_{ENB} =((7/1.23)-1) x 21.5k = 100.8k => 100k Ohm EN = ((21.5+100)/21.5)x1.23 = 6.95V DIS = ((21.5+100)/21.5)x1.1 = 6.27V
Derated -13.7% @3V3 = 1.98uF

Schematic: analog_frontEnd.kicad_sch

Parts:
C601, C602, C603, C604, C605: 1n; C_0402_nomDensity; Manufacturer Part Number GRM1555C1H102JA01D
C606, C607: 100n; C_0402_nomDensity; Manufacturer Part Number GRM155R71H104KE14D
R601, R602, R603, R605: 49R9; R_0402_nomDensity; Manufacturer Part Number RC0402FR-1349R9L
R604: 100R; R_0402_nomDensity; Manufacturer Part Number RC0402FR-07100RL
TP601: Analog Vout; TestPoint_NoSlik_D0.5mm_Top
TP602: Analog VIN; TestPoint_NoSlik_D0.5mm_Bottom
TP603: GND; TestPoint_NoSlik_D0.5mm_Top
TP604: GND; TestPoint_NoSlik_D0.5mm_Bottom
U601, U602: TLV9061IDBVR; SOT-23-5; Manufacturer Part Number TLV9061IDBVR

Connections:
+A3V3: C606.1, C607.2, U601.5 (V+), U602.5 (V+); also elsewhere on the board
/Top/Analog Front-End/OP_FB_VIN: R605.1, U602.1, U602.4 (-)
/Top/Analog Front-End/OP_FB_VO: R603.1, U601.1, U601.4 (-)
/Top/MCU IOs/ADC1_I_CH1: C601.1, R601.2; also elsewhere on the board
/Top/MCU IOs/ADC2_I_CH2: C602.1, R602.2; also elsewhere on the board
/Top/MCU IOs/ADC3_VOUT: C603.1, R603.2, TP601.1 (1_1); also elsewhere on the board
/Top/MCU IOs/ADC4_I_IN: C604.1, R604.2; also elsewhere on the board
/Top/MCU IOs/ADC4_VIN: C605.1, R605.2, TP602.1 (1_1); also elsewhere on the board
/Top/Power State/SENSE_I_CH1: R601.1; also elsewhere on the board
/Top/Power State/SENSE_I_CH2: R602.1; also elsewhere on the board
/Top/Power State/SENSE_I_IN: R604.1; also elsewhere on the board
/Top/Power State/SENSE_VIN: U602.3 (+); also elsewhere on the board
/Top/Power State/SENSE_VOUT: U601.3 (+); also elsewhere on the board
GND: C601.2, C602.2, C603.2, C604.2, C605.2, C606.2, C607.1, TP603.1 (1_1), TP604.1 (1_1), U601.2 (V-), U602.2 (V-); also elsewhere on the board

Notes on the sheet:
ADC1, 2 (48.571429MHz) 12-Bit Res.
R_{AIN (MAX)} = 39k
Input Current Path (Low Speed)
R_{AIN (MAX)} = 100R
t_{ACQ} = 2.5 Cycle = 58.8ns
Z_{sense} = 9kOhm
t_{ACQ} = 640.5 Cycle = 15.07us
t_{settling} = ~450ns
[${#}] ${COMMENT1}
C_{ADC} = 10pF
ADC4 (42.5MHz) 12-Bit Res.
t_{ACQ} = 2.5 Cycle = 51.47ns
Output Voltage Path (High Speed)
Current Path (High Speed)
, Error < 0.02%
Input Voltage Path (Low Speed)
ADC3 (42.5MHz) 12-Bit Res.
t_{settling} = ~9 x RC
t_{settling} = ~1us
LAYOUT NOTE: Placing OpAmp and RC Filter close to the ADC input or Analog Zone
LAYOUT NOTE: Rount away from magnetic compenents

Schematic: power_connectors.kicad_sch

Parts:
C201: 1u; C_0805_nomDensity; Manufacturer Part Numbe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 CL21B105KBFNNNE
CN201, CN202, CN203, CN204: 04A2; Molex_Mini-Fit_Jr_5569-04A2_2x02_P4.20mm_Horizontal; Manufacturer Part Number 10127819-04211LF
CN205: SMA-J-P-H-ST-EM1; SMA_Samtec_SMA-J-P-H-ST-EM1_EdgeMount
D201, D202: SMF4L28A; D_SOD-123FL; Manufacturer Part Number SMF4L28A
R201: 1k; R_1206_YEGEO; Manufacturer Part Number AC1206FR-7W1KL
R202: 49R9; R_0402_nomDensity; Manufacturer Part Number RC0402FR-1349R9L

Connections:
/Top/Power Connectors/CP_C_R: C201.2, R202.2
/Top/Power Connectors/CP_R_SMA: CN205.1 (In), R202.1
/Top/Power Connectors/PWR_IN: CN201.3, CN201.4, CN202.3, CN202.4, D201.1; also elsewhere on the board
/Top/Power Connectors/PWR_OUT: C201.1, CN203.3, CN203.4, CN204.3, CN204.4, D202.1, R201.1; also elsewhere on the board
GND: CN201.1, CN201.2, CN202.1, CN202.2, CN203.1, CN203.2, CN204.1, CN204.2, CN205.2 (Ext), D201.2, D202.2, R201.2; also elsewhere on the board

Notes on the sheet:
x2 Probe
[${#}] ${COMMENT1}
30V 20A MAX
10127819-04211LF
Input Connector
For Ripple Measurement
Molex Mini-Fit Jr 5569-04A2 or equivalent.
30V 20A MAX
Output Connector
Output AC Coupling
Place TVS Diode close the Connector

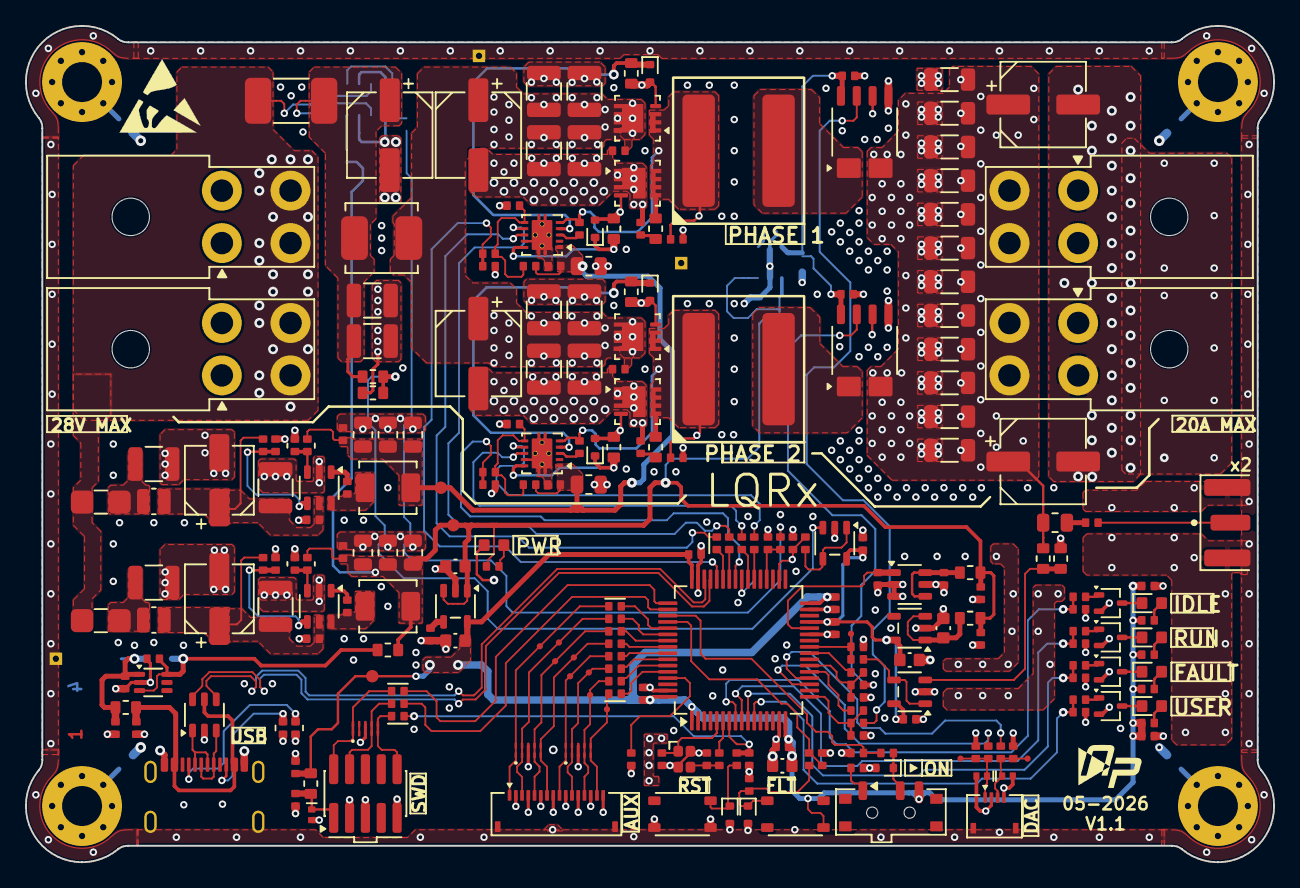
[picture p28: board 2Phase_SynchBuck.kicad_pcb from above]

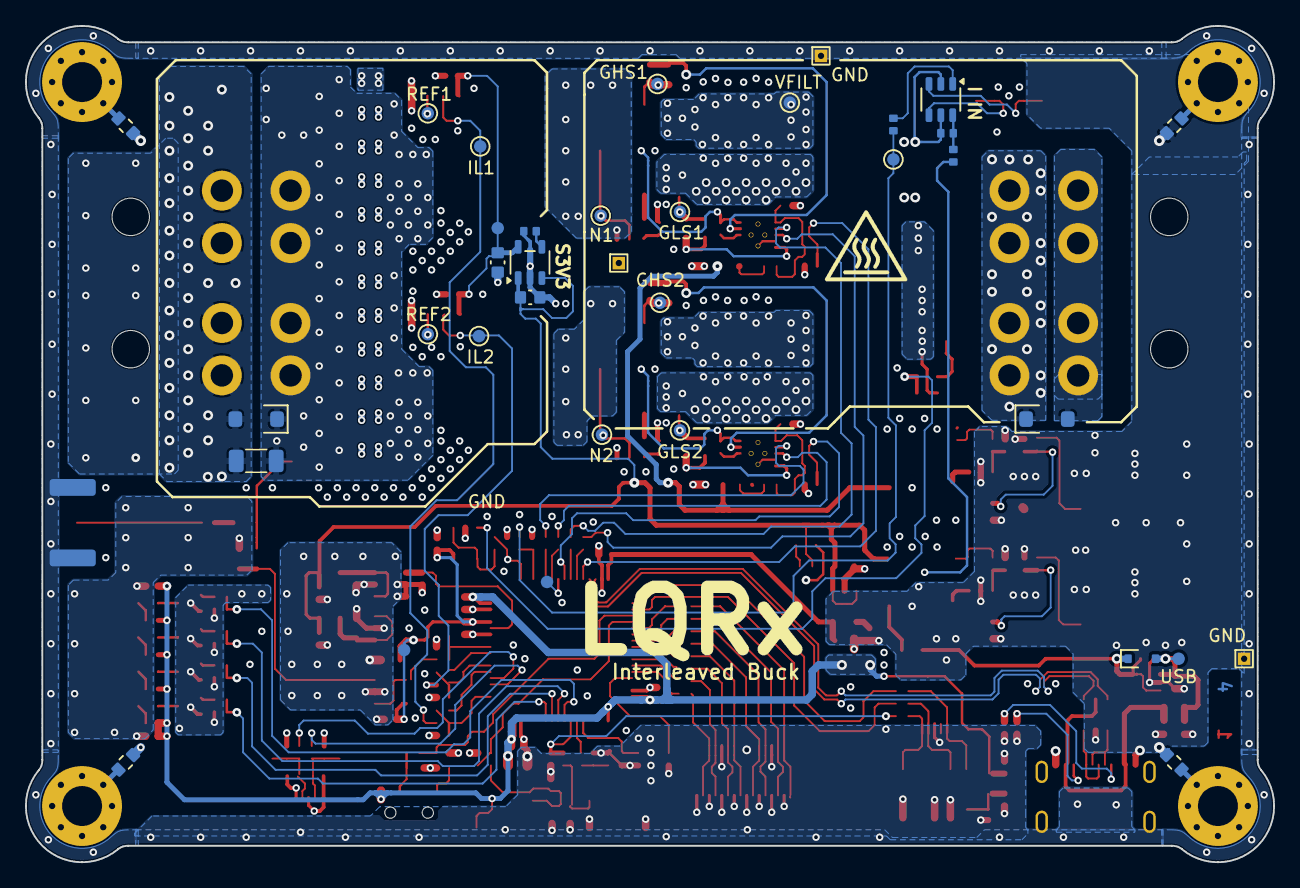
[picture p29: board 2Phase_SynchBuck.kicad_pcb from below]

Board: 4 copper layers, 100.0 x 67.0 mm, 305 parts (41 on the bottom side), 152 nets.

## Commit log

2026-05-27 Added Kicad templates
2026-05-27 Added Schematic Files
    [2Phase_SynchBuck.kicad_sch, Block_diagram.kicad_sch, Interface_interconnects.kicad_sch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]
2026-05-27 Added board2pdf configs
2026-05-27 Added PCB files
2026-05-29 Render PCB v1.0 Top and BOT View
2026-05-29 Update sch v1.0
    [2Phase_SynchBuck.kicad_sch, Block_diagram.kicad_sch, RevHistory.kicad_sch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]
2026-05-29 Modified part number
    Added 2nd Supplier
    Added 2nd Mfr, Mfr NO.
    [Interface_interconnects.kicad_sch, MCU_IOs.kicad_sch, MCU_power.kicad_sch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]
2026-05-29 Create BOM_2Phase_SynchBuck_v1.0_2026-05-29.csv
    Export BOM v1.0 2026-05-29
    [BOM_2Phase_SynchBuck_v1.0_2026-05-29.csv]
2026-05-29 Updated template in sch
    [2Phase_SynchBuck.kicad_sch, Interface_interconnects.kicad_sch, analog_frontEnd.kicad_sch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]
2026-06-03 Updated Schematic v1.0
    [2Phase_SynchBuck.kicad_pcb, 2Phase_SynchBuck.kicad_sch, Interface_interconnects.kicad_sch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]
2026-06-03 Create LQRx_2PBuck-V1-Gerber-03062026.zip
    Released PC Board v1.0
2026-06-03 Rename schematic file
2026-06-07 Update 2Phase_SynchBuck.kicad_pcb
    Restored outer via annular ring
    [2Phase_SynchBuck.kicad_pcb]
2026-06-12 Enhance README with features and specifications
    Updated README.md to include key features, specifications, and control implementation details for the Digitally Controlled Interleaved Buck Converter.
2026-06-28 Rev1.1
    - Removed the Mosfet that Enable the ICs Gate Driver (p.1)
    - Changed ADC input Capacitor 47pF to 1nF. (p.6
    [2Phase_SynchBuck.kicad_pcb, 2Phase_SynchBuck.kicad_sch, Block_diagram.kicad_sch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]
2026-06-28 Update 2Phase_SynchBuck.kicad_pro
    Changed Date
2026-09-02 Update revision
    - Shc.
    - Render images
    [2Phase_SynchBuck.kicad_sch, RevHistory.kicad_sch, analog_frontEnd.kicad_sch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]
2026-09-13 Update 2Phase_SynchBuck.kicad_pcb
    Change TP? Description
    [2Phase_SynchBuck.kicad_pcb]
2026-10-09 Migrate Symbol Librarys
    [BOM_2Phase_SynchBuck_v1.0_2026-06-03.csv, Interface_interconnects.kicad_sch, MCU_IOs.kicad_sch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]
2026-10-09 Update license from Apache 2.0 to CERN OHL v2
    Replaced Apache License 2.0 with CERN Open Hardware Licence Version 2 - Weakly Reciprocal. Updated terms and conditions to reflect the new licensing framework.
